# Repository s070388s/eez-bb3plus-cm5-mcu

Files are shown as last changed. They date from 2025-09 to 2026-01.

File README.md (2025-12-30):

### This is a WORK IN PROGRESS!

---

### Ownership and License
The contributors are listed in CONTRIB.TXT. 

### Overview

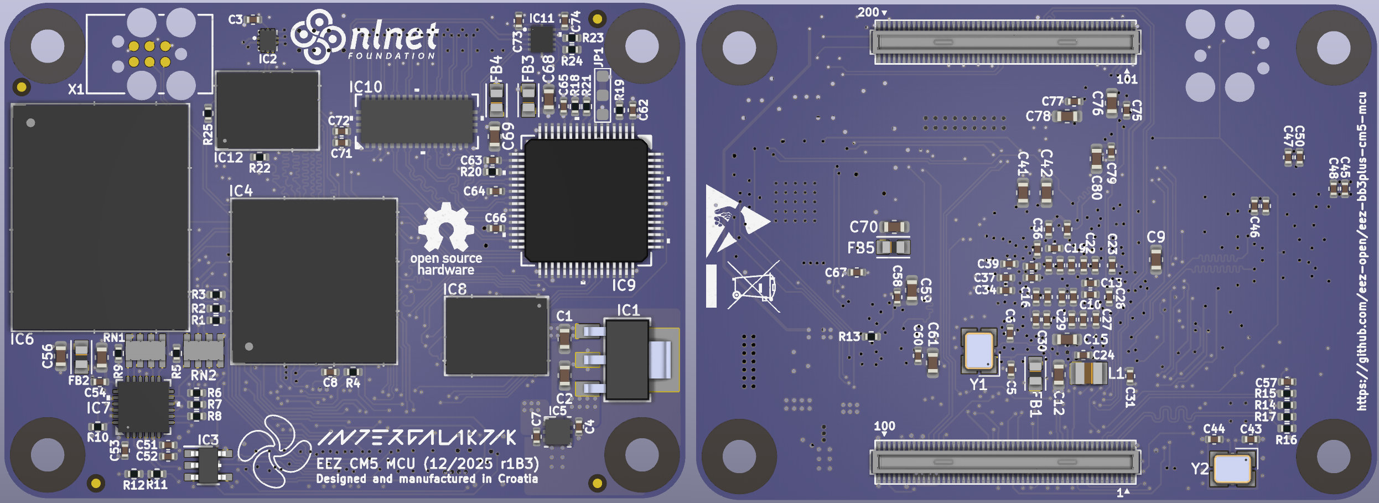
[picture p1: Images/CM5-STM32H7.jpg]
3D model


The MCU module uses a high performance STM32 MCU and is pin compatible with Raspberry Pi CM5. The MCU cannot generate an HDMI compatible signal, so a TI TFP410 is used to convert 24-bit RGB to HDMI compatible signal. Since the BB3+ offers dual display: a built-in 5" TFT touchscreen and an external monitor, a 1:2 high speed mux (TS3DV642) is used for destination selection.

### Feature list

* [Raspberry Pi CM5](https://www.raspberrypi.com/products/compute-module-5) form factor (55 x 45 mm)
* [STM32H7R7L8H6H](https://www.st.com/en/microcontrollers-microprocessors/stm32h7r7l8.html) 32-bit High-Performance Arm Cortex-M7 MCU, 600 MHz, NeoChrom GPU
* 32 MB PSRAM
* 32 MB Flash memory
* 4 GB eMMC (100-pin FBGA)
* Two USB ports (1x FS with 1:2 Mux , 1x FS/HS)
* 10/100 Mbps Ethernet
* 24-bit color video output with 1:2 MUX (HDMI® compatible)
* 6-layer PCB (without buried/blind vias)

### Related topics and links

* Intergalaktik [BB3-CM4](https://intergalaktik.eu/projects/bb3-cm4)
* [EEZ BB3+](https://github.com/eez-open/eez-bb3plus)
* [DIB DCP405+](https://github.com/eez-open/dib-dcp405plus) power module
* [EEZ BB3](https://github.com/eez-open/modular-psu)
* [EEZ Studio](https://www.envox.eu/studio/studio-introduction)
* [Discord](https://discord.com/invite/q5KAeeenNG) server
* [X](https://x.com/envox) (ex Twitter)
* [YouTube](https://www.youtube.com/c/eezopen) channel
* [EEVblog forum](https://www.eevblog.com/forum/projects/eez-h25005-a-possible-successor-of-eez-h24005-programmable-power-supply/) discussion

---

This work is financed by [NLnet](https://nlnet.nl/project/BB3-CM5/) foundation

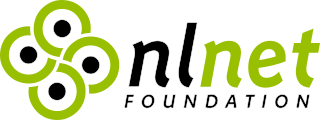
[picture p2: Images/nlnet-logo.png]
nlnet


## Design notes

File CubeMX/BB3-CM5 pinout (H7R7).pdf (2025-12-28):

BB3+ CM5 STM32H7R7 pinout

Pin Nb | PINs | FUNCTIONs | LABELs | NOTE
A2 | PE0 | GPIO_EXTI0 | SYSMCU_IRQ
A3 | PF3 | GPIO_EXTI3 | DIB3_IRQ
A4 | PF2 | GPIO_EXTI2 | DIB2_IRQ
A5 | PG3 | GPIO_Output | DIB_OE_SYNC
A7 | PM12 | USB_OTG_FS_DM
A9 | PM6 | USB_OTG_HS_DP
A10 PM3 | | GPIO_Output | DIB3_CSA
A12 PD3 | | LTDC_B1
A13 PE14 | | SPI4_MOSI | DIB2/DIB5_MOSI
A14 PD2 | | SDMMC1_CMD
B1 | PB8 | SDMMC1_D4
B2 | PE2 | SPI4_SCK | DIB2/DIB5_SCK
B3 | PB5 | LTDC_R2
B4 | PF4 | GPIO_EXTI4 | DIB4_IRQ
B5 | PF0 | I2C2_SDA | SDA
B6 | PD7 | ETH_RMII_REF_CLK
B7 | PM11 | USB_OTG_FS_DP
B8 | PM9 | USB_OTG_HS_ID
B9 | PM5 | USB_OTG_HS_DM
B10 PM2 | GPIO_Input | DIN2
B11 PG0 | | LTDC_R7
B12 PE13 | | SPI4_MISO | DIB2/DIB5_MISO
B13 PD1 | | UART4_TX | RS485_TX/DOUT3
B14 PC10 | | SDMMC1_D2
B15 PC11 | | SDMMC1_D3
C2 | PB9 | SDMMC1_D5
C4 | PB3(JTDO/TRACESWO) | LTDC_R4
C5 | PF1 | I2C2_SCL | SCL
C6 | PG2 | LTDC_HSYNC
C7 | PM13 | SPI5_MOSI | DIB4_MOSI
C8 | PM14 | SPI5_MISO | DIB4_MISO
C9 | PM8 | USB_OTG_HS_VBUS
C12 PE11 | | LTDC_VSYNC
C13 PD0 | | UART4_RX | RS485_RX/DIN3
C14 PA12 | | SPI2_SCK | DIB1/DIB3_SCK
C15 PA11 | | LTDC_B3
D2 | PC14-OSC32_IN(OSC32_IN) RCC_OSC32_IN
D4 | PB7 | ETH_RMII_TXD1
D5 | PB4(NJTRST) | SPI2_NSS | DIB1_CSA
D7 | PD5 | GPIO_EXTI5 | DIB5_IRQ
D11 PE15 | | GPIO_Output | LCD_ON
D12 PC12 | | SDMMC1_CK
D13 PA14(JTCK/SWCLK) | DEBUG_JTCK-SWCLK | SWCLK
D14 PA9 | | LTDC_B5
D15 PC8 | | SDMMC1_D0
E1 | PE6 | GPIO_Output | DIB5_CSA
E2 | PE4 | SPI4_NSS | DIB2_CSA
E5 | PB6* | CEC | DVID_CEC
E7 | PD6 | ETH_CLK
E10 PG1 | | LTDC_R6
E11 PE12 | | GPIO_EXTI12 | DVID_HPA
E12 PA13(JTMS/SWDIO) | DEBUG_JTMS-SWDIO | SWDIO
E13 PA10 | | LTDC_B4
E14 PC9 | | SDMMC1_D1
E15 PC6 | | SDMMC1_D6
F1 | PG14 | GPIO_Output | SYSMCU_CS
F2 | PG12 | LTDC_G1

F3 | PG11 | ETH_RMII_TX_EN
F12 PA8 | LTDC_B6
F13 PC7 | SDMMC1_D7
F14 PN1 | XSPIM_P2_NCS1
G5 PG13 | ETH_RMII_TXD0
G11 PA15(JTDI) | LTDC_R5
G13 PN3 | XSPIM_P2_IO1
G14 PN0 | XSPIM_P2_DQS0
G15 PN11 | XSPIM_P2_IO7
H4 | PF7 | UART7_TX | UART_TX/DOUT1
H5 | PF6 | SPI5_NSS | DIB4_CSA
H13 PN10 | XSPIM_P2_IO6
H14 PN9 | XSPIM_P2_IO5
H15 PN2 | XSPIM_P2_IO0
J2 | PF9 | LTDC_R0
J3 | PF10 | LTDC_R1
J14 PN6 | XSPIM_P2_CLK
K1 | PH0-OSC_IN(PH0) | RCC_OSC_IN
K2 | PH1-OSC_OUT(PH1) | RCC_OSC_OUT
K13 PN8 | XSPIM_P2_IO4
K14 PN4 | XSPIM_P2_IO2
K15 PN5 | XSPIM_P2_IO3
L1 | PC1 | ETH_MDC
L2 | PC2 | SPI2_MISO | DIB1/DIB3_MISO
L3 | PC3 | SPI2_MOSI | DIB1/DIB3_MOSI
L4 | PA2 | ETH_MDIO
L5 | PC4 | ETH_RMII_RXD0
L12 PB12 | LTDC_G5
L14 PD14 | GPIO_Output | USB_FS_SEL
M1 PA0 | LTDC_G3
M2 PA1 | LTDC_G2
M3 PA4 | LTDC_R3
M4 PA7 | ETH_RMII_CRS_DV
M5 PF11 | LTDC_B0
M6 PE7 | UART7_RX | UART_RX/DIN1
M11 PO3 | XSPIM_P1_DQS1
M12 PP10 | XSPIM_P1_IO10
M13 PB14 | UART4_DE | RS485_TX_EN/DOUT2
M14 PB15 | LTDC_G7
N1 | PA3 | LTDC_DE
N2 | PA5 | LTDC_CLK
N3 | PC5 | ETH_RMII_RXD1
N4 | PB2 | LTDC_B2
N5 | PF15 | SPI5_SCK | DIB4_SCK
N6 | PP12 | XSPIM_P1_IO12
N7 | PP14 | XSPIM_P1_IO14
N9 | PP2 | XSPIM_P1_IO2
N10 PP5 | XSPIM_P1_IO5
N11 PO2 | XSPIM_P1_DQS0
N12 PP1 | XSPIM_P1_IO1
N14 PB11 | LTDC_G6
N15 PB13 | LTDC_G4
P1 | PA6 | LTDC_B7
P2 | PB0 | GPIO_Output | DVID_SEL1
P3 | PF13 | GPIO_Output | DVID_SEL2
P4 | PF14 | LTDC_G0
P6 | PP11 | XSPIM_P1_IO11
P8 | PP15 | XSPIM_P1_IO15

P9 | PP3 | XSPIM_P1_IO3
P11 PP0 | XSPIM_P1_IO0
P12 PP7 | XSPIM_P1_IO7
P13 PP8 | XSPIM_P1_IO8
P15 PB10 | ETH_MII_RX_ER
R2 | PB1 | GPIO_EXTI1 | DIB1_IRQ
R4 | PE8 | GPIO_EXTI8 | TFT_IRQ
R5 | PE10 | GPIO_Output | LED_nACT
R7 | PP13 | XSPIM_P1_IO13
R8 | PP4 | XSPIM_P1_IO4
R10 PO4 | XSPIM_P1_CLK
R11 PP6 | XSPIM_P1_IO6
R13 PO0 | XSPIM_P1_NCS1
R14 PP9 | XSPIM_P1_IO9

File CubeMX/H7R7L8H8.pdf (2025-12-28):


28/12/2025

## H7R7L8H8 Project Configuration Report

# 1. Description

## 1.1. Project

Project Name | H7R7L8H8
Board Name | custom
Generated with: | STM32CubeMX 6.16.0
Date | 12/28/2025

## 1.2. MCU

MCU Series | STM32H7RS
MCU Line | STM32H7R7/7S7
MCU name | STM32H7R7L8HxH
MCU Package | TFBGA225 HEXA SMPS
MCU Pin number | 225

## 1.3. Core(s) information

Core(s) | ARM Cortex-M7

# 2. Pinout Configuration

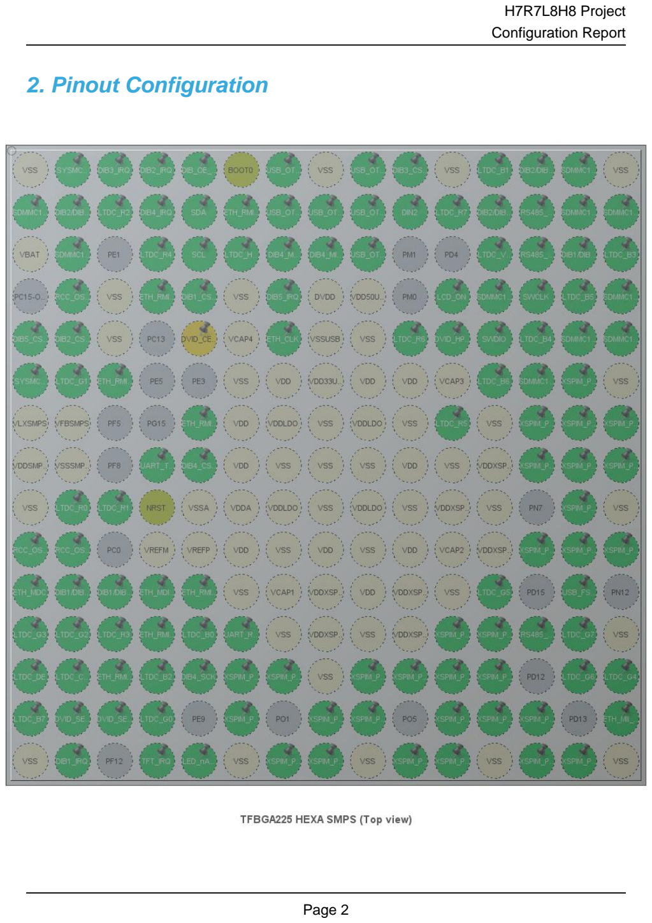
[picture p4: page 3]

# 3. Pins Configuration

Pin Number TFBGA225 HEXA SMPS | Pin Name (function after reset) | Pin Type | Alternate Function(s) | Label
A1 | VSS | Power
A2 | PE0 | I/O | GPIO_EXTI0 | SYSMCU_IRQ
A3 | PF3 | I/O | GPIO_EXTI3 | DIB3_IRQ
A4 | PF2 | I/O | GPIO_EXTI2 | DIB2_IRQ
A5 | PG3 * | I/O | GPIO_Output | DIB_OE_SYNC
A6 | BOOT0 | Boot
A7 | PM12 | I/O | USB_OTG_FS_DM
A8 | VSS | Power
A9 | PM6 | I/O | USB_OTG_HS_DP
A10 | PM3 * | I/O | GPIO_Output | DIB3_CSA
A11 | VSS | Power
A12 | PD3 | I/O | LTDC_B1
A13 | PE14 | I/O | SPI4_MOSI | DIB2/DIB5_MOSI
A14 | PD2 | I/O | SDMMC1_CMD
A15 | VSS | Power
B1 | PB8 | I/O | SDMMC1_D4
B2 | PE2 | I/O | SPI4_SCK | DIB2/DIB5_SCK
B3 | PB5 | I/O | LTDC_R2
B4 | PF4 | I/O | GPIO_EXTI4 | DIB4_IRQ
B5 | PF0 | I/O | I2C2_SDA | SDA
B6 | PD7 | I/O | ETH_RMII_REF_CLK
B7 | PM11 | I/O | USB_OTG_FS_DP
B8 | PM9 | I/O | USB_OTG_HS_ID
B9 | PM5 | I/O | USB_OTG_HS_DM
B10 | PM2 * | I/O | GPIO_Input | DIN2
B11 | PG0 | I/O | LTDC_R7
B12 | PE13 | I/O | SPI4_MISO | DIB2/DIB5_MISO
B13 | PD1 | I/O | UART4_TX | RS485_TX/DOUT3
B14 | PC10 | I/O | SDMMC1_D2
B15 | PC11 | I/O | SDMMC1_D3
C1 | VBAT | Power
C2 | PB9 | I/O | SDMMC1_D5
C4 | PB3(JTDO/TRACESWO) | I/O | LTDC_R4
C5 | PF1 | I/O | I2C2_SCL | SCL
C6 | PG2 | I/O | LTDC_HSYNC
C7 | PM13 | I/O | SPI5_MOSI | DIB4_MOSI

Pin Number TFBGA225 HEXA SMPS | Pin Name (function after reset) | Pin Type | Alternate Function(s) | Label
C8 | PM14 | I/O | SPI5_MISO | DIB4_MISO
C9 | PM8 | I/O | USB_OTG_HS_VBUS
C12 | PE11 | I/O | LTDC_VSYNC
C13 | PD0 | I/O | UART4_RX | RS485_RX/DIN3
C14 | PA12 | I/O | SPI2_SCK | DIB1/DIB3_SCK
C15 | PA11 | I/O | LTDC_B3
D2 | PC14-OSC32_IN(OSC32_IN) | I/O | RCC_OSC32_IN
D3 | VSS | Power
D4 | PB7 | I/O | ETH_RMII_TXD1
D5 | PB4(NJTRST) | I/O | SPI2_NSS | DIB1_CSA
D6 | VSS | Power
D7 | PD5 | I/O | GPIO_EXTI5 | DIB5_IRQ
D8 | DVDD | Power
D9 | VDD50USB | Power
D11 | PE15 * | I/O | GPIO_Output | LCD_ON
D12 | PC12 | I/O | SDMMC1_CK
D13 | PA14(JTCK/SWCLK) | I/O | DEBUG_JTCK-SWCLK | SWCLK
D14 | PA9 | I/O | LTDC_B5
D15 | PC8 | I/O | SDMMC1_D0
E1 | PE6 * | I/O | GPIO_Output | DIB5_CSA
E2 | PE4 | I/O | SPI4_NSS | DIB2_CSA
E3 | VSS | Power
E5 | PB6 ** | I/O | CEC | DVID_CEC
E6 | VCAP4 | Power
E7 | PD6 | I/O | ETH_CLK
E8 | VSSUSB | Power
E9 | VSS | Power
E10 | PG1 | I/O | LTDC_R6
E11 | PE12 | I/O | GPIO_EXTI12 | DVID_HPA
E12 | PA13(JTMS/SWDIO) | I/O | DEBUG_JTMS-SWDIO | SWDIO
E13 | PA10 | I/O | LTDC_B4
E14 | PC9 | I/O | SDMMC1_D1
E15 | PC6 | I/O | SDMMC1_D6
F1 | PG14 * | I/O | GPIO_Output | SYSMCU_CS
F2 | PG12 | I/O | LTDC_G1
F3 | PG11 | I/O | ETH_RMII_TX_EN
F6 | VSS | Power
F7 | VDD | Power

Pin Number TFBGA225 HEXA SMPS | Pin Name (function after reset) | Pin Type | Alternate Function(s) | Label
F8 | VDD33USB | Power
F9 | VDD | Power
F10 | VDD | Power
F11 | VCAP3 | Power
F12 | PA8 | I/O | LTDC_B6
F13 | PC7 | I/O | SDMMC1_D7
F14 | PN1 | I/O | XSPIM_P2_NCS1
F15 | VSS | Power
G1 | VLXSMPS | Power
G2 | VFBSMPS | Power
G5 | PG13 | I/O | ETH_RMII_TXD0
G6 | VDD | Power
G7 | VDDLDO | Power
G8 | VSS | Power
G9 | VDDLDO | Power
G10 | VSS | Power
G11 | PA15(JTDI) | I/O | LTDC_R5
G12 | VSS | Power
G13 | PN3 | I/O | XSPIM_P2_IO1
G14 | PN0 | I/O | XSPIM_P2_DQS0
G15 | PN11 | I/O | XSPIM_P2_IO7
H1 | VDDSMPS | Power
H2 | VSSSMPS | Power
H4 | PF7 | I/O | UART7_TX | UART_TX/DOUT1
H5 | PF6 | I/O | SPI5_NSS | DIB4_CSA
H6 | VDD | Power
H7 | VSS | Power
H8 | VSS | Power
H9 | VSS | Power
H10 | VDD | Power
H11 | VSS | Power
H12 | VDDXSPI2 | Power
H13 | PN10 | I/O | XSPIM_P2_IO6
H14 | PN9 | I/O | XSPIM_P2_IO5
H15 | PN2 | I/O | XSPIM_P2_IO0
J1 | VSS | Power
J2 | PF9 | I/O | LTDC_R0
J3 | PF10 | I/O | LTDC_R1
J4 | NRST | Reset

Pin Number TFBGA225 HEXA SMPS | Pin Name (function after reset) | Pin Type | Alternate Function(s) | Label
J5 | VSSA | Power
J6 | VDDA | Power
J7 | VDDLDO | Power
J8 | VSS | Power
J9 | VDDLDO | Power
J10 | VSS | Power
J11 | VDDXSPI2 | Power
J12 | VSS | Power
J14 | PN6 | I/O | XSPIM_P2_CLK
J15 | VSS | Power
K1 | PH0-OSC_IN(PH0) | I/O | RCC_OSC_IN
K2 | PH1-OSC_OUT(PH1) | I/O | RCC_OSC_OUT
K4 | VREFM | Power
K5 | VREFP | Power
K6 | VDD | Power
K7 | VSS | Power
K8 | VDD | Power
K9 | VSS | Power
K10 | VDD | Power
K11 | VCAP2 | Power
K12 | VDDXSPI2 | Power
K13 | PN8 | I/O | XSPIM_P2_IO4
K14 | PN4 | I/O | XSPIM_P2_IO2
K15 | PN5 | I/O | XSPIM_P2_IO3
L1 | PC1 | I/O | ETH_MDC
L2 | PC2 | I/O | SPI2_MISO | DIB1/DIB3_MISO
L3 | PC3 | I/O | SPI2_MOSI | DIB1/DIB3_MOSI
L4 | PA2 | I/O | ETH_MDIO
L5 | PC4 | I/O | ETH_RMII_RXD0
L6 | VSS | Power
L7 | VCAP1 | Power
L8 | VDDXSPI1 | Power
L9 | VDD | Power
L10 | VDDXSPI1 | Power
L11 | VSS | Power
L12 | PB12 | I/O | LTDC_G5
L14 | PD14 * | I/O | GPIO_Output | USB_FS_SEL
M1 | PA0 | I/O | LTDC_G3
M2 | PA1 | I/O | LTDC_G2

Pin Number TFBGA225 HEXA SMPS | Pin Name (function after reset) | Pin Type | Alternate Function(s) | Label
M3 | PA4 | I/O | LTDC_R3
M4 | PA7 | I/O | ETH_RMII_CRS_DV
M5 | PF11 | I/O | LTDC_B0
M6 | PE7 | I/O | UART7_RX | UART_RX/DIN1
M7 | VSS | Power
M8 | VDDXSPI1 | Power
M9 | VSS | Power
M10 | VDDXSPI1 | Power
M11 | PO3 | I/O | XSPIM_P1_DQS1
M12 | PP10 | I/O | XSPIM_P1_IO10
M13 | PB14 | I/O | UART4_DE | RS485_TX_EN/DOUT2
M14 | PB15 | I/O | LTDC_G7
M15 | VSS | Power
N1 | PA3 | I/O | LTDC_DE
N2 | PA5 | I/O | LTDC_CLK
N3 | PC5 | I/O | ETH_RMII_RXD1
N4 | PB2 | I/O | LTDC_B2
N5 | PF15 | I/O | SPI5_SCK | DIB4_SCK
N6 | PP12 | I/O | XSPIM_P1_IO12
N7 | PP14 | I/O | XSPIM_P1_IO14
N8 | VSS | Power
N9 | PP2 | I/O | XSPIM_P1_IO2
N10 | PP5 | I/O | XSPIM_P1_IO5
N11 | PO2 | I/O | XSPIM_P1_DQS0
N12 | PP1 | I/O | XSPIM_P1_IO1
N14 | PB11 | I/O | LTDC_G6
N15 | PB13 | I/O | LTDC_G4
P1 | PA6 | I/O | LTDC_B7
P2 | PB0 * | I/O | GPIO_Output | DVID_SEL1
P3 | PF13 * | I/O | GPIO_Output | DVID_SEL2
P4 | PF14 | I/O | LTDC_G0
P6 | PP11 | I/O | XSPIM_P1_IO11
P8 | PP15 | I/O | XSPIM_P1_IO15
P9 | PP3 | I/O | XSPIM_P1_IO3
P11 | PP0 | I/O | XSPIM_P1_IO0
P12 | PP7 | I/O | XSPIM_P1_IO7
P13 | PP8 | I/O | XSPIM_P1_IO8
P15 | PB10 | I/O | ETH_MII_RX_ER
R1 | VSS | Power

Pin Number TFBGA225 HEXA SMPS | Pin Name (function after reset) | Pin Type | Alternate Function(s) | Label
R2 | PB1 | I/O | GPIO_EXTI1 | DIB1_IRQ
R4 | PE8 | I/O | GPIO_EXTI8 | TFT_IRQ
R5 | PE10 * | I/O | GPIO_Output | LED_nACT
R6 | VSS | Power
R7 | PP13 | I/O | XSPIM_P1_IO13
R8 | PP4 | I/O | XSPIM_P1_IO4
R9 | VSS | Power
R10 | PO4 | I/O | XSPIM_P1_CLK
R11 | PP6 | I/O | XSPIM_P1_IO6
R12 | VSS | Power
R13 | PO0 | I/O | XSPIM_P1_NCS1
R14 | PP9 | I/O | XSPIM_P1_IO9
R15 | VSS | Power

## * The pin is affected with an I/O function ** The pin is affected with a peripheral function but no peripheral mode is activated

# 4. Clock Tree Configuration

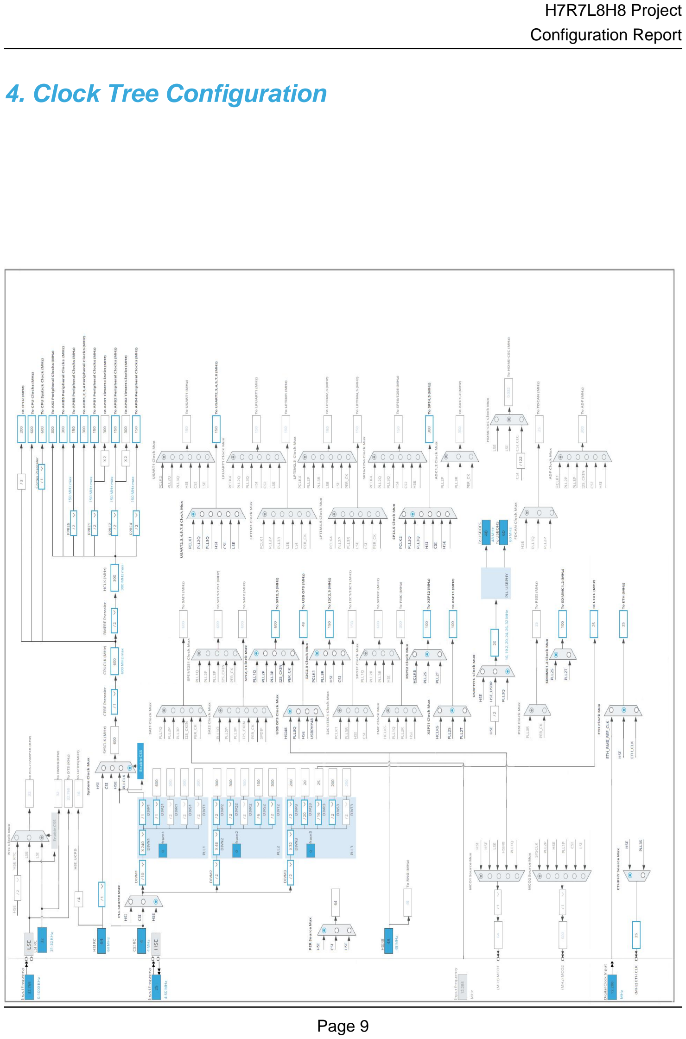
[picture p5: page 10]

# 1. Power Consumption Calculator report

## 1.1. Microcontroller Selection

Series | STM32H7
Line | STM32H7R7/7S7
MCU | STM32H7R7L8HxH
Datasheet | DS000000_Rev1

## 1.2. Parameter Selection

Temperature | 25
Vdd | 3.0

## 1.3. Battery Selection

Battery | Alkaline(9V)
Capacity | 625.0 mAh
Self Discharge | 0.3 %/month
Nominal Voltage | 9.0 V
Max Cont Current | 200.0 mA
Max Pulse Current | 0.0 mA
Cells in series | 1
Cells in parallel | 1

## 1.4. Sequence

Step | Step1 | Step2
Mode | RUN | STOP
Vdd | 3.0 | 3.0
Voltage Source | Battery | Battery
Range | VOS-HIGH | SVOS-LOW/SMPS
Fetch Type | AXISRAM3/FlashMode-ON/Cache/AlgoType-CoreMark | FLASH
CPU Frequency | 600 MHz | 0 Hz
Clock Configuration | HSE BYP PLL | ALL_CLOCKS_OFF
Clock Source Frequency | 8 MHz | 0 Hz

### Peripherals

Additional Cons. | 0 mA | 0 mA
Average Current | 130 mA | 265 µA
Duration | 0.1 ms | 0.9 ms
DMIPS | 1284.0 | 0.0
Ta Max | 107.45 | 124.96
Category | In DS Table | In DS Table

## 1.5. Results

Sequence Time | 1 ms | Average Current | 13.24 mA
Battery Life | 1 day, 23 hours | Average DMIPS | 128.40001 DMIPS

## 1.6. Chart

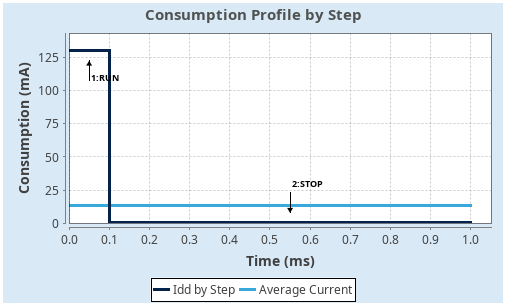
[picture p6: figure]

# 2. Software Project

## 2.1. Project Settings

Name | Value
Project Name | H7R7L8H8
Project Folder | /home/denis/BACKUP/EEZ/PCB/KiCad/BB3plus CM5 STM32H7
Toolchain / IDE | STM32CubeIDE
Firmware Package Name and Version | STM32Cube FW_H7RS V1.2.0
Application Structure | Advanced
Generate Under Root | Yes
Do not generate the main() | No
Minimum Heap Size | 0x1000
Minimum Stack Size | 0x1000

## 2.2. Code Generation Settings

Name | Value
STM32Cube MCU packages and embedded software | Copy only the necessary library files
Generate peripheral initialization as a pair of '.c/.h' files | No
Backup previously generated files when re-generating | No
Keep User Code when re-generating | Yes
Delete previously generated files when not re-generated | Yes
Set all free pins as analog (to optimize the power consumption) | No
Enable Full Assert | No

## 2.3. Advanced Settings - Generated Function Calls Boot

Rank | Function Name | Peripheral Instance Name
1 | SystemClock_Config | RCC
2 | MX_GPIO_Init | GPIO
3 | MX_FLASH_Init | FLASH
4 | MX_XSPI1_Init | XSPI1
5 | MX_XSPI2_Init | XSPI2
6 | MX_EXTMEM_MANAGER_Init | EXTMEM_MANAGER

## 2.4. Advanced Settings - Generated Function Calls Appli

Rank | Function Name | Peripheral Instance Name

Rank | Function Name | Peripheral Instance Name
1 | SystemClock_Config | RCC
2 | MX_GPIO_Init | GPIO
3 | MX_DMA2D_Init | DMA2D
4 | MX_ETH_Init | ETH
5 | MX_I2C2_Init | I2C2
6 | MX_JPEG_Init | JPEG
7 | MX_LTDC_Init | LTDC
8 | MX_SDMMC1_MMC_Init | SDMMC1
9 | MX_SPI2_Init | SPI2
10 | MX_SPI4_Init | SPI4
11 | MX_SPI5_Init | SPI5
12 | MX_UART7_Init | UART7
13 | MX_USB_OTG_FS_PCD_Init | USB_OTG_FS
14 | MX_USB_OTG_HS_PCD_Init | USB_OTG_HS
15 | MX_UART4_Init | UART4
16 | MX_FLASH_Init | FLASH

## 2.5. Advanced Settings - Generated Function Calls ExtMemLoader

Rank | Function Name | Peripheral Instance Name
1 | SystemClock_Config | RCC
2 | MX_EXTMEM_MANAGER_Init | EXTMEM_MANAGER

# 3. Peripherals and Middlewares Configuration

## 3.1. CORTEX_M7_APPLI

## 3.1.1. Parameter Settings:

### Speculation default mode Settings:

Speculation default mode | Disabled

### Cortex Interface Settings:

CPU ICache | Enabled *
CPU DCache | Enabled *

### Cortex Memory Protection Unit Control Settings:

MPU Control Mode | Background Region Privileged accesses only + MPU Disabled during hard fault, NMI and FAULTMASK handlers *

### Cortex Memory Protection Unit Region 0 Settings:

MPU Region | Enabled *
MPU Region Base Address | 0x0 *
MPU Region Size | 4GB *
MPU SubRegion Disable | 0x87 *
MPU TEX field level | level 0
MPU Access Permission | ALL ACCESS NOT PERMITTED
MPU Instruction Access | DISABLE *
MPU Shareability Permission | ENABLE *
MPU Cacheable Permission | DISABLE
MPU Bufferable Permission | DISABLE

### Cortex Memory Protection Unit Region 1 Settings:

MPU Region | Enabled *
MPU Region Base Address | 0x70000000 *
MPU Region Size | 32MB *
MPU SubRegion Disable | 0x0 *
MPU TEX field level | level 1 *
MPU Access Permission | ALL ACCESS PERMITTED *
MPU Instruction Access | DISABLE *
MPU Shareability Permission | DISABLE
MPU Cacheable Permission | ENABLE *
MPU Bufferable Permission | ENABLE *

### Cortex Memory Protection Unit Region 2 Settings:

MPU Region | Enabled *

MPU Region Base Address

| 0x70000000 *
MPU Region Size | 2MB *
MPU SubRegion Disable | 0x0 *
MPU TEX field level | level 1 *
MPU Access Permission | ALL ACCESS PERMITTED *
MPU Instruction Access | ENABLE
MPU Shareability Permission | DISABLE
MPU Cacheable Permission | ENABLE *
MPU Bufferable Permission | ENABLE *

### Cortex Memory Protection Unit Region 3 Settings:

MPU Region | Enabled *
MPU Region Base Address | 0x90000000 *
MPU Region Size | 32MB *
MPU SubRegion Disable | 0x0 *
MPU TEX field level | level 1 *
MPU Access Permission | ALL ACCESS PERMITTED *
MPU Instruction Access | DISABLE *
MPU Shareability Permission | DISABLE
MPU Cacheable Permission | DISABLE
MPU Bufferable Permission | DISABLE

### Cortex Memory Protection Unit Region 4 Settings:

MPU Region | Enabled *
MPU Region Base Address | 0x20000000 *
MPU Region Size | 64KB *
MPU SubRegion Disable | 0x0 *
MPU TEX field level | level 1 *
MPU Access Permission | ALL ACCESS PERMITTED *
MPU Instruction Access | DISABLE *
MPU Shareability Permission | DISABLE
MPU Cacheable Permission | DISABLE
MPU Bufferable Permission | DISABLE

### Cortex Memory Protection Unit Region 5 Settings:

MPU Region | Enabled *
MPU Region Base Address | 0x24000000 *
MPU Region Size | 512KB *
MPU SubRegion Disable | 0x0 *
MPU TEX field level | level 1 *

MPU Access Permission | ALL ACCESS PERMITTED *
MPU Instruction Access | DISABLE *
MPU Shareability Permission | ENABLE *
MPU Cacheable Permission | ENABLE *
MPU Bufferable Permission | ENABLE *

### Cortex Memory Protection Unit Region 6 Settings:

MPU Region | Enabled *
MPU Region Base Address | 0x2406c000 *
MPU Region Size | 16KB *
MPU SubRegion Disable | 0x0 *
MPU TEX field level | level 0
MPU Access Permission | ALL ACCESS PERMITTED *
MPU Instruction Access | DISABLE *
MPU Shareability Permission | ENABLE *
MPU Cacheable Permission | DISABLE
MPU Bufferable Permission | ENABLE *

### Cortex Memory Protection Unit Region 7 Settings:

MPU Region | Enabled *
MPU Region Base Address | 0x24070000 *
MPU Region Size | 8KB *
MPU SubRegion Disable | 0x0 *
MPU TEX field level | level 0
MPU Access Permission | ALL ACCESS PERMITTED *
MPU Instruction Access | DISABLE *
MPU Shareability Permission | ENABLE *
MPU Cacheable Permission | DISABLE
MPU Bufferable Permission | ENABLE *

### Cortex Memory Protection Unit Region 8 Settings:

MPU Region | Enabled *
MPU Region Base Address | 0x25000000 *
MPU Region Size | 16MB *
MPU SubRegion Disable | 0x0 *
MPU TEX field level | level 1 *
MPU Access Permission | ALL ACCESS PERMITTED *
MPU Instruction Access | DISABLE *
MPU Shareability Permission | DISABLE
MPU Cacheable Permission | DISABLE

MPU Bufferable Permission | DISABLE

### Cortex Memory Protection Unit Region 9 Settings:

MPU Region | Disabled

### Cortex Memory Protection Unit Region 10 Settings:

MPU Region | Disabled

### Cortex Memory Protection Unit Region 11 Settings:

MPU Region | Disabled

### Cortex Memory Protection Unit Region 12 Settings:

MPU Region | Disabled

### Cortex Memory Protection Unit Region 13 Settings:

MPU Region | Disabled

### Cortex Memory Protection Unit Region 14 Settings:

MPU Region | Disabled

### Cortex Memory Protection Unit Region 15 Settings:

MPU Region | Disabled

## 3.2. DEBUG Debug: Serial Wire

## 3.2.1. Core(s) Settings:

Context(s): | Boot

## Application

## 3.3. DMA2D mode: Activated

## 3.3.1. Parameter Settings:

### Basic Parameters:

Transfer Mode | Memory to Memory
Color Mode | ARGB8888
Output Offset | 0

### Foreground layer Configuration:

DMA2D Input Color Mode | ARGB8888
DMA2D ALPHA MODE | No modification of the alpha channel value
Input Alpha | 0
Input Offset | 0

DMA2D ALPHA Inversion | Regular Alpha
DMA2D Red and Blue swap | Regular mode (RGB or ARGB)
DMA2D Chroma Sub-Sampling Mode | No chroma sub-sampling 4:4:4

## 3.4. ETH Mode: RMII mode: Activate Rx Err signal

## 3.4.1. Parameter Settings:

### General : Ethernet Configuration:

Warning | The ETH can work only when RAM is pointing at 0x24000000
Ethernet MAC Address | 00:80:E1:00:00:00
Tx Descriptor Length | 4
First Tx Descriptor Address | 0x24020080 *
Rx Descriptor Length | 4
First Rx Descriptor Address | 0x24020000 *
Rx Buffers Address | 0x24020100 *
Rx Buffers Length | 1524

## 3.5. FLASH mode: Enable

## 3.5.1. Parameter Settings:

### BOR Level:

Activate | false

### User Configuration 1:

Activate | true *
IWDG_HW | enable *
NRST_STOP | no update
NRST_STDBY | no update
VDDIO_HSLV | no update
IWDG_FZ_STOP | no update
IWDG_FZ_SDBY | no update
XSPI1_HSLV | enable *
XSPI2_HSLV | enable *

### User Configuration 2:

Activate | true
ECC_ON_SRAM | no update
I2C_NI3C

### DTCM size configuration:

Activate | false

### ITCM size configuration:

Activate | false

### Write Protection:

Activate | false

### HDP Protection:

Activate | false

## 3.6. I2C2 I2C: I2C

## 3.6.1. Parameter Settings:

### Timing configuration:

I2C Speed Mode | Standard Mode
I2C Speed Frequency (KHz) | 100
Rise Time (ns) | 0
Fall Time (ns) | 0
Coefficient of Digital Filter | 0
Analog Filter | Enabled
Timing | 0x20C0EDFF *

### Slave Features:

Clock No Stretch Mode | Disabled
General Call Address Detection | Disabled
Primary Address Length selection | 7-bit
Dual Address Acknowledged | Disabled
Primary slave address | 0

## 3.7. JPEG mode: Activated

## 3.7.1. Parameter Settings:

### Version:

JPEG version | jpeg1_v1_0

### JPEG Software options:

ENCODE | Enabled
DECODE | Enabled
RGB_FORMAT | JPEG_ARGB8888
JPEG_SWAP_RG | 0

## 3.8. LTDC Display Type: RGB888 (24 bits)

## 3.8.1. Parameter Settings:

### Synchronization for Width:

Horizontal Synchronization Width | 16 *
Horizontal Back Porch | 8 *
Active Width | 800 *
Horizontal Front Porch | 8 *
HSync Width | 15
Accumulated Horizontal Back Porch Width | 23
Accumulated Active Width | 823
Total Width | 831

### Synchronization for Height:

Vertical Synchronization Height | 32 *
Vertical Back Porch | 16 *
Active Height | 480
Vertical Front Porch | 16 *
VSync Height | 31
Accumulated Vertical Back Porch Height | 47
Accumulated Active Height | 527
Total Height | 543

### Signal Polarity:

Horizontal Synchronization Polarity | Active Low
Vertical Synchronization Polarity | Active Low
Data Enable Polarity | Active Low
Pixel Clock Polarity | Normal Input

### Layer Default Color:

Red | 0
Green | 0
Blue | 0

## 3.8.2. Layer Settings:

### Layer Default Color:

Layer 0 - Alpha | 0
Layer 0 - Blue | 0
Layer 0 - Green | 0
Layer 0 - Red | 0

### Number of Layers:

Number of Layers | 1 layer *

### Windows Position:

Layer 0 - Window Horizontal Start | 0
Layer 0 - Window Horizontal Stop | 800 *
Layer 0 - Window Vertical Start | 0
Layer 0 - Window Vertical Stop | 480 *

### Pixel Parameters:

Layer 0 - Pixel Format | RGB888 *

### Blending:

Layer 0 - Alpha constant for blending | 255 *
Layer 0 - Blending Factor1 | Alpha constant
Layer 0 - Blending Factor2 | Alpha constant

### Frame Buffer:

Layer 0 - Color Frame Buffer Start Adress | 0x90000000 *
Layer 0 - Color Frame Buffer Line Length (Image Width) | 800 *
Layer 0 - Color Frame Buffer Number of Lines (Image Height) | 480 *

## 3.9. MEMORYMAP mode: Activated

## 3.9.1. Core(s) Settings:

Context(s): | Boot
Initialized Context: | Boot

Power Domain:

## 3.10. RCC High Speed Clock (HSE): Crystal/Ceramic Resonator Low Speed Clock (LSE) : BYPASS Clock Source mode: Digital Clock Input (ETH_RMII_REF_CLK) mode: Digital Clock Input (ETH_CLK)

## 3.10.1. Parameter Settings:

### Power Parameters:

SupplySource | PWR_DIRECT_SMPS_SUPPLY
Power Regulator Voltage Scale | Power Regulator Voltage Scale 0

### RCC Parameters:

TIM Prescaler Selection | Disabled
HSE Startup Timout Value (ms) | 100
LSE Startup Timout Value (ms) | 5000
HSI Calibration Value | 64

### System Parameters:

VDD voltage (V) | 3.3
Flash Latency(WS) | 7 WS (8 CPU cycle)

### PLL range Parameters:

PLL1 input frequency range | Between 2 and 4 MHz
PLL2 input frequency range | Between 8 and 16 MHz
PLL3 input frequency range | Between 8 and 16 MHz
PLL1 clock Output range | High VCO range
PLL2 clock Output range | High VCO range
PLL3 clock Output range | Wide VCO range

## 3.11. SDMMC1 Mode: MMC 8 bits Wide bus

## 3.11.1. Parameter Settings:

### SDMMC parameters:

Clock transition on which the bit capture is made | Rising transition
SDMMC Clock output enable when the bus is idle | Disable the power save for the clock
SDMMC hardware flow control | The hardware control flow is disabled
SDMMC clock divide factor | 0
Is external transceiver present ? | no

## 3.12. SPI2 Mode: Full-Duplex Master Hardware NSS Signal: Hardware NSS Output Signal

## 3.12.1. Parameter Settings:

### Basic Parameters:

Frame Format | Motorola
Data Size | 4 Bits
First Bit | MSB First

### Clock Parameters:

Prescaler (for Baud Rate) | 4 *
Baud Rate | 150.0 MBits/s *
Clock Polarity (CPOL) | Low
Clock Phase (CPHA) | 1 Edge

### CRC Parameters:

CRC Calculation | Disabled

### Advanced Parameters:

NSSP Mode | Enabled
NSS Signal Type | Output Hardware
Fifo Threshold | Fifo Threshold 01 Data
Nss Polarity | Nss Polarity Low
Master Ss Idleness | 00 Cycle
Master Inter Data Idleness | 00 Cycle
Master Receiver Auto Susp | Disable
Master Keep Io State | Master Keep Io State Disable
IO Swap | Disabled
Ready Master Management | Internal
Ready Signal Polarity | High

## 3.13. SPI4 Mode: Full-Duplex Master Hardware NSS Signal: Hardware NSS Output Signal

## 3.13.1. Parameter Settings:

### Basic Parameters:

Frame Format | Motorola

Data Size | 4 Bits
First Bit | MSB First

### Clock Parameters:

Prescaler (for Baud Rate) | 2
Baud Rate | 150.0 MBits/s *
Clock Polarity (CPOL) | Low
Clock Phase (CPHA) | 1 Edge

### CRC Parameters:

CRC Calculation | Disabled

### Advanced Parameters:

NSSP Mode | Enabled
NSS Signal Type | Output Hardware
Fifo Threshold | Fifo Threshold 01 Data
Nss Polarity | Nss Polarity Low
Master Ss Idleness | 00 Cycle
Master Inter Data Idleness | 00 Cycle
Master Receiver Auto Susp | Disable
Master Keep Io State | Master Keep Io State Disable
IO Swap | Disabled
Ready Master Management | Internal
Ready Signal Polarity | High

## 3.14. SPI5 Mode: Full-Duplex Master Hardware NSS Signal: Hardware NSS Output Signal

## 3.14.1. Parameter Settings:

### Basic Parameters:

Frame Format | Motorola
Data Size | 4 Bits
First Bit | MSB First

### Clock Parameters:

Prescaler (for Baud Rate) | 2
Baud Rate | 150.0 MBits/s *
Clock Polarity (CPOL) | Low
Clock Phase (CPHA) | 1 Edge

### CRC Parameters:

CRC Calculation | Disabled

### Advanced Parameters:

NSSP Mode | Enabled
NSS Signal Type | Output Hardware
Fifo Threshold | Fifo Threshold 01 Data
Nss Polarity | Nss Polarity Low
Master Ss Idleness | 00 Cycle
Master Inter Data Idleness | 00 Cycle
Master Receiver Auto Susp | Disable
Master Keep Io State | Master Keep Io State Disable
IO Swap | Disabled
Ready Master Management | Internal
Ready Signal Polarity | High

## 3.15. UART4 Mode: Asynchronous mode: Hardware Flow Control (RS485)

## 3.15.1. Parameter Settings:

### Basic Parameters:

Baud Rate | 115200
Word Length | 8 Bits (including Parity)
Parity | None
Stop Bits | 1

### Advanced Parameters:

Data Direction | Receive and Transmit
Over Sampling | 16 Samples
Single Sample | Disable
ClockPrescaler | 1
Fifo Mode | FIFO mode disable
Txfifo Threshold | 1 eighth full configuration
Rxfifo Threshold | 1 eighth full configuration
Polarity | High
Assertion Time | 0
Deassertion Time | 0

### Advanced Features:

Auto Baudrate | Disable
TX Pin Active Level Inversion | Disable
RX Pin Active Level Inversion | Disable
Data Inversion | Disable
TX and RX Pins Swapping | Disable
Overrun | Enable

DMA on RX Error | Enable
MSB First | Disable

## 3.16. UART7 Mode: Asynchronous

## 3.16.1. Parameter Settings:

### Basic Parameters:

Baud Rate | 115200
Word Length | 8 Bits (including Parity)
Parity | None
Stop Bits | 1

### Advanced Parameters:

Data Direction | Receive and Transmit
Over Sampling | 16 Samples
Single Sample | Disable
ClockPrescaler | 1
Fifo Mode | FIFO mode disable
Txfifo Threshold | 1 eighth full configuration
Rxfifo Threshold | 1 eighth full configuration

### Advanced Features:

Auto Baudrate | Disable
TX Pin Active Level Inversion | Disable
RX Pin Active Level Inversion | Disable
Data Inversion | Disable
TX and RX Pins Swapping | Disable
Overrun | Enable
DMA on RX Error | Enable
MSB First | Disable

## 3.17. USB_OTG_FS Mode: Device_Only

## 3.17.1. Parameter Settings:

Speed | Full Speed 12MBit/s
Low power | Disabled
Battery charging | Disabled
Link Power Management | Disabled

VBUS sensing | Disabled
Use dedicated end point 1 interrupt | Disabled
Signal start of frame | Disabled

## 3.18. USB_OTG_HS Internal HS Phy: OTG/Dual_Role_Device Activate_VBUS: Activate-VBUS

## 3.18.1. Parameter Settings:

### USB_OTG_Device_Configuration:

Speed_Device | Device High Speed 480MBit/s
Enable internal IP DMA Device | Disabled
Physical interface | Internal HS Phy
Low power | Disabled
Use dedicated endpoint 1 interrupt | Disabled
VBUS sensing | Enabled
Signal start of frame | Disabled

### USB_OTG_Host_Configuration:

Host Channels | 16
Speed_Host | Host High Speed 480MBit/s
Enable internal IP DMA Host | Disabled
Use external vbus | Enabled

### OTG PHY reference clock selection:

Ref Clock Selection | 16 Mhz

## 3.19. USB_OTG_HS1 mode: activate

## 3.19.1. Parameter Settings:

### Internal_Phy_Host:

Host Channels | 16
Speed_Host | High Speed 480MBit/s
Enable internal IP DMA Host | Disabled
Use external vbus | Enabled
Ref Clock Selection | 16 Mhz
Physical interface | Internal HS Phy

## 3.20. XSPI1 Mode: Hexa SPI Port: Port1 Hexa Chip Select Override: NCS1 -- Port1 --

## 3.20.1. Parameter Settings:

### Generic:

Fifo Threshold | 2 *
Memory Mode | Disable
Memory Type | 16BITS AP Memory *
Memory Size | 256 MBits *
Chip Select High Time Cycle | 5
Free Running Clock | Disable
Clock Mode | Low
Wrap Size | 32 Bytes *
Clock Prescaler | 0
Sample Shifting | None
Delay Hold Quarter Cycle | Enable *
Chip Select Boundary | 16 KBytes *
Maximum Transfer | 0
Refresh Rate | 400 *
Memory Select | NCS1

## 3.21. XSPI2 Mode: Octo SPI Port: Port2 Octo Chip Select Override: NCS1 -- Port2 --

## 3.21.1. Parameter Settings:

### Generic:

Fifo Threshold | 4 *
Memory Mode | Disable
Memory Type | Macronix *
Memory Size | 256 MBits *

Chip Select High Time Cycle | 2 *
Free Running Clock | Disable
Clock Mode | Low
Wrap Size | Not Supported
Clock Prescaler | 0
Sample Shifting | None
Delay Hold Quarter Cycle | Enable *
Chip Select Boundary | Disabled
Maximum Transfer | 0
Refresh Rate | 0
Memory Select | NCS1

## 3.22. EXTMEM_MANAGER mode: Activate External Memory Manager

## 3.22.1. Boot usecase:

### Boot:

select boot code generation | true *
Selection of the boot system | Execute In Place

### XIP:

select the memory | Memory 1

## 3.22.2. Memory 1:

### Select driver:

Select the memory driver | EXTMEM_NOR_SFDP

### Configuration:

Memory Instance | XSPI2 *
Number of memory data line | EXTMEM_LINK_CONFIG_8LIN ES *

## 3.22.3. Memory 2:

### Select driver:

Select the memory driver | EXTMEM_PSRAM *

### Configuration:

Memory Instance | XSPI1

Number of memory data line | EXTMEM_LINK_CONFIG_16LI NES *

### Memory Info:

Memory Size | HAL_XSPI_SIZE_256MB
Memory Maximun Frequency | 200

### Memory Command:

Read Register command | 0x40 *
Write Register command | 0xC0 *
Register Size | 2
MEMORY_1_RegDummyCycle | 4
Write Command | 0xA0 *
Write Dummy Cycle | 4
Read Command | 0x20 *
Wrap Read Command | 0x00 *
Read Dummy Cycle | 4

### Memory Configuration:

Number of Config | 1 *

### Configuration 1:

Write Mask | 0x40 *
Write Value | 0x40 *
Register Address | 0x08 *

### * User modified value

# 4. System Configuration

## 4.1. GPIO configuration

IP | Pin | Signal | GPIO mode | GPIO pull/up pull down

## Max Speed

## User Label

DEBUG | PA14(JTCK/ SWCLK) | DEBUG_JTCK- SWCLK
n/a | n/a | n/a | SWCLK
| PA13(JTMS/ SWDIO) | DEBUG_JTMS- SWDIO
n/a | n/a | n/a | SWDIO
ETH | PD7 | ETH_RMII_REF_ CLK | Alternate Function Push Pull | No pull-up and no pull-down | Low
PB7 | ETH_RMII_TXD1 Alternate Function Push Pull | No pull-up and no pull-down | Low
| PG11 | ETH_RMII_TX_E N | Alternate Function Push Pull | No pull-up and no pull-down | Low
PG13 | ETH_RMII_TXD0 Alternate Function Push Pull | No pull-up and no pull-down | Low
| PC1 | ETH_MDC | Alternate Function Push Pull | No pull-up and no pull-down | Low
| PA2 | ETH_MDIO | Alternate Function Push Pull | No pull-up and no pull-down | Low
| PC4 | ETH_RMII_RXD
| | 0 | Alternate Function Push Pull | No pull-up and no pull-down | Low
| PA7 | ETH_RMII_CRS _DV | Alternate Function Push Pull | No pull-up and no pull-down | Low
| PC5 | ETH_RMII_RXD
| | 1 | Alternate Function Push Pull | No pull-up and no pull-down | Low
| PB10 | ETH_MII_RX_E R | Alternate Function Push Pull | No pull-up and no pull-down | Low
I2C2 | PF0 | I2C2_SDA | Alternate Function Open Drain
No pull-up and no pull-down | Low | SDA
| PF1 | I2C2_SCL | Alternate Function Open Drain
No pull-up and no pull-down | Low | SCL
LTDC | PD3 | LTDC_B1 | Alternate Function Push Pull | No pull-up and no pull-down | Low
| PB5 | LTDC_R2 | Alternate Function Push Pull | No pull-up and no pull-down | Low
| PG0 | LTDC_R7 | Alternate Function Push Pull | No pull-up and no pull-down | Low
| PB3(JTDO/T RACESWO) | LTDC_R4 | Alternate Function Push Pull | No pull-up and no pull-down | Low
PG2 | LTDC_HSYNC Alternate Function Push Pull | No pull-up and no pull-down | Low
PE11 | LTDC_VSYNC Alternate Function Push Pull | No pull-up and no pull-down | Low
| PA11 | LTDC_B3 | Alternate Function Push Pull | No pull-up and no pull-down | Low
| PA9 | LTDC_B5 | Alternate Function Push Pull | No pull-up and no pull-down | Low
| PG1 | LTDC_R6 | Alternate Function Push Pull | No pull-up and no pull-down | Low
| PA10 | LTDC_B4 | Alternate Function Push Pull | No pull-up and no pull-down | Low
| PG12 | LTDC_G1 | Alternate Function Push Pull | No pull-up and no pull-down | Low
| PA8 | LTDC_B6 | Alternate Function Push Pull | No pull-up and no pull-down | Low
| PA15(JTDI) | LTDC_R5 | Alternate Function Push Pull | No pull-up and no pull-down | Low

IP | Pin | Signal | GPIO mode | GPIO pull/up pull down | Max Speed | User Label
| PF9 | LTDC_R0 | Alternate Function Push Pull | No pull-up and no pull-down | Low
| PF10 | LTDC_R1 | Alternate Function Push Pull | No pull-up and no pull-down | Low
| PB12 | LTDC_G5 | Alternate Function Push Pull | No pull-up and no pull-down | Low
| PA0 | LTDC_G3 | Alternate Function Push Pull | No pull-up and no pull-down | Low
| PA1 | LTDC_G2 | Alternate Function Push Pull | No pull-up and no pull-down | Low
| PA4 | LTDC_R3 | Alternate Function Push Pull | No pull-up and no pull-down | Low
| PF11 | LTDC_B0 | Alternate Function Push Pull | No pull-up and no pull-down | Low
| PB15 | LTDC_G7 | Alternate Function Push Pull | No pull-up and no pull-down | Low
| PA3 | LTDC_DE | Alternate Function Push Pull | No pull-up and no pull-down | Low
| PA5 | LTDC_CLK | Alternate Function Push Pull | No pull-up and no pull-down | Low
| PB2 | LTDC_B2 | Alternate Function Push Pull | No pull-up and no pull-down | Low
| PB11 | LTDC_G6 | Alternate Function Push Pull | No pull-up and no pull-down | Low
| PB13 | LTDC_G4 | Alternate Function Push Pull | No pull-up and no pull-down | Low
| PA6 | LTDC_B7 | Alternate Function Push Pull | No pull-up and no pull-down | Low
| PF14 | LTDC_G0 | Alternate Function Push Pull | No pull-up and no pull-down | Low
RCC | PC14-OSC32_IN( OSC32_IN) | RCC_OSC32_IN | n/a | n/a | n/a
| PD6 | ETH_CLK | Alternate Function Push Pull | No pull-up and no pull-down | Low
| PH0-OSC_IN(PH 0) | RCC_OSC_IN | n/a | n/a | n/a
| PH1-OSC_OUT(P H1) | RCC_OSC_OUT | n/a | n/a | n/a
SDMMC1 | PD2 | SDMMC1_CMD | Alternate Function Push Pull | No pull-up and no pull-down | Very High
| PB8 | SDMMC1_D4 | Alternate Function Push Pull | No pull-up and no pull-down | Very High
| PC10 | SDMMC1_D2 | Alternate Function Push Pull | No pull-up and no pull-down | Very High
| PC11 | SDMMC1_D3 | Alternate Function Push Pull | No pull-up and no pull-down | Very High
| PB9 | SDMMC1_D5 | Alternate Function Push Pull | No pull-up and no pull-down | Very High
| PC12 | SDMMC1_CK | Alternate Function Push Pull | No pull-up and no pull-down | Very High
| PC8 | SDMMC1_D0 | Alternate Function Push Pull | No pull-up and no pull-down | Very High
| PC9 | SDMMC1_D1 | Alternate Function Push Pull | No pull-up and no pull-down | Very High
| PC6 | SDMMC1_D6 | Alternate Function Push Pull | No pull-up and no pull-down | Very High
| PC7 | SDMMC1_D7 | Alternate Function Push Pull | No pull-up and no pull-down | Very High
SPI2 | PA12 | SPI2_SCK | Alternate Function Push Pull | No pull-up and no pull-down | Low | DIB1/DIB3_SCK
| PB4(NJTRS T) | SPI2_NSS | Alternate Function Push Pull | No pull-up and no pull-down | Low | DIB1_CSA
| PC2 | SPI2_MISO | Alternate Function Push Pull | No pull-up and no pull-down | Low | DIB1/DIB3_MISO
| PC3 | SPI2_MOSI | Alternate Function Push Pull | No pull-up and no pull-down | Low | DIB1/DIB3_MOSI
SPI4 | PE14 | SPI4_MOSI | Alternate Function Push Pull | No pull-up and no pull-down | Low | DIB2/DIB5_MOSI
| PE2 | SPI4_SCK | Alternate Function Push Pull | No pull-up and no pull-down | Low | DIB2/DIB5_SCK

IP | Pin | Signal | GPIO mode | GPIO pull/up pull down

## Max Speed

## User Label

| PE13 | SPI4_MISO | Alternate Function Push Pull | No pull-up and no pull-down | Low | DIB2/DIB5_MISO
| PE4 | SPI4_NSS | Alternate Function Push Pull | No pull-up and no pull-down | Low | DIB2_CSA
SPI5 | PM13 | SPI5_MOSI | Alternate Function Push Pull | No pull-up and no pull-down | Low | DIB4_MOSI
| PM14 | SPI5_MISO | Alternate Function Push Pull | No pull-up and no pull-down | Low | DIB4_MISO
| PF6 | SPI5_NSS | Alternate Function Push Pull | No pull-up and no pull-down | Low | DIB4_CSA
| PF15 | SPI5_SCK | Alternate Function Push Pull | No pull-up and no pull-down | Low | DIB4_SCK
UART4 | PD1 | UART4_TX | Alternate Function Push Pull | No pull-up and no pull-down | Low | RS485_TX/DOUT3
| PD0 | UART4_RX | Alternate Function Push Pull | No pull-up and no pull-down | Low | RS485_RX/DIN3
| PB14 | UART4_DE | Alternate Function Push Pull | No pull-up and no pull-down | Low | RS485_TX_EN/DOUT2
UART7 | PF7 | UART7_TX | Alternate Function Push Pull | No pull-up and no pull-down | Low | UART_TX/DOUT1
| PE7 | UART7_RX | Alternate Function Push Pull | No pull-up and no pull-down | Low | UART_RX/DIN1
USB_OTG_ FS | PM12 | USB_OTG_FS_ DM | n/a | n/a | n/a
| PM11 | USB_OTG_FS_ DP | n/a | n/a | n/a
USB_OTG_ HS | PM6 | USB_OTG_HS_ DP | Alternate Function Push Pull | No pull-up and no pull-down | Low
| PM9 | USB_OTG_HS_I D | Alternate Function Push Pull | No pull-up and no pull-down | Low
| PM5 | USB_OTG_HS_ DM | Alternate Function Push Pull | No pull-up and no pull-down | Low
| PM8 | USB_OTG_HS_ VBUS | Input mode | No pull-up and no pull-down | n/a
XSPI1 | PO3 | XSPIM_P1_DQS
| | 1 | Alternate Function Push Pull | No pull-up and no pull-down | Very High
PP10 | XSPIM_P1_IO10 Alternate Function Push Pull | No pull-up and no pull-down | Very High
PP12 | XSPIM_P1_IO12 Alternate Function Push Pull | No pull-up and no pull-down | Very High
PP14 | XSPIM_P1_IO14 Alternate Function Push Pull | No pull-up and no pull-down | Very High
PP2 | XSPIM_P1_IO2 Alternate Function Push Pull | No pull-up and no pull-down | Very High
PP5 | XSPIM_P1_IO5 Alternate Function Push Pull | No pull-up and no pull-down | Very High
| PO2 | XSPIM_P1_DQS
| | 0 | Alternate Function Push Pull | No pull-up and no pull-down | Very High
PP1 | XSPIM_P1_IO1 Alternate Function Push Pull | No pull-up and no pull-down | Very High
PP11 | XSPIM_P1_IO11 Alternate Function Push Pull | No pull-up and no pull-down | Very High
PP15 | XSPIM_P1_IO15 Alternate Function Push Pull | No pull-up and no pull-down | Very High
PP3 | XSPIM_P1_IO3 Alternate Function Push Pull | No pull-up and no pull-down | Very High
PP0 | XSPIM_P1_IO0 Alternate Function Push Pull | No pull-up and no pull-down | Very High
PP7 | XSPIM_P1_IO7 Alternate Function Push Pull | No pull-up and no pull-down | Very High
PP8 | XSPIM_P1_IO8 Alternate Function Push Pull | No pull-up and no pull-down | Very High
PP13 | XSPIM_P1_IO13 Alternate Function Push Pull | No pull-up and no pull-down | Very High
PP4 | XSPIM_P1_IO4 Alternate Function Push Pull | No pull-up and no pull-down | Very High
PO4 | XSPIM_P1_CLK Alternate Function Push Pull | No pull-up and no pull-down | Very High

IP | Pin | Signal | GPIO mode | GPIO pull/up pull down | Max Speed | User Label
| PP6 | XSPIM_P1_IO6 | Alternate Function Push Pull | No pull-up and no pull-down | Very High
| PO0 | XSPIM_P1_NCS 1 | Alternate Function Push Pull | No pull-up and no pull-down | Very High
| PP9 | XSPIM_P1_IO9 | Alternate Function Push Pull | No pull-up and no pull-down | Very High
XSPI2 | PN1 | XSPIM_P2_NCS 1 | Alternate Function Push Pull | No pull-up and no pull-down | Very High
| PN3 | XSPIM_P2_IO1 | Alternate Function Push Pull | No pull-up and no pull-down | Very High
| PN0 | XSPIM_P2_DQS 0 | Alternate Function Push Pull | No pull-up and no pull-down | Very High
| PN11 | XSPIM_P2_IO7 | Alternate Function Push Pull | No pull-up and no pull-down | Very High
| PN10 | XSPIM_P2_IO6 | Alternate Function Push Pull | No pull-up and no pull-down | Very High
| PN9 | XSPIM_P2_IO5 | Alternate Function Push Pull | No pull-up and no pull-down | Very High
| PN2 | XSPIM_P2_IO0 | Alternate Function Push Pull | No pull-up and no pull-down | Very High
| PN6 | XSPIM_P2_CLK | Alternate Function Push Pull | No pull-up and no pull-down | Very High
| PN8 | XSPIM_P2_IO4 | Alternate Function Push Pull | No pull-up and no pull-down | Very High
| PN4 | XSPIM_P2_IO2 | Alternate Function Push Pull | No pull-up and no pull-down | Very High
| PN5 | XSPIM_P2_IO3 | Alternate Function Push Pull | No pull-up and no pull-down | Very High
Single Mapped Signals | PB6 | CEC | Alternate Function Open Drain | No pull-up and no pull-down | Low | DVID_CEC
| | | Rising edge trigger detection | No pull-up and no pull-down | n/a | SYSMCU_IRQ
| PF3 | GPIO_EXTI3 | External Interrupt Mode with Rising edge trigger detection | No pull-up and no pull-down | n/a | DIB3_IRQ
| PF2 | GPIO_EXTI2 | External Interrupt Mode with Rising edge trigger detection | No pull-up and no pull-down | n/a | DIB2_IRQ
| PG3 | GPIO_Output | Output Push Pull | No pull-up and no pull-down | Low | DIB_OE_SYNC
| PM3 | GPIO_Output | Output Push Pull | No pull-up and no pull-down | Low | DIB3_CSA
| PF4 | GPIO_EXTI4 | External Interrupt Mode with Rising edge trigger detection | No pull-up and no pull-down | n/a | DIB4_IRQ
| PM2 | GPIO_Input | Input mode | No pull-up and no pull-down | n/a | DIN2
| PD5 | GPIO_EXTI5 | External Interrupt Mode with Rising edge trigger detection | No pull-up and no pull-down | n/a | DIB5_IRQ
| PE15 | GPIO_Output | Output Push Pull | No pull-up and no pull-down | Low | LCD_ON
| PE6 | GPIO_Output | Output Push Pull | No pull-up and no pull-down | Low | DIB5_CSA
| PE12 | GPIO_EXTI12 | External Interrupt Mode with Rising edge trigger detection | No pull-up and no pull-down | n/a | DVID_HPA
| PG14 | GPIO_Output | Output Push Pull | No pull-up and no pull-down | Low | SYSMCU_CS
| PD14 | GPIO_Output | Output Push Pull | No pull-up and no pull-down | Low | USB_FS_SEL
| PB0 | GPIO_Output | Output Push Pull | No pull-up and no pull-down | Low | DVID_SEL1
| PF13 | GPIO_Output | Output Push Pull | No pull-up and no pull-down | Low | DVID_SEL2
| PB1 | GPIO_EXTI1 | External Interrupt Mode with Rising edge trigger detection | No pull-up and no pull-down | n/a | DIB1_IRQ
GPIO | PE0 | GPIO_EXTI0 | External Interrupt Mode with

IP | Pin | Signal | GPIO mode | GPIO pull/up pull down | Max Speed | User Label
| PE8 | GPIO_EXTI8 | External Interrupt Mode with Rising edge trigger detection | No pull-up and no pull-down | n/a | TFT_IRQ
| PE10 | GPIO_Output | Output Push Pull | No pull-up and no pull-down | Low | LED_nACT

## 4.2. GPDMA1

## 4.2.1. Core(s) Settings:

Context(s): | Boot Application ExternalMemoryLoader
Initialized Context: | ExternalMemoryLoader

Power Domain:

## 4.3. HPDMA1

## 4.3.1. Core(s) Settings:

Context(s): | Boot Application ExternalMemoryLoader
Initialized Context: | ExternalMemoryLoader

Power Domain:

## 4.4. LINKEDLIST

## 4.4.1. Core(s) Settings:

Context(s): | Boot Application ExternalMemoryLoader
Initialized Context: | ExternalMemoryLoader

Power Domain:

## 4.5. NVIC configuration

## 4.5.1. NVIC1

Interrupt Table | Enable | Preenmption Priority | SubPriority
Non maskable interrupt | true | 0 | 0
Hard fault interrupt | true | 0 | 0
Memory management fault | true | 0 | 0
Pre-fetch fault, memory access fault | true | 0 | 0
Undefined instruction or illegal state | true | 0 | 0
System service call via SWI instruction | true | 0 | 0
Debug monitor | true | 0 | 0
Pendable request for system service | true | 0 | 0
System tick timer | true | 15 | 0
LTDC global interrupt | true | 0 | 0
PVD and PVM interrupts through EXTI line | unused
RCC global interrupt | unused
FLASH interrupts | unused
FPU global interrupt | unused
EXTI line0 interrupt | unused
EXTI line1 interrupt | unused
EXTI line2 interrupt | unused
EXTI line3 interrupt | unused
EXTI line4 interrupt | unused
EXTI line5 interrupt | unused
EXTI line8 interrupt | unused
EXTI line12 interrupt | unused
SPI2 global interrupt | unused
SPI4 global interrupt | unused
SPI5 global interrupt | unused
I2C2 event interrupt | unused
I2C2 error interrupt | unused
UART4 global interrupt | unused
UART7 global interrupt | unused
USB OTG HS interrupt | unused
Ethernet global interrupt | unused
LTDC Error global Interrupt | unused
DMA2D global interrupt | unused
JPEG global interrupt | unused
SDMMC1 global interrupt | unused
USB OTG FS interrupt | unused
USB OTG HS Host interrupt | unused

## 4.5.2. NVIC1 Code generation

Enabled interrupt Table | Select for init sequence ordering | Generate IRQ handler | Call HAL handler
Non maskable interrupt | false | true | false
Hard fault interrupt | false | true | false
Memory management fault | false | true | false
Pre-fetch fault, memory access fault | false | true | false
Undefined instruction or illegal state | false | true | false
System service call via SWI instruction | false | true | false
Debug monitor | false | true | false
Pendable request for system service | false | true | false
System tick timer | false | true | true
LTDC global interrupt | false | true | true

## 4.5.3. NVIC2

Interrupt Table | Enable | Preenmption Priority | SubPriority
Non maskable interrupt | true | 0 | 0
Hard fault interrupt | true | 0 | 0
Memory management fault | true | 0 | 0
Pre-fetch fault, memory access fault | true | 0 | 0
Undefined instruction or illegal state | true | 0 | 0
System service call via SWI instruction | true | 0 | 0
Debug monitor | true | 0 | 0
Pendable request for system service | true | 0 | 0
System tick timer | true | 15 | 0
PVD and PVM interrupts through EXTI line | unused
RCC global interrupt | unused
FLASH interrupts | unused
FPU global interrupt | unused
EXTI line0 interrupt | unused
EXTI line1 interrupt | unused
EXTI line2 interrupt | unused
EXTI line3 interrupt | unused
EXTI line4 interrupt | unused
EXTI line5 interrupt | unused
EXTI line8 interrupt | unused
EXTI line12 interrupt | unused
XSPI1 global interrupt | unused
XSPI2 global interrupt | unused

## 4.5.4. NVIC2 Code generation

Enabled interrupt Table | Select for init sequence ordering | Generate IRQ handler | Call HAL handler
Non maskable interrupt | false | true | false
Hard fault interrupt | false | true | false
Memory management fault | false | true | false
Pre-fetch fault, memory access fault | false | true | false
Undefined instruction or illegal state | false | true | false
System service call via SWI instruction | false | true | false
Debug monitor | false | true | false
Pendable request for system service | false | true | false
System tick timer | false | true | true

### * User modified value

# 5. System Views

## 5.1. Category view 5.1.1. Current

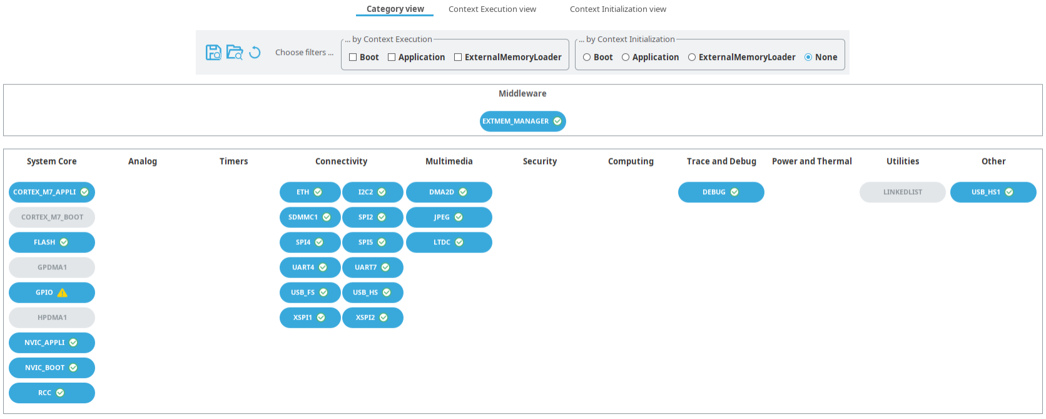
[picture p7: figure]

## 5.1.2. Without filters

## 5.2. Context Execution view

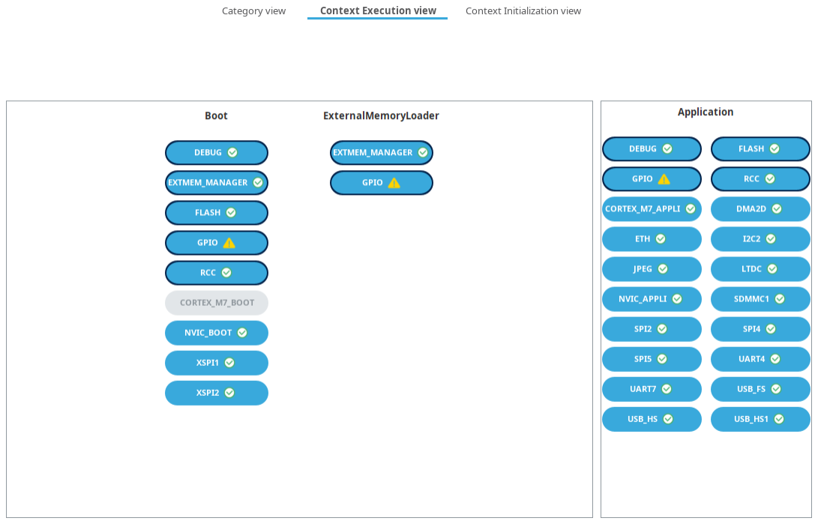
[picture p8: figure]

## 5.3. Context Initialization view

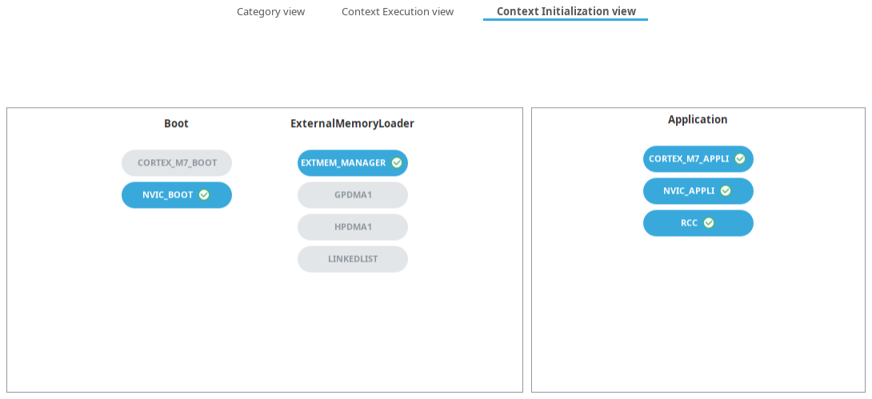
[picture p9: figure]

# 6. Docs & Resources

Type | Link
BSDL files | https://www.st.com/resource/en/bsdl_model/stm32h7_bsdl.zip
IBIS models | https://www.st.com/resource/en/ibis_model/stm32h7_ibis.zip
System View Description | https://www.st.com/resource/en/svd/stm32h7rs-svd.zip
Presentations | https://www.st.com/resource/en/product_presentation/microcontrollers_stm32h7_series_product_overview.pdf
Presentations | https://www.st.com/resource/en/product_presentation/stm32-stm8_embedded_software_solutions.pdf
Presentations | https://www.st.com/resource/en/product_presentation/stm32_eval-tools_portfolio.pdf
Presentations | https://www.st.com/resource/en/product_presentation/stm32_stm8_functi onal-safety-packages.pdf
Presentations | https://www.st.com/resource/en/product_presentation/stm32-stm8_software_development_tools.pdf
Presentations | https://www.st.com/resource/en/product_presentation/microcontrollers-stm32-family-overview.pdf
Presentations | https://www.st.com/resource/en/product_presentation/microcontrollers-stm32h7rs-lines-overview.pdf
Presentations | https://www.st.com/resource/en/product_presentation/stm32-graphics-solution-overview.pdf
Presentations | https://www.st.com/resource/en/product_presentation/stm32-graphics-solutions-detailed.pdf
Flyers | https://www.st.com/resource/en/flyer/flstm32nucleo.pdf
Flyers | https://www.st.com/resource/en/flyer/flstm32trust.pdf
Flyers | https://www.st.com/resource/en/flyer/flstm32h7rs.pdf
Security Bulletin | https://www.st.com/resource/en/technical_note/tn1489-security-bulletin-tn1489stpsirt-physical-attacks-on-stm32-and-stm32cube-firmware-stmicroelectronics.pdf
Security Bulletin | https://www.st.com/resource/en/security_bulletin/sb0023-eucleak-

| protection-statement-for-stmicroelectronics-certified-products-stmicroelectronics.pdf
Application Notes | https://www.st.com/resource/en/application_note/an1709-emc-design-guide-for-stm8-stm32-and-legacy-mcus-stmicroelectronics.pdf
Application Notes | https://www.st.com/resource/en/application_note/an3126-audio-and-waveform-generation-using-the-dac-in-stm32-products-stmicroelectronics.pdf
Application Notes | https://www.st.com/resource/en/application_note/an3155-usart-protocol-used-in-the-stm32-bootloader-stmicroelectronics.pdf
Application Notes | https://www.st.com/resource/en/application_note/an3156-usb-dfu-protocol-used-in-the-stm32-bootloader-stmicroelectronics.pdf
Application Notes | https://www.st.com/resource/en/application_note/an4221-i2c-protocol-used-in-the-stm32-bootloader-stmicroelectronics.pdf
Application Notes | https://www.st.com/resource/en/application_note/an4286-spi-protocol-used-in-the-stm32-bootloader-stmicroelectronics.pdf
Application Notes | https://www.st.com/resource/en/application_note/an4655-virtually-increasing-the-number-of-serial-communication-peripherals-in-stm32-applications-stmicroelectronics.p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
Application Notes | https://www.st.com/resource/en/application_note/an4750-handling-of-soft-errors-in-stm32-applications-stmicroelectronics.pdf
Application Notes | https://www.st.com/resource/en/application_note/an4776-generalpurpose-timer-cookbook-for-stm32-microcontrollers-stmicroelectronics.pdf
Application Notes | https://www.st.com/resource/en/application_note/an4803-highspeed-si-simulations-using-ibis-and-boardlevel-simulations-using-hyperlynx-si-on-stm32-mcus-and-mpus-stmic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
Application Notes | https://www.st.com/resource/en/application_note/an4839-level-1-cache-on-stm32f7-series-and-stm32h7-series-stmicroelectronics.pdf
Application Notes | https://www.st.com/resource/en/application_note/an4989-stm32-microcontroller-debug-toolbox-stmicroelectronics.pdf
Application Notes | https://www.st.com/resource/en/application_note/an4990-getting-started-with-sigmadelta-digital-interface-on-applicable-stm32-microcontrollers-stmicroelectronics.pdf
Application Notes | https://www.st.com/resource/en/application_note/an5027-interfacing-pdm-

| digital-microphones-using-stm32-mcus-and-mpus-stmicroelectronics.pdf
Application Notes | https://www.st.com/resource/en/application_note/an5033-stm32cube-mcu-package-examples-for-stm32h7-series-stmicroelectronics.pdf
Application Notes | https://www.st.com/resource/en/application_note/an5073-receiving-spdif-audio-stream-with-the-stm32f4f7h7-series-stmicroelectronics.pdf
Application Notes | https://www.st.com/resource/en/application_note/an4899-stm32-microcontroller-gpio-hardware-settings-and-lowpower-consumption-stmicroelectronics.pdf
Application Notes | https://www.st.com/resource/en/application_note/an5612-esd-protection-of-stm32-mcus-and-mpus-stmicroelectronics.pdf
Application Notes | https://www.st.com/resource/en/application_note/an4991-how-to-wake-up-an-stm32-microcontroller-from-lowpower-mode-with-the-usart-or-the-lpuart-stmicroelectronics.pdf
Application Notes | https://www.st.com/resource/en/application_note/an4838-introduction-to-memory-protection-unit-management-on-stm32-mcus-stmicroelectronics.pdf
Application Notes | https://www.st.com/resource/en/application_note/an5325-how-to-use-the-cordic-to-perform-mathematical-functions-on-stm32-mcus-stmicroelectronics.pdf
Application Notes | https://www.st.com/resource/en/application_note/an5927-i3c-protocol-used-in-the-stm32-bootloader-stmicroelectronics.pdf
Application Notes | https://www.st.com/resource/en/application_note/an5225-introduction-to-usb-typec-power-delivery-for-stm32-mcus-and-mpus-stmicroelectronics.pdf
Application Notes | https://www.st.com/resource/en/application_note/an5342--how-to-use-error-correction-code-ecc-management-for-internal-memories-protection-on-stm32-mcus-stmicroelectro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
Application Notes | https://www.st.com/resource/en/application_note/an5537-how-to-use-adc-oversampling-techniques-to-improve-signaltonoise-ratio-on-stm32-mcus-stmicroelectronics.pdf
Application Notes | https://www.st.com/resource/en/application_note/an5036-guidelines-for-thermal-management-on-stm32-applications-stmicroelectronics.pdf
Application Notes | https://www.st.com/resource/en/application_note/an4992-introduction-to-

| secure-firmware-install-sfi-for-stm32-mcus-stmicroelectronics.pdf
Application Notes | https://www.st.com/resource/en/application_note/an5405-how-to-use-fdcan-bootloader-protocol-on-stm32-mcus-stmicroelectronics.pdf
Application Notes | https://www.st.com/resource/en/application_note/an5690-how-to-use-vrefbuf-peripheral-on-stm32-mcus-and-mpus-stmicroelectronics.pdf
Application Notes | https://www.st.com/resource/en/application_note/an4230-introduction-to-random-number-generation-validation-using-the-nist-statistical-test-suite-for-stm32-mcus-and-m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
Application Notes | https://www.st.com/resource/en/application_note/an2867-guidelines-for-oscillator-design-on-stm8afals-and-stm32-mcusmpus-stmicroelectronics.pdf
Application Notes | https://www.st.com/resource/en/application_note/an4013-introduction-to-timers-for-stm32-mcus-stmicroelectronics.pdf
Application Notes | https://www.st.com/resource/en/application_note/an4277-how-to-use-pwm-shutdown-for-motor-control-and-digital-power-conversion-on-stm32-mcus-stmicroelectronics.pdf
Application Notes | https://www.st.com/resource/en/application_note/an4635-how-to-optimize-lpuart-power-consumption-on-stm32-mcus-stmicroelectronics.pdf
Application Notes | https://www.st.com/resource/en/application_note/an4759-introduction-to-using-the-hardware-realtime-clock-rtc-and-the-tamper-management-unit-tamp-with-stm32-mcus-stmi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
Application Notes | https://www.st.com/resource/en/application_note/an4861-introduction-to-lcdtft-display-controller-ltdc-on-stm32-mcus-stmicroelectronics.pdf
Application Notes | https://www.st.com/resource/en/application_note/an4908-getting-started-with-usart-automatic-baud-rater-detection-for-stm32-mcus-stmicroelectronics.pdf
Application Notes | https://www.st.com/resource/en/application_note/an4943-how-to-use-chromart-accelerator-to-refresh-an-lcdtft-display-on-stm32-mcus-stmicroelectronics.pdf
Application Notes | https://www.st.com/resource/en/application_note/an5156-introduction-to-security-for-stm32-mcus-stmicroelectronics.pdf
Application Notes | https://www.st.com/resource/en/application_note/an5224-introduction-to-

| dmamux-for-stm32-mcus-stmicroelectronics.pdf
Application Notes | https://www.st.com/resource/en/application_note/an5507-how-to-use-crc-to-check-the-integrity-of-the-internal-flash-memory-on-stm32h7-mcus-stmicroelectronics.pdf
Application Notes | https://www.st.com/resource/en/application_note/an5593-how-to-use-the-gpdma-for-stm32-mcus-stmicroelectronics.pdf
Application Notes | https://www.st.com/resource/en/application_note/an5879-introduction-to-i3c-for-stm32-mcus-stmicroelectronics.pdf
Application Notes | https://www.st.com/resource/en/application_note/an5935-getting-started-with-stm32h7rx7sx-mcus-hardware-development-stmicroelectronics.pdf
Application Notes | https://www.st.com/resource/en/application_note/an5996-migrating-from-stm32h730-and-stm32h750-to-stm32h7rx7sx-mcus-stmicroelectronics.pdf
Application Notes | https://www.st.com/resource/en/application_note/an6077-introduction-to-stm32cube-mcu-package-examples-for-stm32h7rx7sx-mcus-stmicroelectronics.pdf
Application Notes | https://www.st.com/resource/en/application_note/an5543-guidelines-for-enhanced-spi-communication-on-stm32-mcus-and-mpus-stmicroelectronics.pdf
Application Notes | https://www.st.com/resource/en/application_note/an6062-introduction-to-stm32h7rx7sx-system-architecture-and-performance-stmicroelectronics.pdf
Application Notes | https://www.st.com/resource/en/application_note/an5050-getting-started-with-octospi-hexadecaspi-and-xspi-interface-on-stm32-mcus-stmicroelectronics.pdf
Application Notes | https://www.st.com/resource/en/application_note/an4996-how-to-use-the-jpeg-codec-peripheral-on-stm32-mcus-stmicroelectronics.pdf
Application Notes | https://www.st.com/resource/en/application_note/an6008-getting-started-with-debug-authentication-da-for-stm32-mcus-stmicroelectronics.pdf
Application Notes | https://www.st.com/resource/en/application_note/an6022-introduction-to-sfsp-versions-for-stm32h7rx7sx-mcus-stmicroelectronics.pdf
Application Notes | https://www.st.com/resource/en/application_note/an5348-introduction-to-fdcan-peripherals-for-stm32-mcus-stmicroelectronics.pdf
Application Notes | https://www.st.com/resource/en/application_note/an6101-introduction-to-

| external-memory-manager-and-external-memory-loader-middleware-for-boot-flash-mcu-stmicroelectronics.pdf
Application Notes | https://www.st.com/resource/en/application_note/cd00211314-how-to-optimize-the-adc-accuracy-in-the-stm32-mcus-stmicroelectronics.pdf
Application Notes | https://www.st.com/resource/en/application_note/an2639-soldering-recommendations-and-package-information-for-leadfree-ecopack2-mcus-and-mpus-stmicroelectronics.pdf
Application Notes | https://www.st.com/resource/en/application_note/an4566-how-to-extend-the-dac-performance-on-stm32-mcus-stmicroelectronics.pdf
Application Notes | https://www.st.com/resource/en/application_note/an6127-getting-started-with-stm32h7rx7sx-mcus-in-stm32cubeide-stmicroelectronics.pdf
Application Notes | https://www.st.com/resource/en/application_note/an6211-introduction-to-digital-camera-interface-pixel-pipeline-for-stm32-mcus-stmicroelectronics.pdf
Application Notes | https://www.st.com/resource/en/application_note/an5647-the-goertzel-algorithm-to-compute-individual-terms-of-the-discrete-fourier-transform-dft-in-stm32-products-stm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
Application Notes | https://www.st.com/resource/en/application_note/an2606-introduction-to-system-memory-boot-mode-on-stm32-mcus-stmicroelectronics.pdf
Application Notes | https://www.st.com/resource/en/application_note/an5200-getting-started-with-the-stm32h7-mcu-sdmmc-host-controller-stmicroelectronics.pdf
Application Notes | https://www.st.com/resource/en/application_note/an6228-how-to-implement-xspi-readwhilewrite-feature-on-stm32-mcus-stmicroelectronics.pdf
Application Notes for related Tools & Software | https://www.st.com/resource/en/application_note/an4323-getting-started-with-stemwin-library-stmicroelectronics.pdf
Application Notes for related Tools & Software | https://www.st.com/resource/en/application_note/an4435-guidelines-for-obtaining-ulcsaiec-607301603351-class-b-certification-in-any-stm32-application-stmicroelectroni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
Application Notes for related Tools & Software | https://www.st.com/resource/en/application_note/an4657-stm32-inapplication-programming-iap-using-the-usart-stmicroelectronics.pdf

Application Notes for related Tools & Software | https://www.st.com/resource/en/application_note/an4841-digital-signal-processing-for-stm32-microcontrollers-using-cmsis-stmicroelectronics.pdf
Application Notes for related Tools & Software | https://www.st.com/resource/en/application_note/an4891-stm32h72x-stm32h73x-and-singlecore-stm32h74x75x-system-architecture-and-performance-stmicroelectronics.pdf
Application Notes for related Tools & Software | https://www.st.com/resource/en/application_note/an5001-stm32cube-expansion-package-for-stm32h7-series-mdma-stmicroelectronics.pdf
Application Notes for related Tools & Software | https://www.st.com/resource/en/application_note/an5014-stm32h7x3-smart-power-management-expansion-package-for-stm32cube-stmicroelectronics.pdf
Application Notes for related Tools & Software | https://www.st.com/resource/en/application_note/an5033-stm32cube-mcu-package-examples-for-stm32h7-series-stmicroelectronics.pdf
Application Notes for related Tools & Software | https://www.st.com/resource/en/application_note/an5056-integration-guide-for-the-xcubesbsfu-stm32cube-expansion-package-stmicroelectronics.pdf
Application Notes for related Tools & Software | https://www.st.com/resource/en/application_note/an5360-getting-started-with-projects-based-on-the-stm32mp1-series-in-stm32cubeide-stmicroelectronics.pdf
Application Notes for related Tools & Software | https://www.st.com/resource/en/application_note/an5361-getting-started-with-projects-based-on-dualcore-stm32h7-microcontrollers-in-stm32cubeide-stmicroelectronics.pd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
Application Notes for related Tools & Software | https://www.st.com/resource/en/application_note/an5394-getting-started-with-projects-based-on-the-stm32l5-series-in-stm32cubeide-stmicroelectronics.pdf
Application Notes for related Tools & Software | https://www.st.com/resource/en/application_note/an5418-how-to-build-a-simple-usbpd-sink-application-with-stm32cubemx-stmicroelectronics.pdf
Application Notes for related Tools & Software | https://www.st.com/resource/en/application_note/an5426-migrating-graphics-middleware-projects-from-stm32cubemx-540-to-stm32cubemx-550-stmicroelectronics.pdf
Application Notes | https://www.st.com/resource/en/application_note/an5564-getting-started-

for related Tools & Software | with-projects-based-on-dualcore-stm32wl-microcontrollers-in-stm32cubeide-stmicroelectronics.pdf
Application Notes for related Tools & Software | https://www.st.com/resource/en/application_note/an4865-lowpower-timer-lptim-applicative-use-cases-on-stm32-mcus-and-mpus-stmicroelectronics.pdf
Application Notes for related Tools & Software | https://www.st.com/resource/en/application_note/an5698-adapting-the-xcubestl-functional-safety-package-for-stm32-iec-61508-compliant-to-other-safety-standards-stmicr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
Application Notes for related Tools & Software | https://www.st.com/resource/en/application_note/an5731-stm32cubemx-and-stm32cubeide-threadsafe-solution-stmicroelectronics.pdf
Application Notes for related Tools & Software | https://www.st.com/resource/en/application_note/an5450-stm32h7a37b3-lines-and-stm32h7b0-value-line-smart-power-management-expansion-package-for-stm32cube-stmicroelec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
Application Notes for related Tools & Software | https://www.st.com/resource/en/application_note/an4502-stm32-smbuspmbus-expansion-package-for-stm32cube-stmicroelectronics.pdf
Application Notes for related Tools & Software | https://www.st.com/resource/en/application_note/an5952-how-to-use-cmake-in-stm32cubeide-stmicroelectronics.pdf
Application Notes for related Tools & Software | https://www.st.com/resource/en/application_note/an4635-how-to-optimize-lpuart-power-consumption-on-stm32-mcus-stmicroelectronics.pdf
Application Notes for related Tools & Software | https://www.st.com/resource/en/application_note/an5054-how-to-perform-secure-programming-using-stm32cubeprogrammer-stmicroelectronics.pdf
Application Notes for related Tools & Software | https://www.st.com/resource/en/application_note/an6077-introduction-to-stm32cube-mcu-package-examples-for-stm32h7rx7sx-mcus-stmicroelectronics.pdf
Application Notes for related Tools & Software | https://www.st.com/resource/en/application_note/an6088-how-to-use-mce-for-encryptiondecryption-on-stm32-mcus-stmicroelectronics.pdf

## Application Notes for related Tools

## https://www.st.com/resource/en/application_note/an6179-how-tointegrate-the-stl-firmware-into-a-time-critical-user-application-

& Software | stmicroelectronics.pdf
Application Notes for related Tools & Software | https://www.st.com/resource/en/application_note/an6127-getting-started-with-stm32h7rx7sx-mcus-in-stm32cubeide-stmicroelectronics.pdf
Application Notes for related Tools & Software | https://www.st.com/resource/en/application_note/an6265-getting-started-with-stm32n6-mcus-in-stm32cubeide-stmicroelectronics.pdf
Design Notes & Tips | https://www.st.com/resource/en/design_tip/dt0117-microphone-array-beamforming-in-the-pcm-and-pdm-domain-stmicroelectronics.pdf
Errata Sheets | https://www.st.com/resource/en/errata_sheet/es0596-stm32h7rxx7sxx-device-errata-stmicroelectronics.pdf
Datasheet | https://www.st.com/resource/en/datasheet/dm00990256.pdf
Programming Manuals | https://www.st.com/resource/en/programming_manual/pm0253-stm32f7-series-and-stm32h7-series-cortexm7-processor-programming-manual-stmicroelectronics.pdf
Reference Manuals | https://www.st.com/resource/en/reference_manual/rm0477-stm32h7rx7sx-armbased-32bit-mcus-stmicroelectronics.pdf
Technical Notes & Articles | https://www.st.com/resource/en/technical_note/tn1163-description-of-wlcsp-for-microcontrollers-and-recommendations-for-its-use-stmicroelectronics.pdf
Technical Notes & Articles | https://www.st.com/resource/en/technical_note/tn1204-tape-and-reel-shipping-media-for-stm32-microcontrollers-in-bga-packages-stmicroelectronics.pdf
Technical Notes & Articles | https://www.st.com/resource/en/technical_note/tn1205-tape-and-reel-shipping-media-for-stm8-and-stm32-microcontrollers-in-fpn-packages-stmicroelectronics.pdf
Technical Notes & Articles | https://www.st.com/resource/en/technical_note/tn1206-tape-and-reel-shipping-media-for-stm8-and-stm32-microcontrollers-in-qfp-packages-stmicroelectronics.pdf
Technical Notes & Articles | https://www.st.com/resource/en/technical_note/tn1207-tape-and-reel-shipping-media-for-stm8-and-stm32-microcontrollers-in-so-packages-stmicroelectronics.pdf
Technical Notes | https://www.st.com/resource/en/technical_note/tn1208-tape-and-reel-

& Articles | shipping-media-for-stm8-and-stm32-microcontrollers-in-tssop-and-ssop-packages-stmicroelectronics.pdf
Technical Notes & Articles | https://www.st.com/resource/en/technical_note/tn1433-reference-device-marking-schematics-for-stm32-microcontrollers-and-microprocessors-stmicroelectronics.pdf
User Manuals | https://www.st.com/resource/en/user_manual/um2840-stm32h7-dualcore-series-safety-manual-stmicroelectronics.pdf
User Manuals | https://www.st.com/resource/en/user_manual/um2331-stm32h7-singlecore-series-safety-manual-stmicroelectronics.pdf
User Manuals | https://www.st.com/resource/en/user_manual/um3252-stm32h7-series-ulcsaiec-607301603351-selftest-library-user-guide-stmicroelectronics.pdf
User Manuals | https://www.st.com/resource/en/user_manual/um3294-getting-started-with-stm32cubeh7rs-for-stm32h7sx7rx-mcus-stmicroelectronics.pdf
User Manuals | https://www.st.com/resource/en/user_manual/um3266-stm32h7rx7sx--lines-safety-manual-stmicroelectronics.pdf
User Manuals | https://www.st.com/resource/en/user_manual/um3478-stm32h7rx7sx-lines-ulcsaiec-607301603351-selftest-library-user-guide-stmicroelectronics.pdf

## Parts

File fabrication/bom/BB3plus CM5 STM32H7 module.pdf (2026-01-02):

EEZ BB3+ CM5 STM32H7 Module BOM

# | Reference | Value | Qty | DigiKey | Mouser | TME | LCSC

1 | C1,C2,C12,C15,C69,C70,C71 | 10u | 7 | 1276-1052-6-ND | 187-CL21A106KPFNNNE | CL21A106KPFNNNE | C17024
2 | | 100n | 40 | 490-6287-1-ND | 81-GRM155R60J104KA1D | GRM155R60J104KA01D
3 | C4,C7,C23,C29,C30,C53 | 1u | 6 | 490-GRM155C81A105MA12DCT-ND 81-GRM155C81A105MA2D | GRM155R60J105KE19D C15684
4 | C5,C6,C43,C44 | 10p | 4 | 490-7299-1-ND | 81-GRM1555C2A100JA1D | GRM1555C1H100GA01D
5 | C8,C51,C54,C55,C72 | 10n | 5 | 490-6309-1-ND | 81-GRM155R61C103KA1D | GRM155R61C103KA01D
6 | | 4u7 | 10 | 1276-1044-1-ND | 187-CL10A475KP8NNND | CL10A475KP8NNNC | C1705
7 | C16,C19,C22,C27,C45,C46,C47 | 2u2 | 7 | 490-GRM155C71A225KE11JCT-ND | 81-GRM155C71A225KE1J | - | C2211665
8 | C24 | 220p | 1 | 1276-6762-1-ND | 187-CL05C221JB51PNC | CL05C221JB51PNC | C472450
9 | C52 | 470p | 1 | 1276-1117-1-ND | 187-CL05C471JB5NNNC | CL05C471JB5NNNC | C307449
10 | FB1 | FBMJ1608HM180NTR | 1 | 587-3251-2-ND | 963-FBMJ1608HM180NTR | - | C2661511
11 | FB2 | BLM18AG102SH1D | 1 | 490-7809-1-ND | 81-BLM18AG102SH1D | BLM18AG102SH1D | C337877
12 | FB3,FB4,FB5 | 60R@100MHz | 3 | 490-7809-1-ND | 81-BLM18AG102SH1D | BLM18AG102SH1D | C337877
13 | IC1 | AZ1117CH2-3.3TRG1 | 1 | 31-AZ1117CH2-3.3TRG1CT-ND | 621-AZ1117CH2-33TRG1 | AZ1117CH2-3.3TRG1 | C108492
14 | IC2 | PI3USB102ZLEX | 1 | PI3USB102ZLEXCT-ND | 729-PI3USB102GZLEX | - | C500797
15 | IC3 | SN74LVC1G14DBVR | 1 | 296-11607-1-ND | 595-SN74LVC1G14DBVR | SN74LVC1G14DBVR | C19829661
16 | IC4 | STM32H7R7L8H6H | 1 | 497-STM32H7R7L8H6H-ND | 511-STM32H7R7L8H6H | STM32H7R7L8H6H | C26430721
17 | IC5 | TLV75718PDRVR | 1 | 296-50006-1-ND | 595-TLV75718PDRVR | TLV75718PDRVR | C2861386
18 | IC6 | IS21EF04GP-JQLI | 1 | 706-IS21EF04GP-JQLI-ND | 870-IS21EF04GP-JQLI | - | -
19 | IC7 | LAN8742A-CZ-TR | 1 | LAN8742A-CZ-CT-ND | 579-LAN8742A-CZ-TR | LAN8742A-CZ-TR
20 | IC8 | APS256XXN-OBR-BG | 1 | - | 878-APS256XXN-OB9-BG | - | C42963059
21 | IC9 | TFP410PAP | 1 | 296-12666-ND | 595-TFP410PAP | - | C1543847
22 | IC10 | TS3DV642A0RUAR | 1 | 296-39510-1-ND | 595-TS3DV642A0RUAR | - | C157482
23 | IC11 | LSF0204GU12 | 1 | 1727-LSF0204GU12-Q100XTR-ND | 771-LSF0204GU12Q100X | - | C7296193
24 | IC12 | MX25UM25645GXDI00-T | 1 | 1092-MX25UM25645GXDI00-ND | 95-25UM25645GXDI0T | X25UM25645GXDI00TR C20099946
25 | L1 | LQM2MPN2R2NG0 | 1 | 490-7786-2-ND | 81-LQM2MPN2R2NG0L | LQM2MPN2R2NG0L | C83998
26 | R1,R2,R5,R26,R27 | 1K5 | 5 | 311-1.50KLRCT-ND | 603-RC0402FR-071K5L | RC0402FR-071K5L | C114759
27 | | 10K | 12 | 311-10.0KLRCT-ND | 603-RC0402FR-0710KL | SMD0402-10K-1% | C60490
28 | R10 | 12K1 | 1 | 13-RC0402FR-1012K1LCT-ND | 603-RC0402FR-1012K1L | SMD0402-12.1K-1%
29 | R14,R19 | 220R | 2 | 311-220LRCT-ND | 603-RC0402FR-07220RL | RC0402FR-07220R | C112291
30 | R15,R16,R17,R18 | 49R9 | 4 | 13-RC0402FR-1349R9LCT-ND | 603-RC0402FR-1349R9L | RC0402FR-0749R9L | C4007649
31 | R20 | 4K7 | 1 | 13-RC0402FR-104K7LCT-ND | 603-RC0402FR-104K7L | SMD0402-4K7-1%
32 | R22 | 510R | 1 | 13-RC0402FR-13510RLCT-ND | 603-RC0402FR-13510RL | RC0402FR-07510RL
33 | R23 | 1K | 1 | 13-RC0402FR-131KLCT-ND | 603-RC0402FR-131KL | SMD0402-1K-1% | C4247997
34 | RN1,RN2 | CAY16A-330J4AS | 2 | CAY16-330J4LFCT-ND | 652-CAY16-330J4LF | CAY16-330J4LF
35 | SoM1 | | 2 | H11614CT-ND | 798-DF40C100DP0.4V51 | DF40C-100DP-04V-51 | C531031
36 | Y1,Y2 | VXM7-9032-25M0000000 | 2 | 150-VXM7-9032-25M0000000CT-ND 579-M7903225M0000000 | - | C1517995

C3,C10,C11,C13,C14,C17,C18,C20,C21 ,C25,C26,C28,C31,C32,C33,C34,C35,C 36,C37,C38,C39,C40,C48,C49,C50,C58, C59,C61,C63,C64,C65,C66,C67,C68,C7 3,C74,C75,C76,C78,C80

C9,C41,C42,C56,C57,C60,C62,C77,C79 ,C81

R3,R4,R6,R7,R8,R9,R11,R13,R21,R24, R25,R28

DF40HC(3.0)-
100DS-0.4V(51

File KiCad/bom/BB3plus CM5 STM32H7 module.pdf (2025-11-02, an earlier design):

EEZ BB3+ CM5 STM32H7 Module BOM

# | Reference | Value | Qty | DigiKey | Mouser | TME | LCSC

1 | C1,C10,C13 | 10u | 3 | 1276-1052-6-ND | 187-CL21A106KPFNNNE | CL21A106KPFNNNE | C17024
2 | C2,C5,C21,C23,C24,C50 | 1u | 6 | 81-GRM155C81A105MA2D | GRM155R60J105KE19D C15684
3 | C3,C4,C41,C42 | 10p | 4 | 1276-1069-1-ND | 187-CL10C100CB8NNNC | VJ0603A100JXACW1BC C318677
4 | C6,C51,C52,C67 | 10n | 4 | 490-6309-1-ND | 81-GRM155R61C103KA1D | GRM155R61C103KA01D
5 | | 4u7 | 11 | 1276-1044-1-ND | 187-CL10A475KP8NNNC | CL10A475KP8NNNC | C1705
6 | | 100n | 37 | 490-6287-1-ND | 81-GRM155R60J104KA1D | GRM155R60J104KA01D
7 | C14,C17,C20,C27,C43,C44,C45 | 2u2 | 7 | | 81-GRM155C71A225KE1J | - | C2211665
8 | C22 | 220p | 1 | 1276-6762-1-ND | 187-CL05C221JB51PNC | CL05C221JB51PNC | C472450
9 | C49 | 470p | 1 | 1276-1117-1-ND | 187-CL05C471JB5NNNC | CL05C471JB5NNNC | C307449
10 | FB1 | | 1 | 587-3251-2-ND | 963-FBMJ1608HM180NTR | - | C2661511
11 | FB2 | BLM18AG102SH1D | 1 | 490-7809-1-ND | 81-BLM18AG102SH1D | BLM18AG102SH1D | C337877
12 | FB3,FB4,FB5 | 60R@100MHz | 3 | 490-7809-1-ND | 81-BLM18AG102SH1D | BLM18AG102SH1D | C337877
13 | IC1 | AZ1117CH2-3.3TRG1 | 1 | 31-AZ1117CH2-3.3TRG1CT-ND | 621-AZ1117CH2-33TRG1 | AZ1117CH2-3.3TRG1 | C108492
14 | IC2 | SN74LVC1G14DBVR | 1 | 296-11607-1-ND | 595-SN74LVC1G14DBVR | SN74LVC1G14DBVR | C19829661
15 | IC3 | STM32H7R7L8H6H | 1 | 497-STM32H7R7L8H6H-ND | 511-STM32H7R7L8H6H | STM32H7R7L8H6H | C26430721
16 | IC4 | TLV75718PDRVR | 1 | 296-50006-1-ND | 595-TLV75718PDRVR | TLV75718PDRVR | C2861386
17 | IC5 | MX52LM04A11XVW | 1 | 1092-MX52LM04A11XVW-ND | 95-52LM04A11XVWT | - | -
18 | IC6 | LAN8742A-CZ-TR | 1 | LAN8742A-CZ-CT-ND | 579-LAN8742A-CZ-TR | LAN8742A-CZ-TR
19 | IC7 | APS256XXN-OBR-BG | 1 | - | 878-APS256XXN-OB9-BG | - | C42963059
20 | IC8 | TFP410PAP | 1 | 296-12666-ND | 595-TFP410PAP | - | C1543847
21 | IC9 | TS3DV642A0RUAR | 1 | 296-39510-1-ND | 595-TS3DV642A0RUAR | - | C157482
22 | IC10 | 1 | 1092-MX25UM25645GXDI00-ND | 95-25UM25645GXDI0T | X25UM25645GXDI00TR C20099946
23 | L1 | LQM2MPN2R2NG0 | 1 | 490-7786-2-ND | 81-LQM2MPN2R2NG0L | LQM2MPN2R2NG0L | C83998
24 | R1,R2,R6 | 1K5 | 3 | 311-1.50KLRCT-ND | 603-RC0402FR-071K5L | RC0402FR-071K5L | C114759
25 | | 10K | 11 | 311-10.0KLRCT-ND | 603-RC0402FR-0710KL | SMD0402-10K-1% | C60490
26 | R4,R5 | 0R | 2 | 311-0.0LRCT-ND | 603-RC0402FR-070RL | RC0402FR-070RL | C106231
27 | R11 | 12K1 | 1 | 13-RC0402FR-1012K1LCT-ND | 603-RC0402FR-1012K1L | SMD0402-12.1K-1%
28 | R15,R16,R17,R18 | 49R9 | 4 | 13-RC0402FR-1349R9LCT-ND | 603-RC0402FR-1349R9L | RC0402FR-0749R9L | C4007649
29 | R19 | 4K99 | 1 | 13-RC0402FR-1349K9LCT-ND | 603-RC0402FR-1349K9L | SMD0402-49.9K-1%
30 | R21 | 510R | 1 | 13-RC0402FR-13510RLCT-ND | 603-RC0402FR-13510RL | RC0402FR-07510RL
31 | R22 | 1K | 1 | 13-RC0402FR-131KLCT-ND | 603-RC0402FR-131KL | SMD0402-1K-1% | C4247997
32 | RN1,RN2 | CAY16A-330J4AS | 2 | CAY16-330J4LFCT-ND | 652-CAY16-330J4LF | CAY16-330J4LF
33 | SoM1 | | 1 | | 798-DF40HC30100DS451 | - | C424649
34 | Y1,Y2 | | 2 | | 579-M7903225M0000000 | - | C1517995

490-GRM155C81A105MA12DCT-ND

C7,C39,C40,C53,C54,C57,C59,C66,C70 ,C72,C74
C8,C9,C11,C12,C15,C16,C18,C19,C25, C26,C28,C29,C30,C31,C32,C33,C34,C3 5,C36,C37,C38,C46,C47,C48,C55,C56, C58,C60,C61,C62,C63,C64,C65,C68,C6 9,C71,C73
490-GRM155C71A225KE11JCT-ND

FBMJ1608HM180NT
R

MX25UM25645GXDI0
0-T

R3,R7,R8,R9,R10,R12,R13,R14,R20,R2 3,R24

2x DF40HC(3.0)-
100DS-0.4V(51

26-DF40HC(3.0)-100DS-0.4V(51)CT-ND
VXM7-9032-
25M0000000

150-VXM7-9032-25M0000000CT-ND

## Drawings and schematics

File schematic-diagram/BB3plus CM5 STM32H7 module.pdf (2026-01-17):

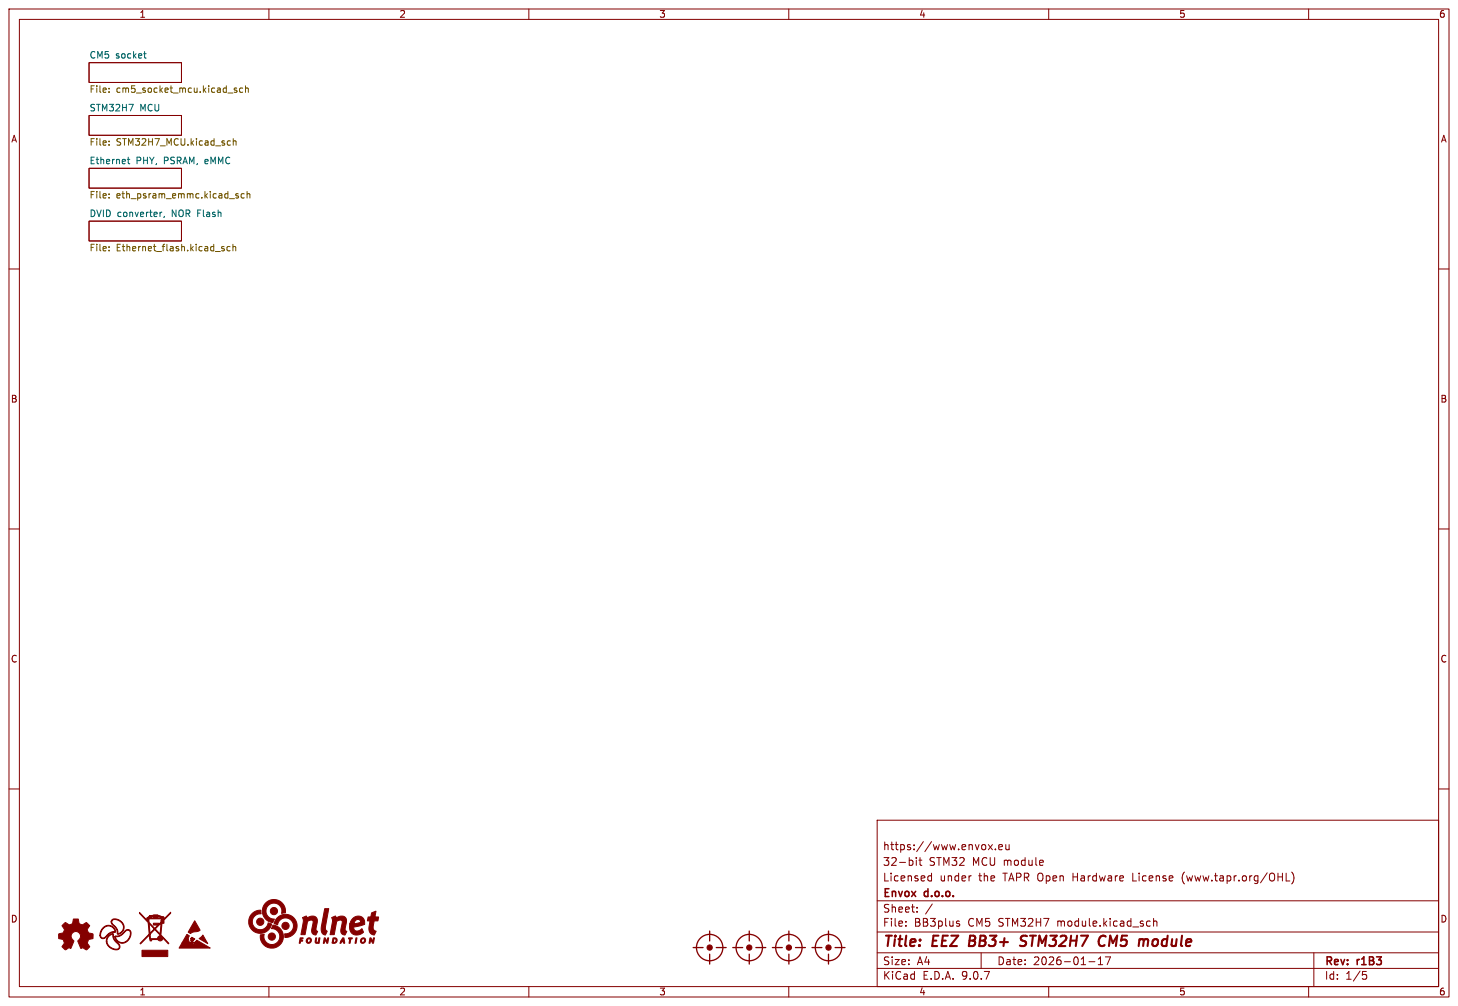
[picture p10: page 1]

File: STM32H7_MCU.kicad_sch Ethernet PHY, PSRAM, eMMC

https://www.envox.eu

Id: 1/5 Title: EEZ BB3+ STM32H7 CM5 module

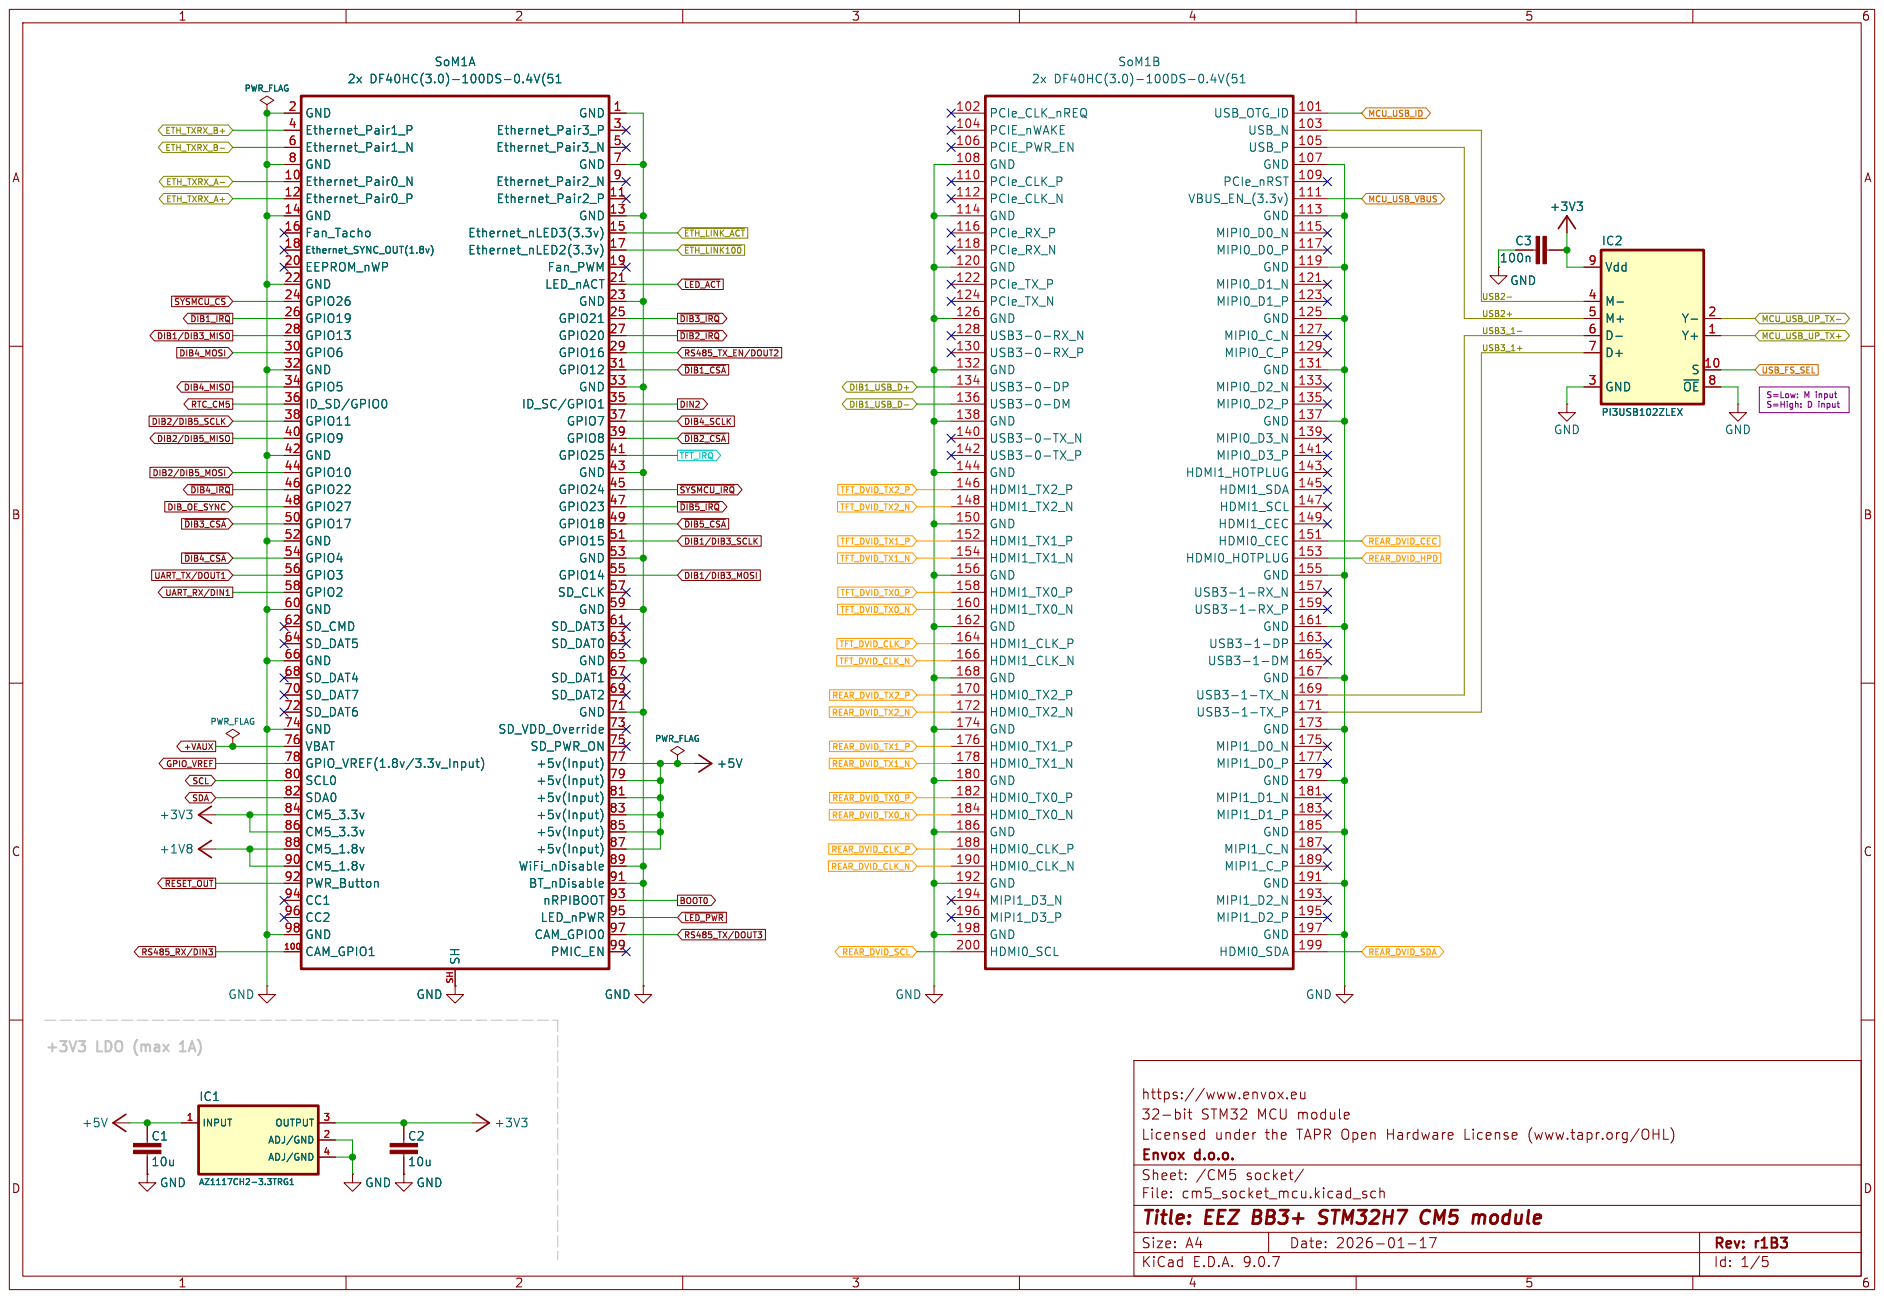
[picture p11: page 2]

https://www.envox.eu GND

Id: 1/5 Title: EEZ BB3+ STM32H7 CM5 module

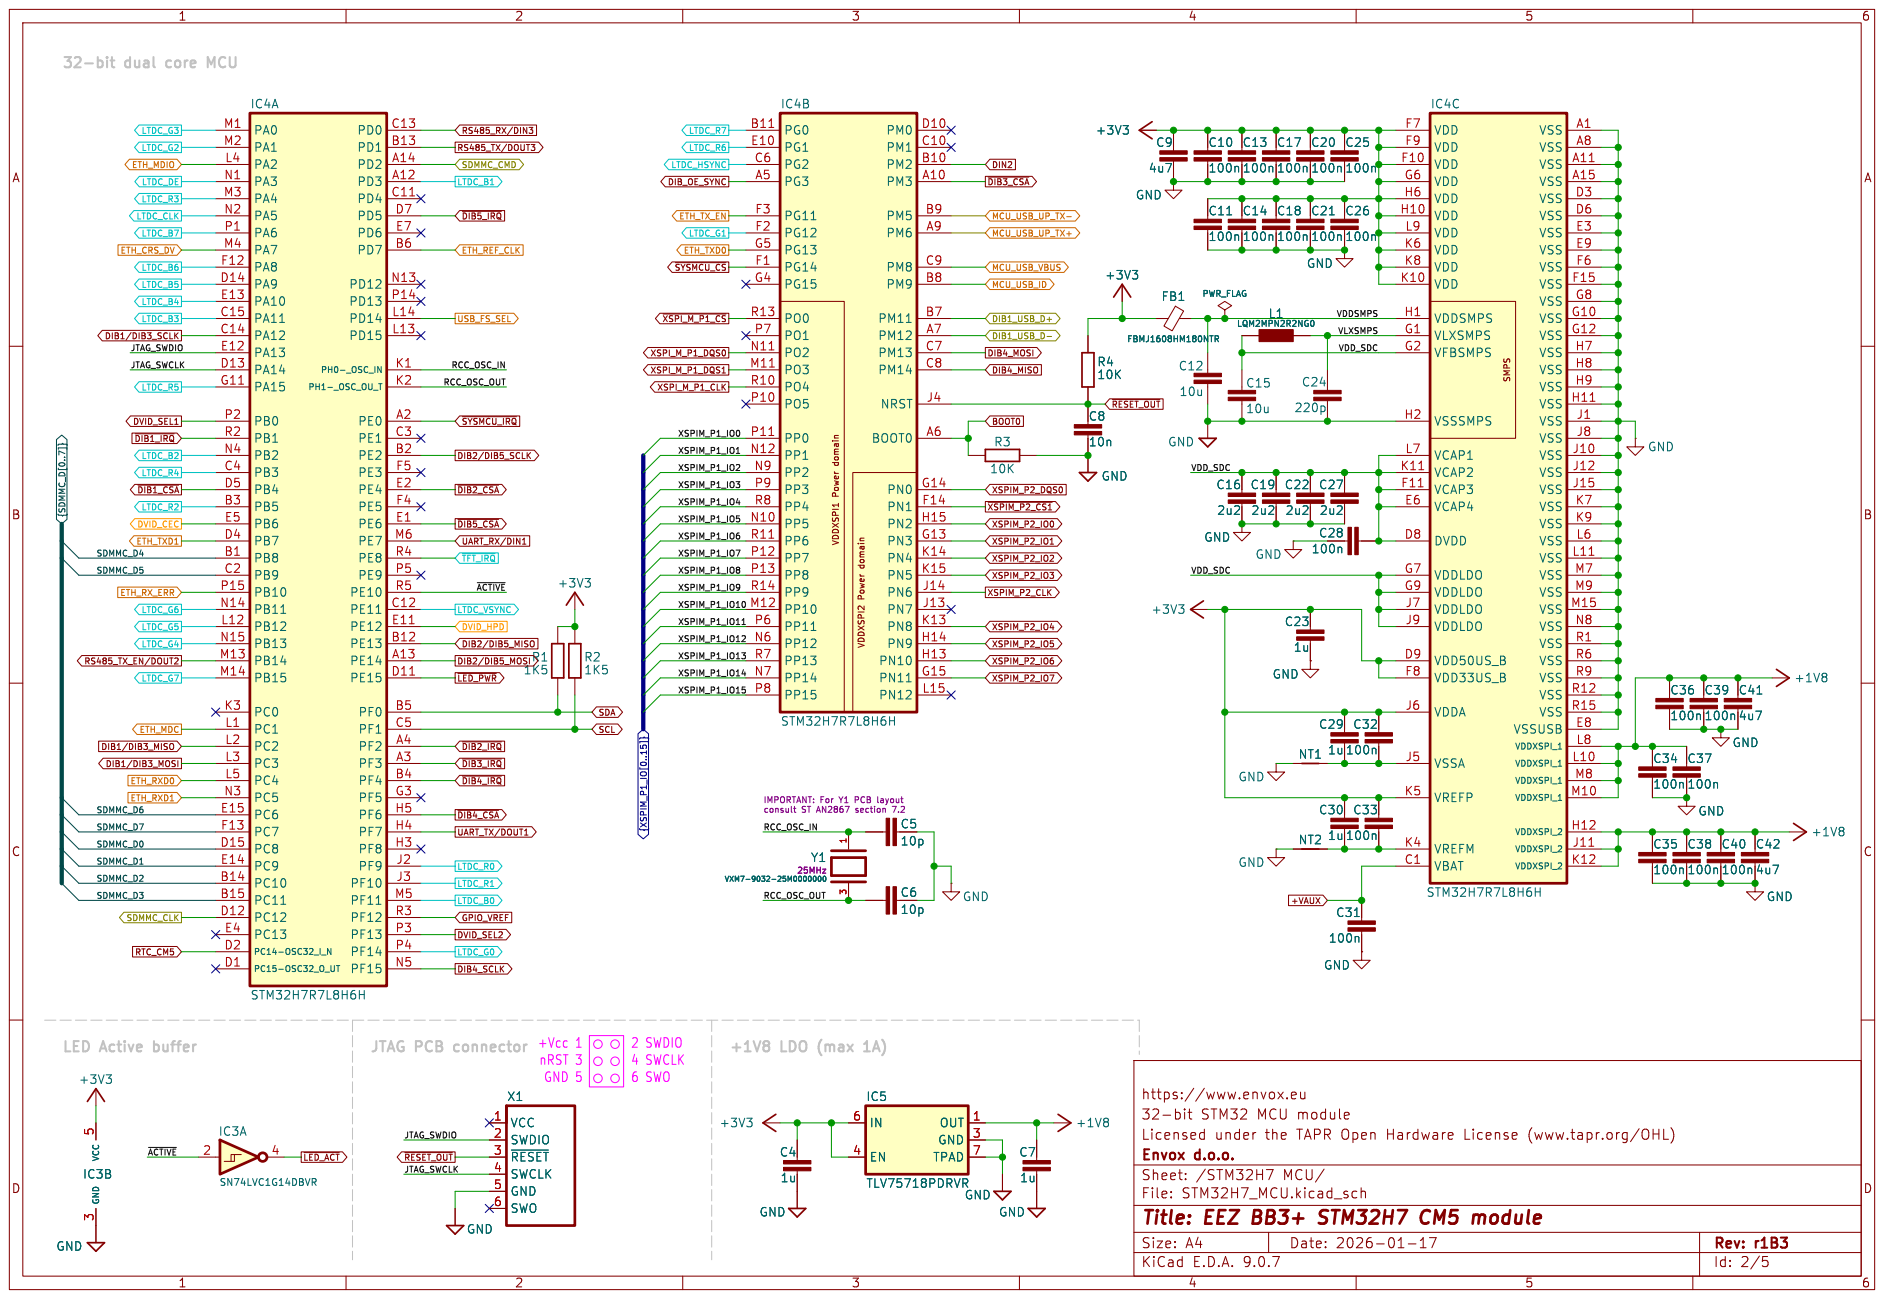
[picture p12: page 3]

VSS A1 VSS A8 VSS A11 VSS A15 VSS D3 VSS D6 VSS E3 VSS E9 VSS F6 VSS F15 VSS G8 VSS G10 VSS G12 VSS H7 VSS H8 VSS H9 VSS H11 VSS J1 VSS J8 VSS J10 VSS J12 VSS J15 VSS K7 VSS K9 VSS L6 VSS L11 VSS M7 VSS M9 VSS M15 VSS N8 VSS R1 VSS R6 VSS R9 VSS R12 VSS R15 VSSUSB E8

VCC 1 SWDIO 2 ~{RESET} 3 SWCLK 4 GND 5 SWO 6 X1

X1VCC 1 SWDIO 2 ~{RESET} 3 SWCLK 4 GND 5 SWO 6

Id: 2/5 Title: EEZ BB3+ STM32H7 CM5 module

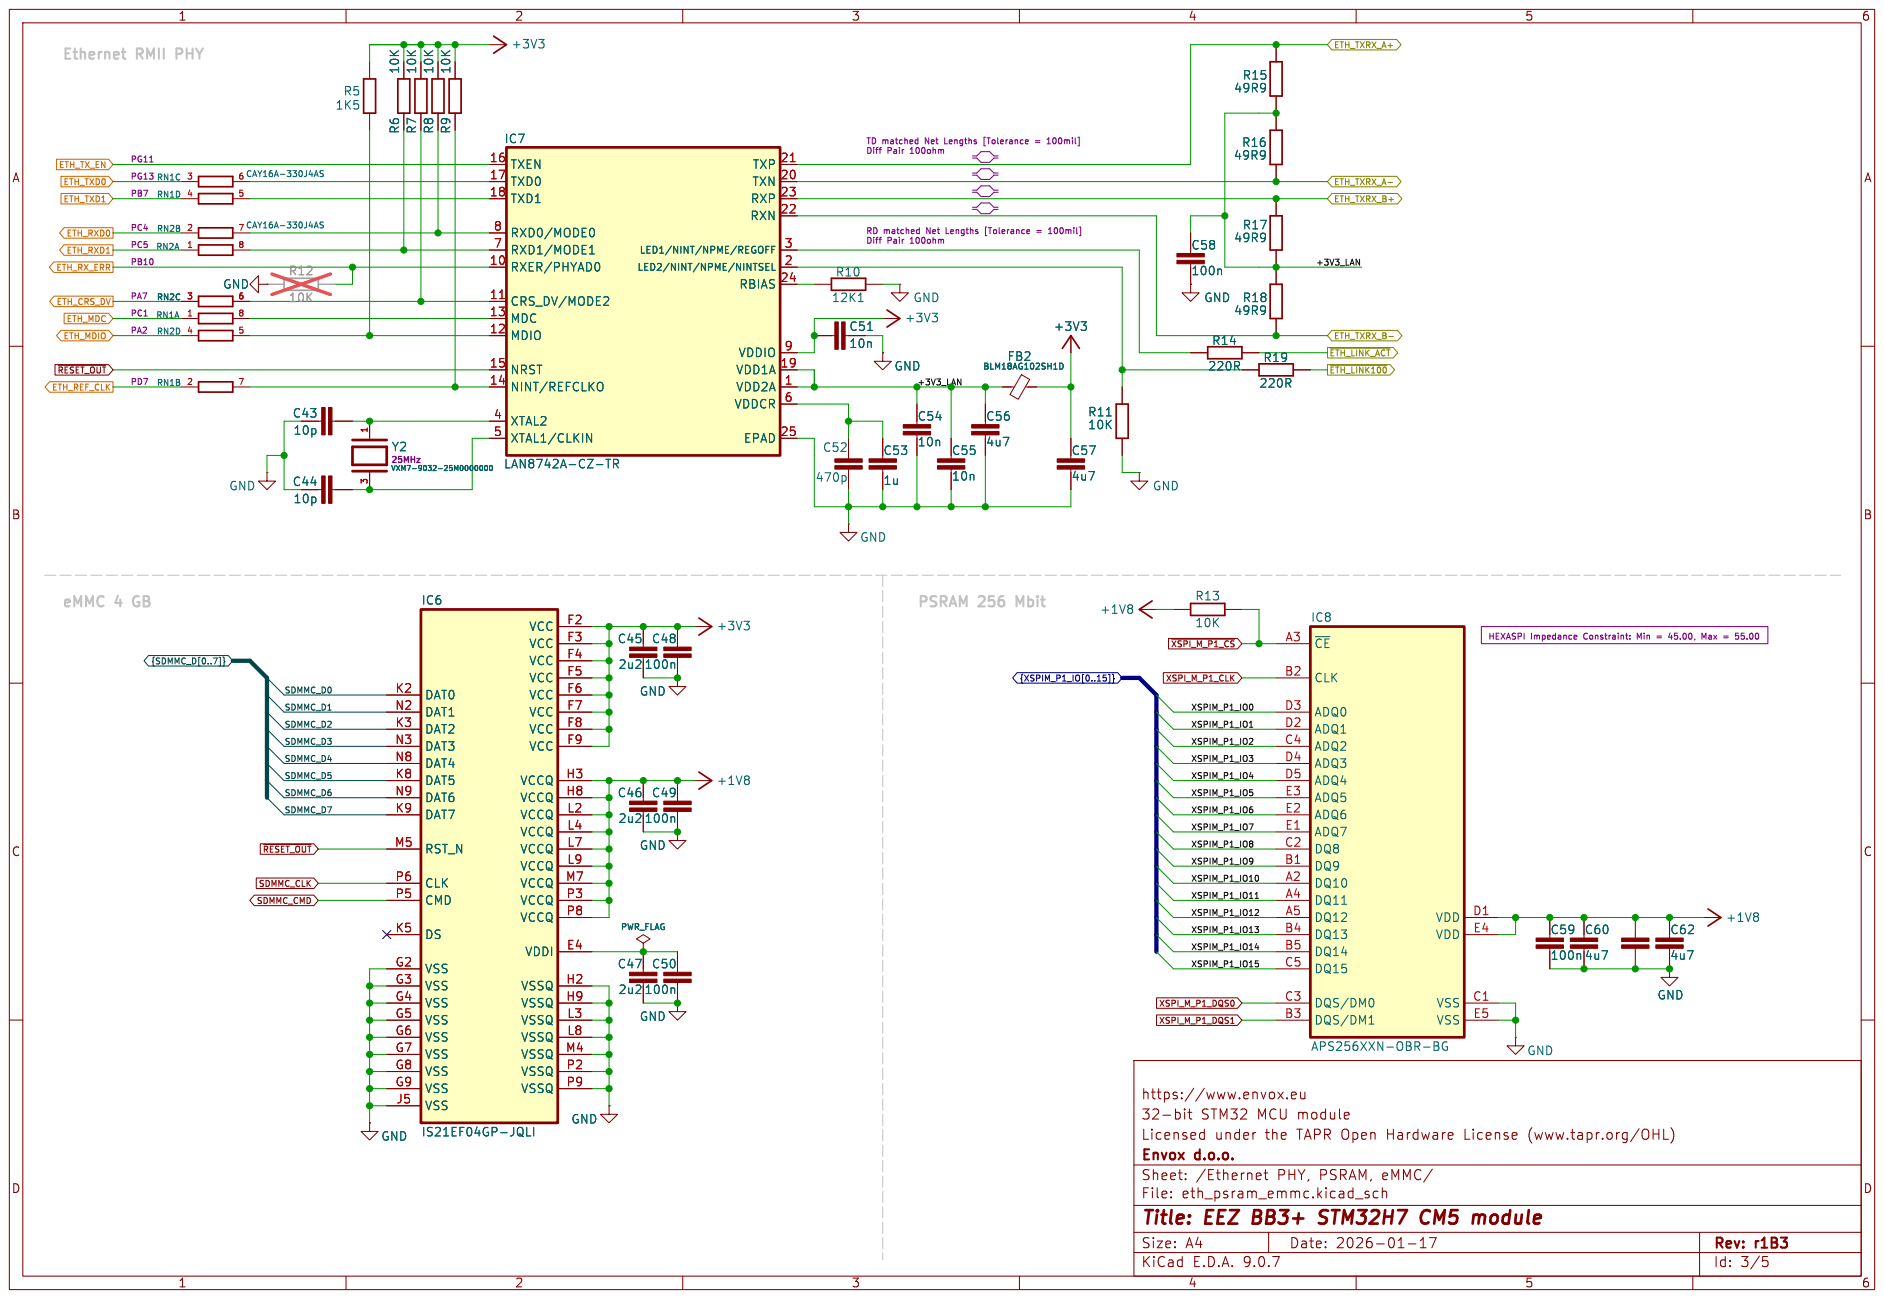
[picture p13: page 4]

https://www.envox.eu GND

Id: 3/5 Title: EEZ BB3+ STM32H7 CM5 module

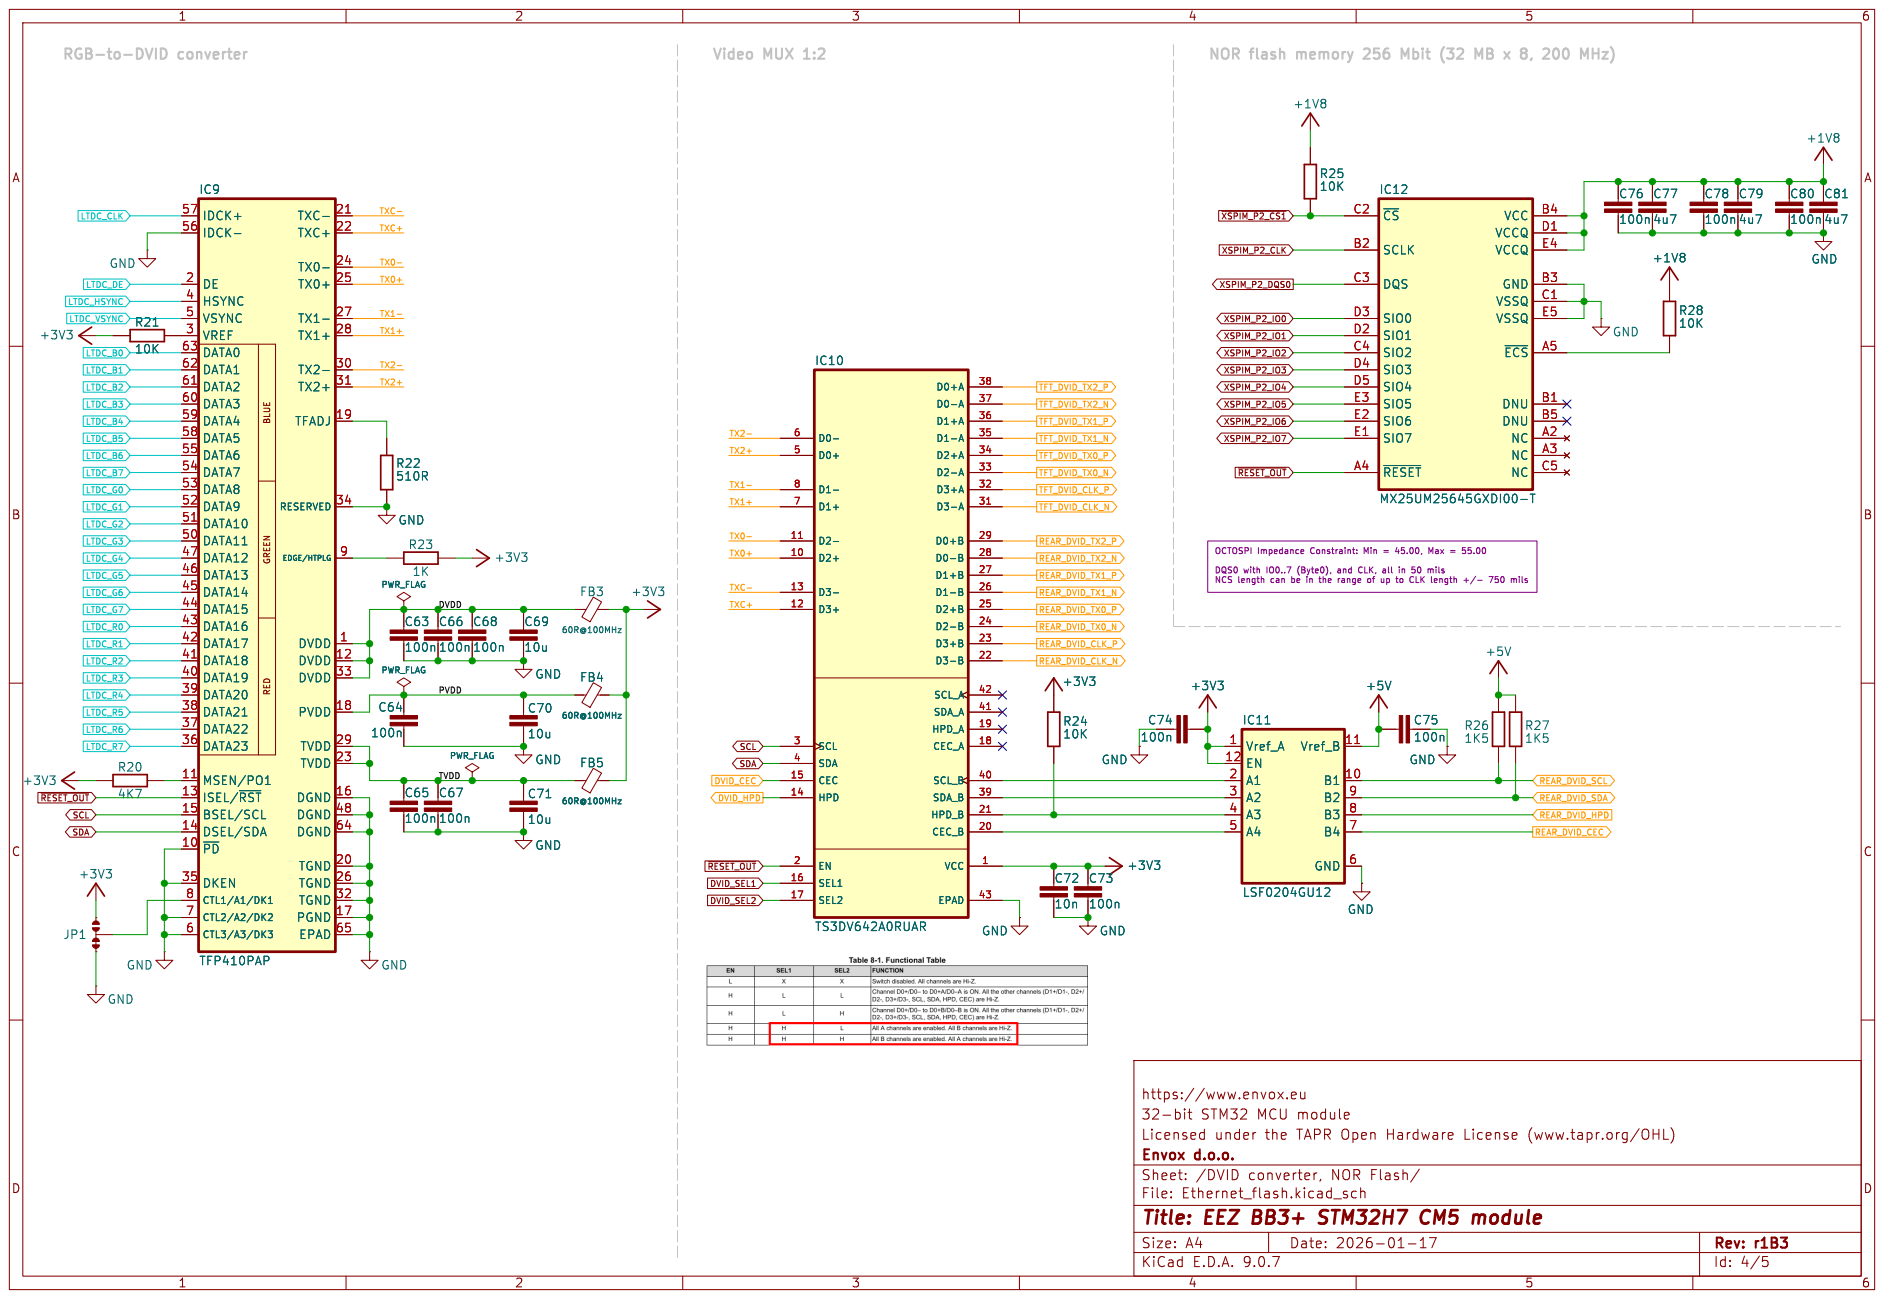
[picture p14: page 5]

IDCK- 56 DE 2 HSYNC 4 VSYNC 5 VREF 3 DATA0 63 DATA1 62 DATA2 61 DATA3 60 DATA4 59 DATA5 58 DATA6 55 DATA7 54 DATA8 53 DATA9 52 DATA10 51 DATA11 50 DATA12 47 DATA13 46 DATA14 45 DATA15 44 DATA16 43 DATA17 42 DATA18 41 DATA19 40 DATA20 39 DATA21 38 DATA22 37 DATA23 36 MSEN/PO1 11
10K GND

TXC- 21 TXC+ 22 TX0- 24 TX0+ 25 TX1- 27 TX1+ 28 TX2- 30 TX2+ 31 TFADJ 19 RESERVED 34
4u7 BLUE GREEN RED

ISEL/~{RST} 13 BSEL/SCL 15 DSEL/SDA 14 ~{PD} 10 DKEN 35 CTL1/A1/DK1 8 CTL2/A2/DK2 7 CTL3/A3/DK3 6

https://www.envox.eu

Id: 4/5 Title: EEZ BB3+ STM32H7 CM5 module

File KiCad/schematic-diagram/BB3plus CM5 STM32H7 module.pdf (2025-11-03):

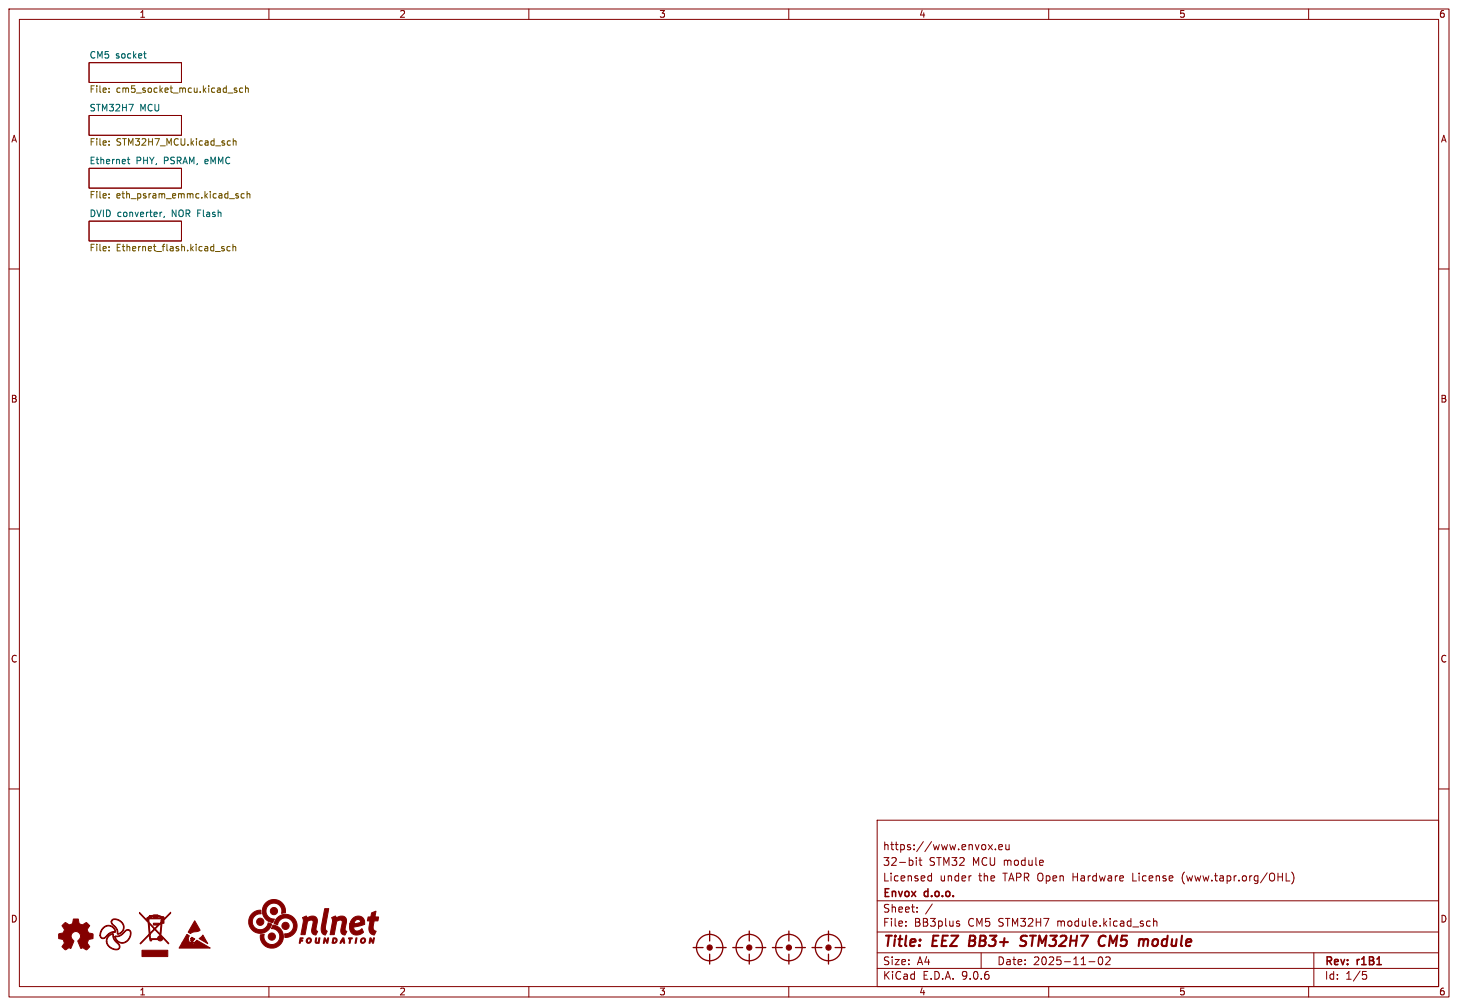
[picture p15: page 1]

File: STM32H7_MCU.kicad_sch Ethernet PHY, PSRAM, eMMC

https://www.envox.eu

Id: 1/5 Title: EEZ BB3+ STM32H7 CM5 module

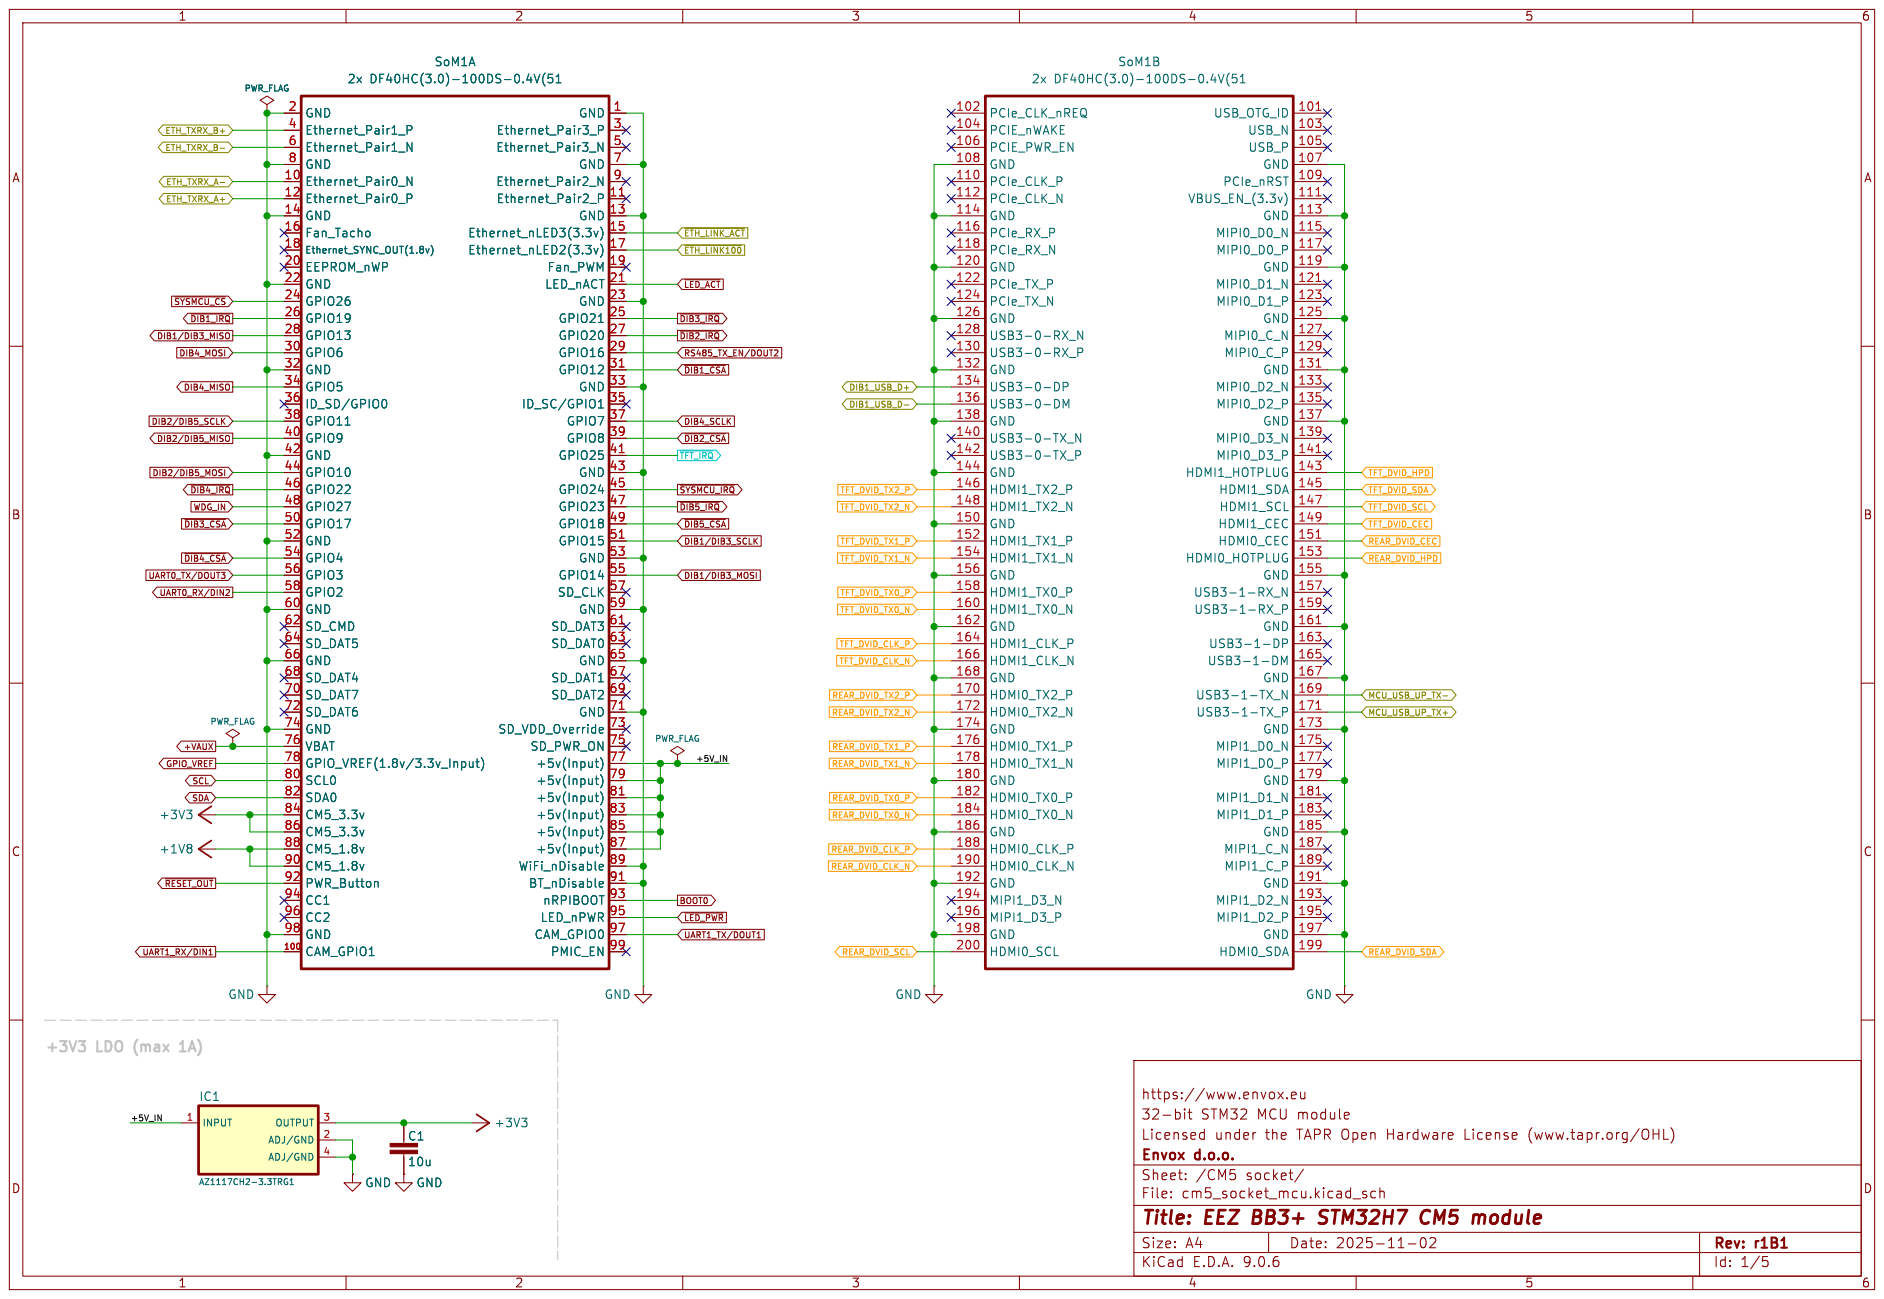
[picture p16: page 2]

SoM1A
ID_SD/GPIO0 36 GPIO11 38 GPIO9 40 GND 42 GPIO10 44 GPIO22 46 GPIO27 48 GPIO17 50 GND 52 GPIO4 54 GPIO3 56 GPIO2 58 GND 60 SD_CMD 62 SD_DAT5 64 GND 66 SD_DAT4 68 SD_DAT7 70 SD_DAT6 72 GND 74 VBAT 76 GPIO_VREF(1.8v/3.3v_Input) 78 SCL0 80 SDA0 82 CM5_3.3v 84 CM5_3.3v 86 CM5_1.8v 88 CM5_1.8v 90 PWR_Button 92 CC1 94 CC2 96 GND 98 CAM_GPIO1 100

SoM1B
2x DF40HC(3.0)-100DS-0.4V(51 GND
PWR_FLAG

https://www.envox.eu

Id: 1/5 Title: EEZ BB3+ STM32H7 CM5 module

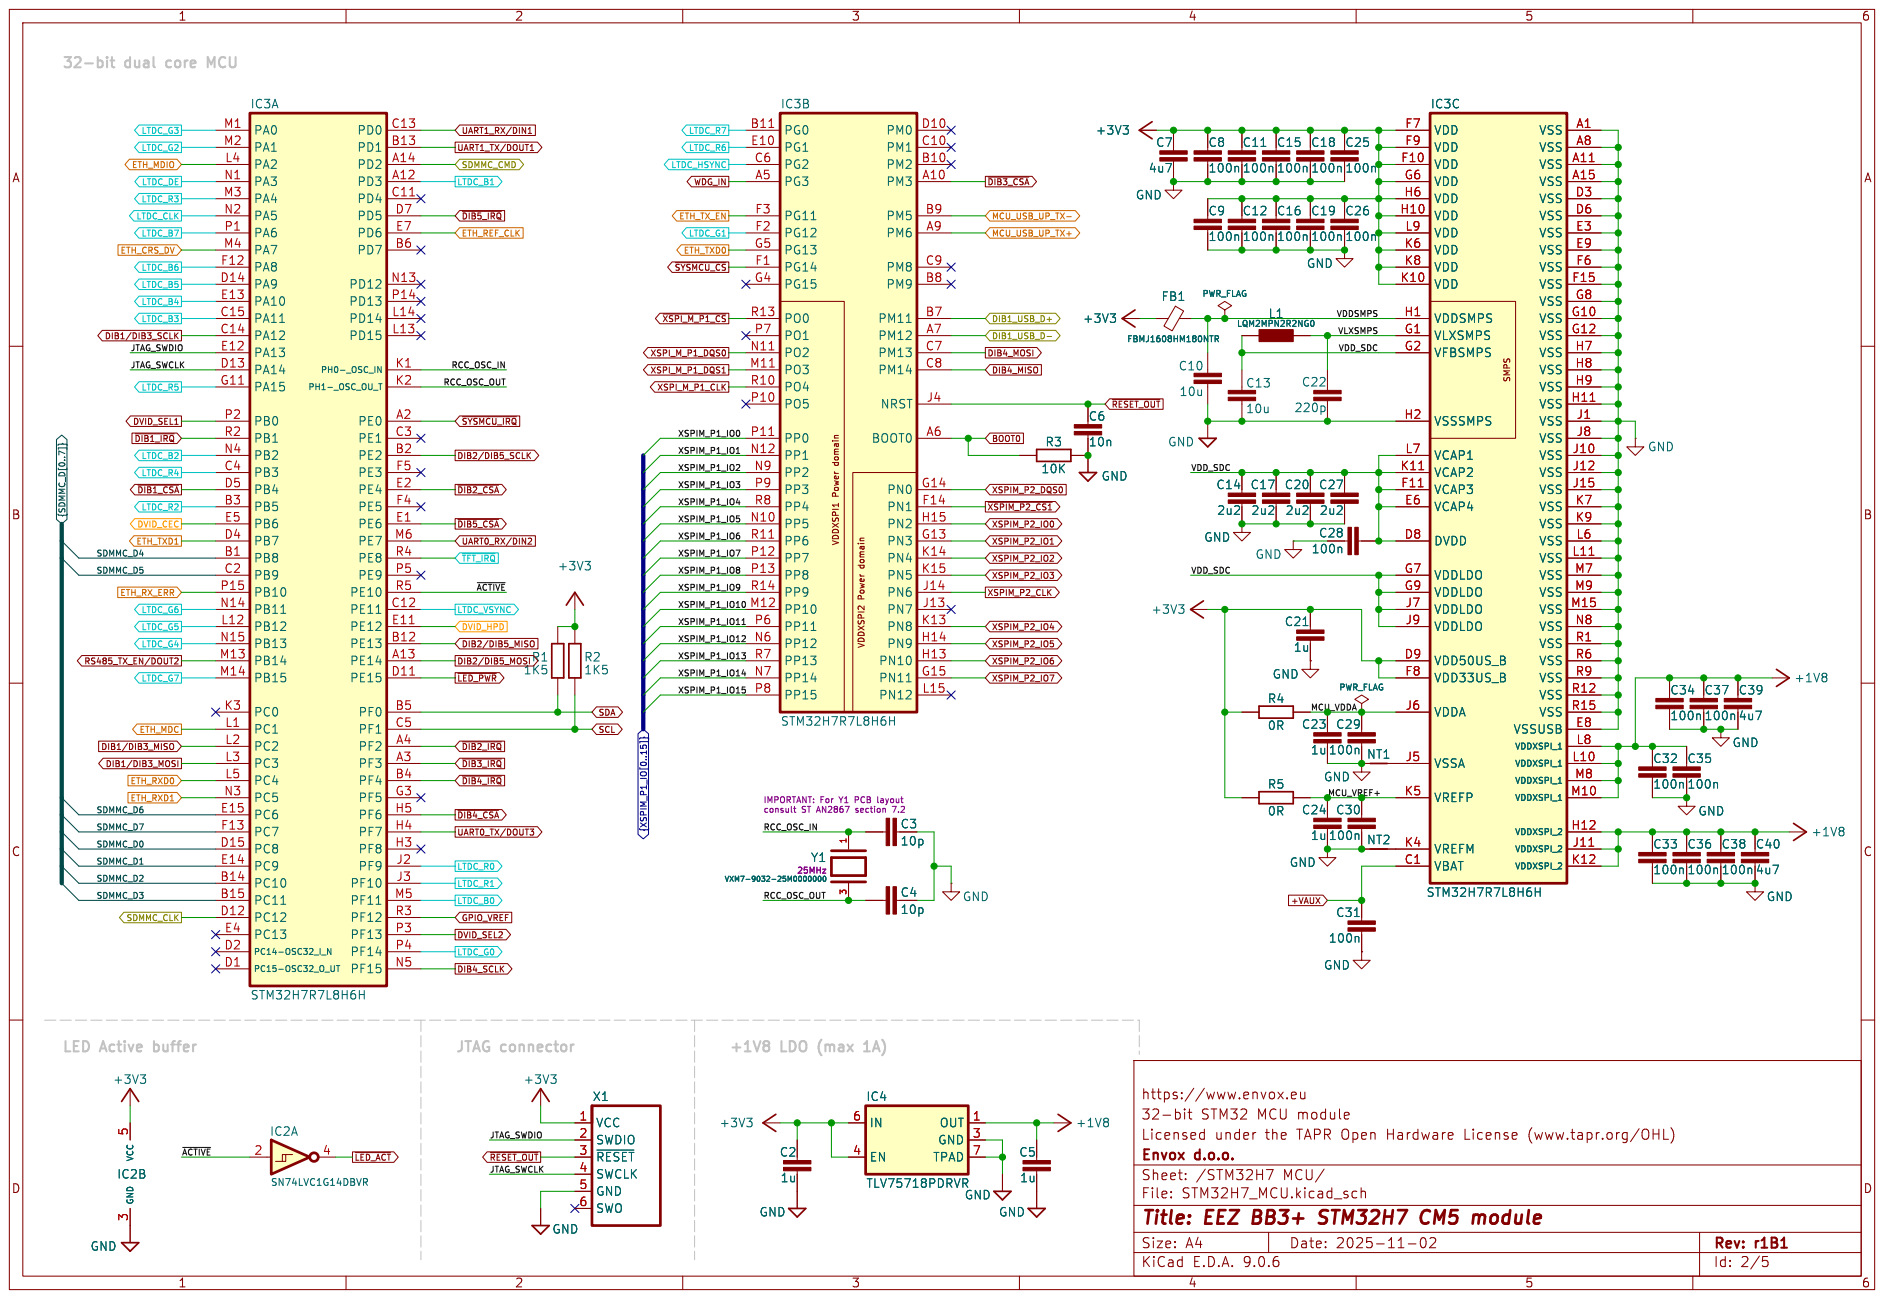
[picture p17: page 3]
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

VDD F7 VDD F9 VDD F10 VDD G6 VDD H6 VDD H10 VDD L9 VDD K6 VDD K8 VDD K10 VDDSMPS H1 VLXSMPS G1 VFBSMPS G2 VSSSMPS H2 VCAP1 L7 VCAP2 K11 VCAP3 F11 VCAP4 E6 DVDD D8 VDDLDO G7 VDDLDO G9 VDDLDO J7 VDDLDO J9 VDD50US_B D9 VDD33US_B F8 VDDA J6 VSSA J5 VREFP K5 VREFM K4 VBAT C1

10n VCC 1 SWDIO 2 ~{RESET} 3 SWCLK 4 GND 5 SWO 6 X1

1u X1VCC 1 SWDIO 2 ~{RESET} 3 SWCLK 4 GND 5 SWO 6 GND

Id: 2/5 Title: EEZ BB3+ STM32H7 CM5 module

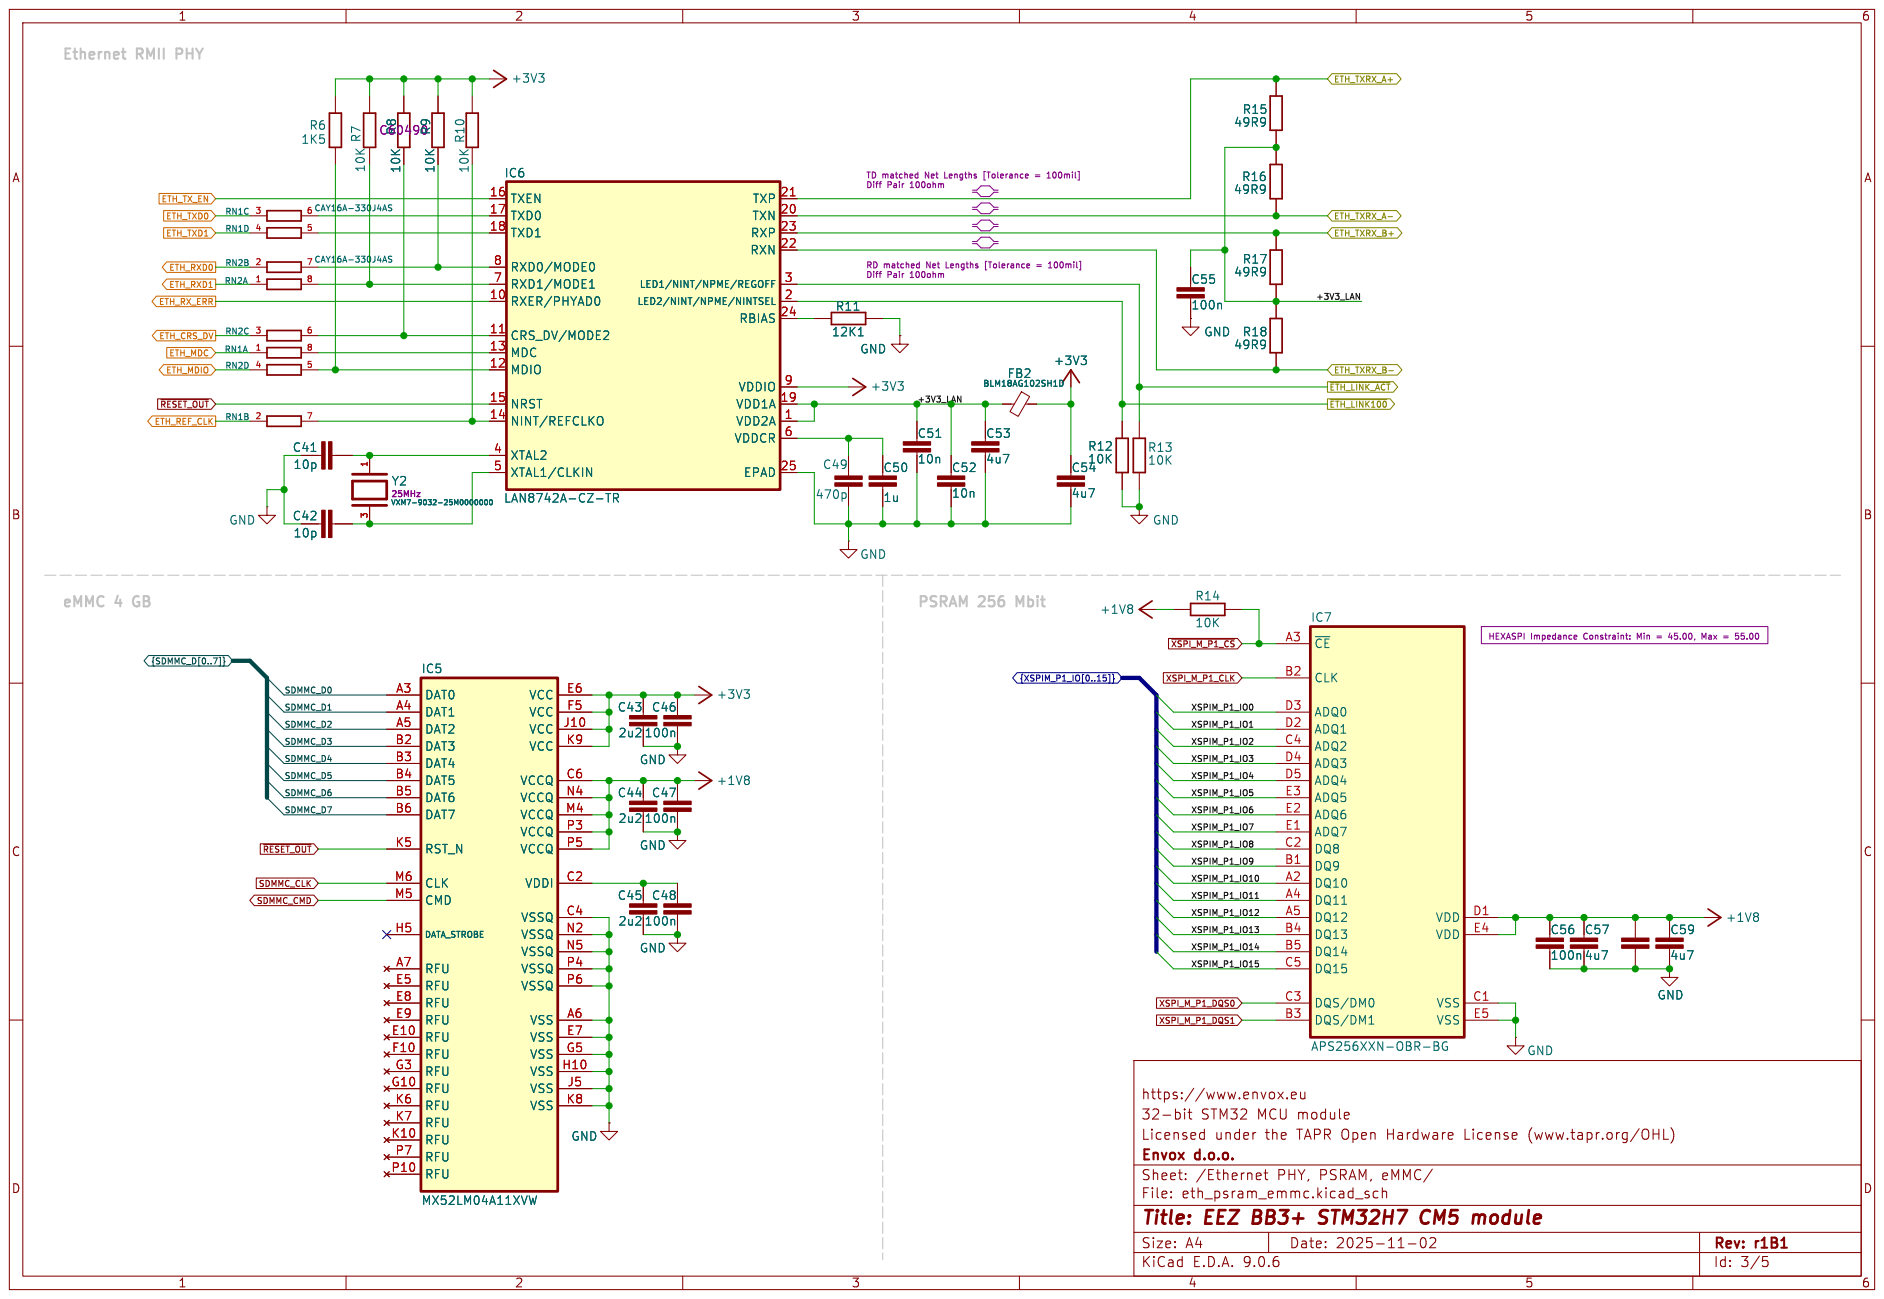
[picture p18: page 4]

https://www.envox.eu GND

Id: 3/5 Title: EEZ BB3+ STM32H7 CM5 module

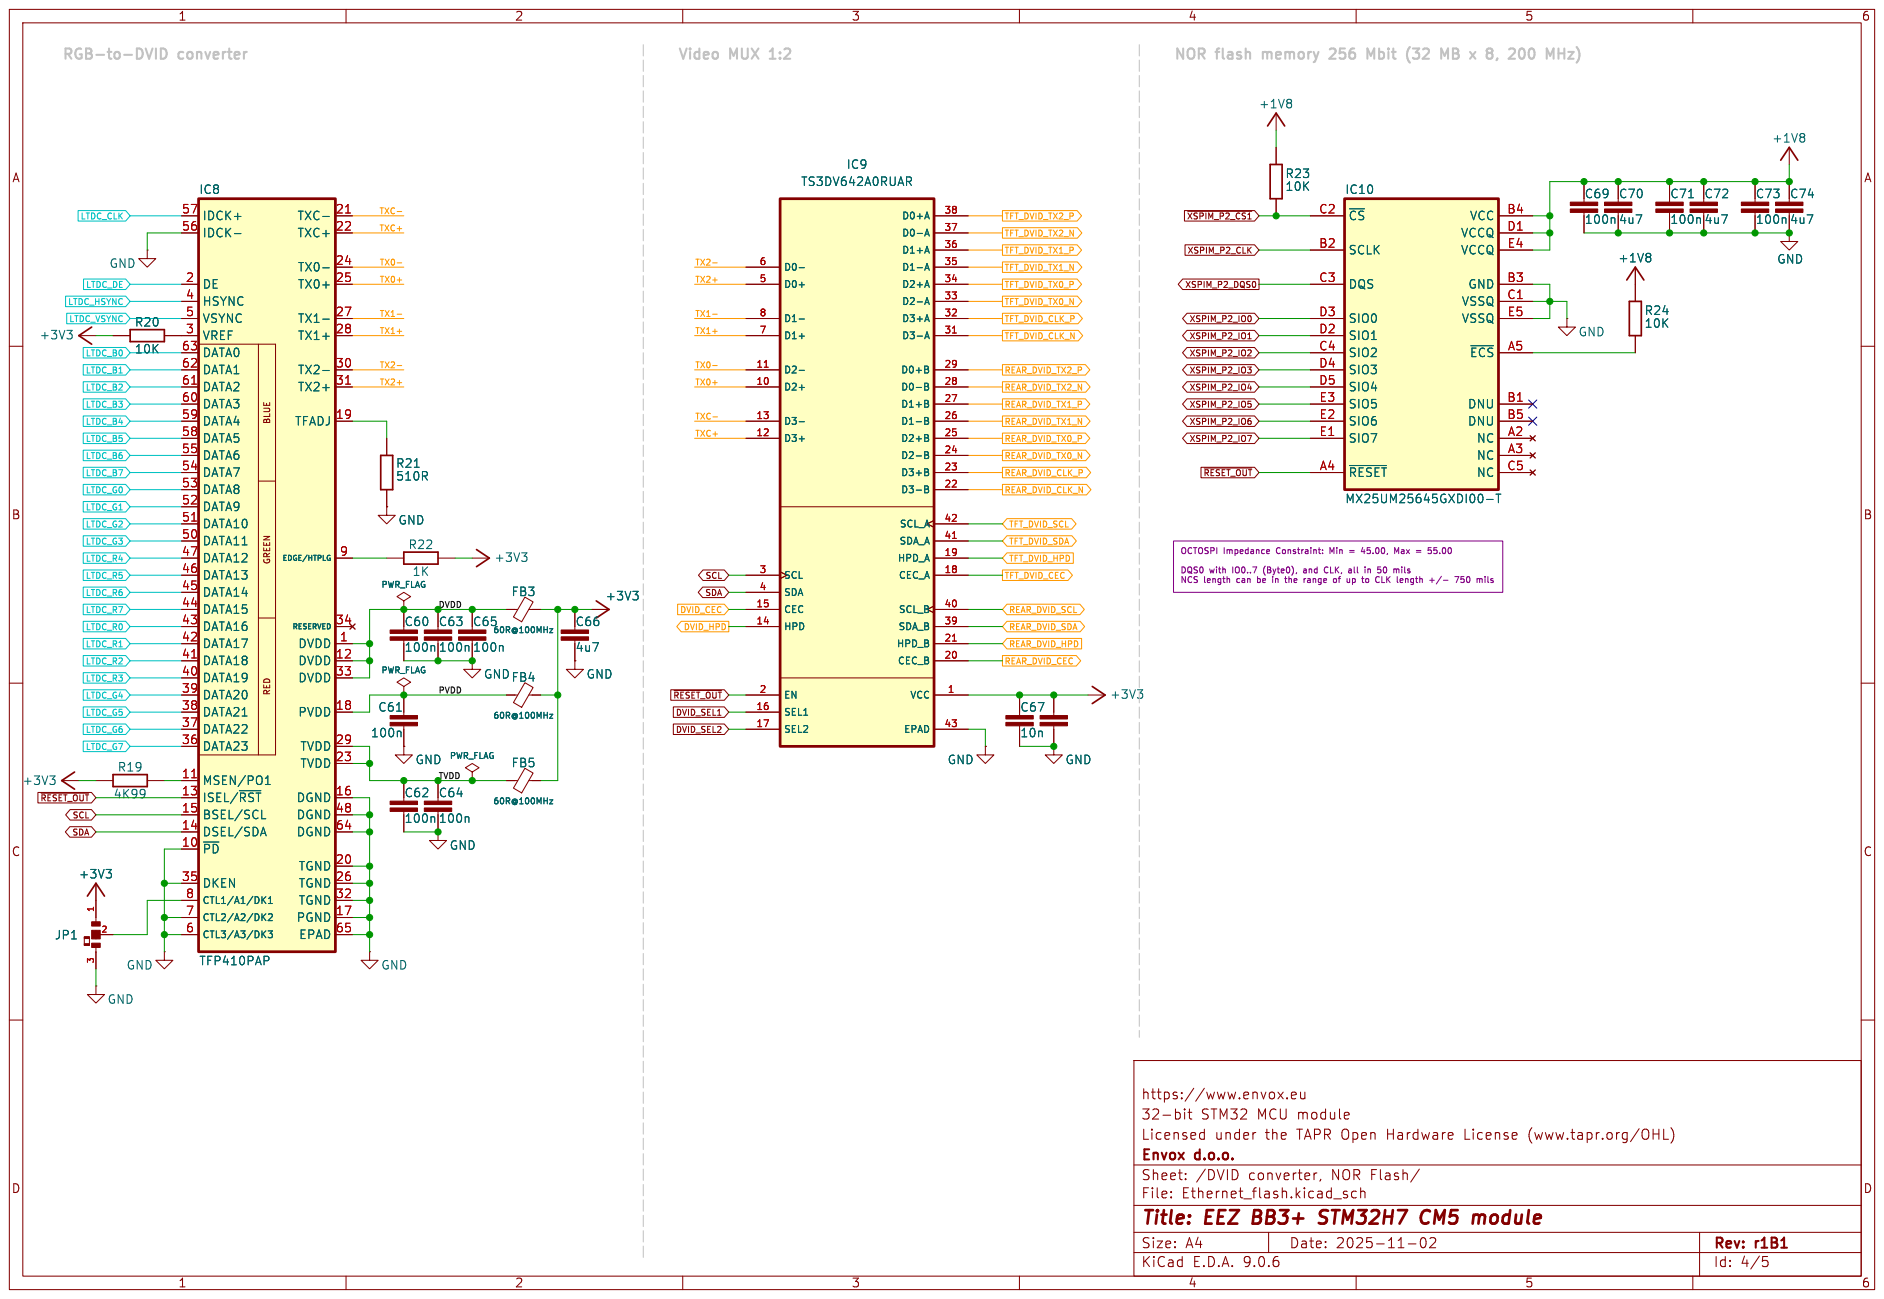
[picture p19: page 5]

TXC- 21 TXC+ 22 TX0- 24 TX0+ 25 TX1- 27 TX1+ 28 TX2- 30 TX2+ 31 TFADJ 19
IDCK- 56 DE 2 HSYNC 4 VSYNC 5 VREF 3 DATA0 63 DATA1 62 DATA2 61 DATA3 60 DATA4 59 DATA5 58 DATA6 55 DATA7 54 DATA8 53 DATA9 52 DATA10 51 DATA11 50 DATA12 47 DATA13 46 DATA14 45 DATA15 44 DATA16 43 DATA17 42 DATA18 41 DATA19 40 DATA20 39 DATA21 38 DATA22 37 DATA23 36 MSEN/PO1 11

https://www.envox.eu GND GND GND

DVDD
RESERVED 34 DVDD 1 DVDD 12 DVDD 33 PVDD 18 TVDD 29 TVDD 23 DGND 16 DGND 48 DGND 64 TGND 20 TGND 26 TGND 32 PGND 17 EPAD 65
100n GND

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

Id: 4/5 Title: EEZ BB3+ STM32H7 CM5 module

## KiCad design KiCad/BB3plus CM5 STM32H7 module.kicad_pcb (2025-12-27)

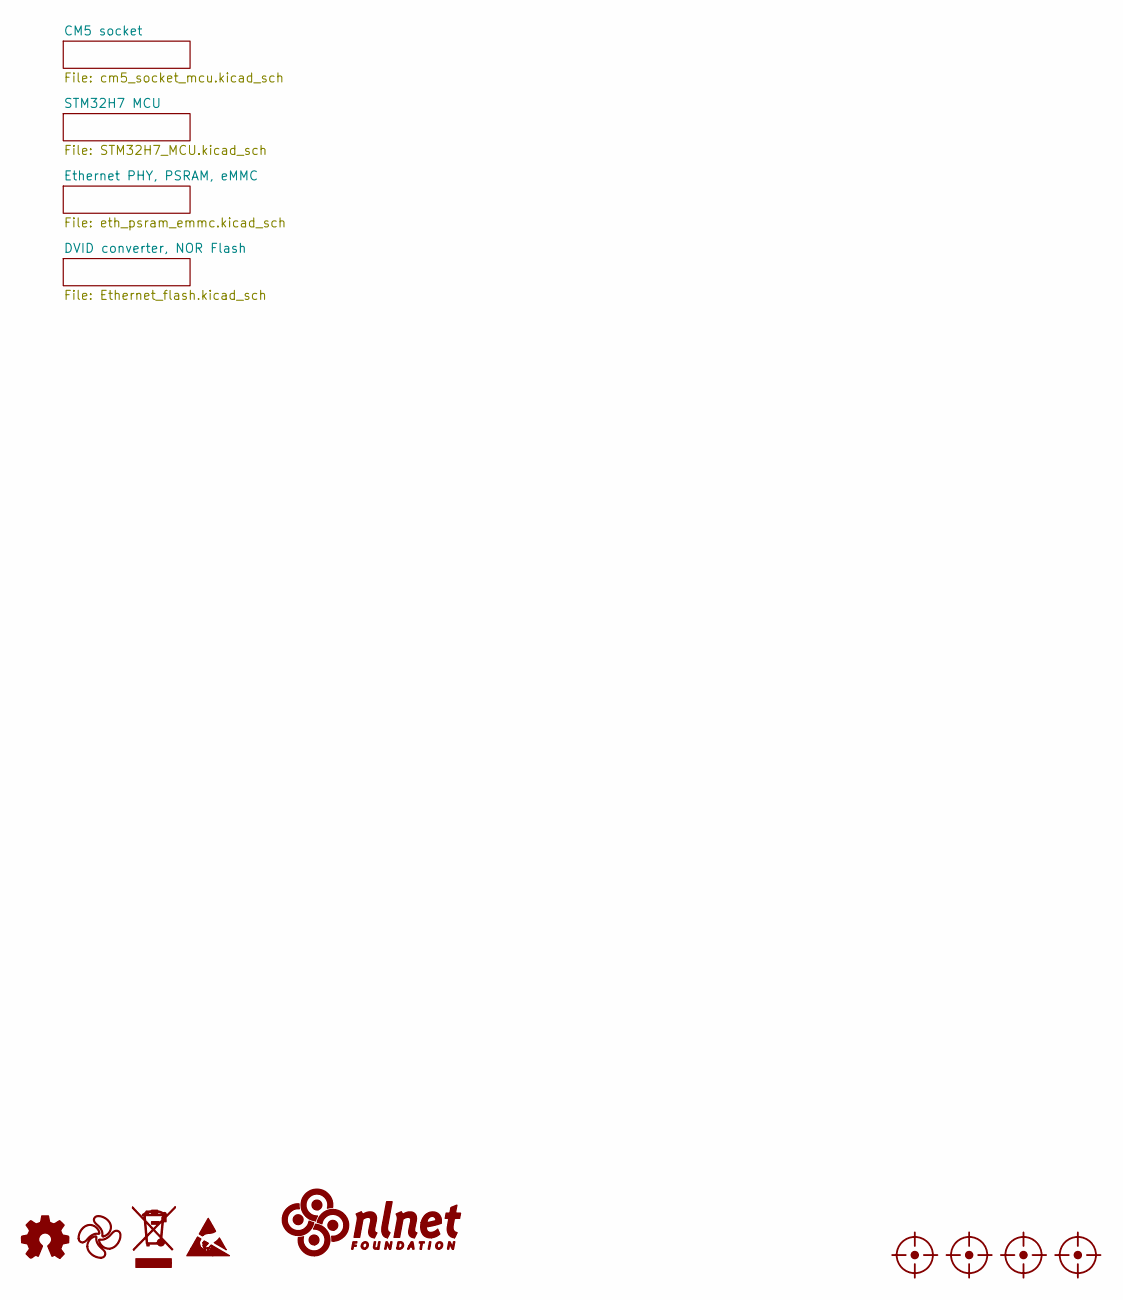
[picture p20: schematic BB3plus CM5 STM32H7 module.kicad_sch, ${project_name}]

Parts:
FM1, FM2, FM3, FM4: Fiducial_0.75mm_Mask1.5mm
LOGO1: Open HW logo
LOGO2: EEZ logo; EEZ logo (outline 6mm)
LOGO3: WEEE logo
LOGO4: ESD logo
LOGO5: NLnet logo

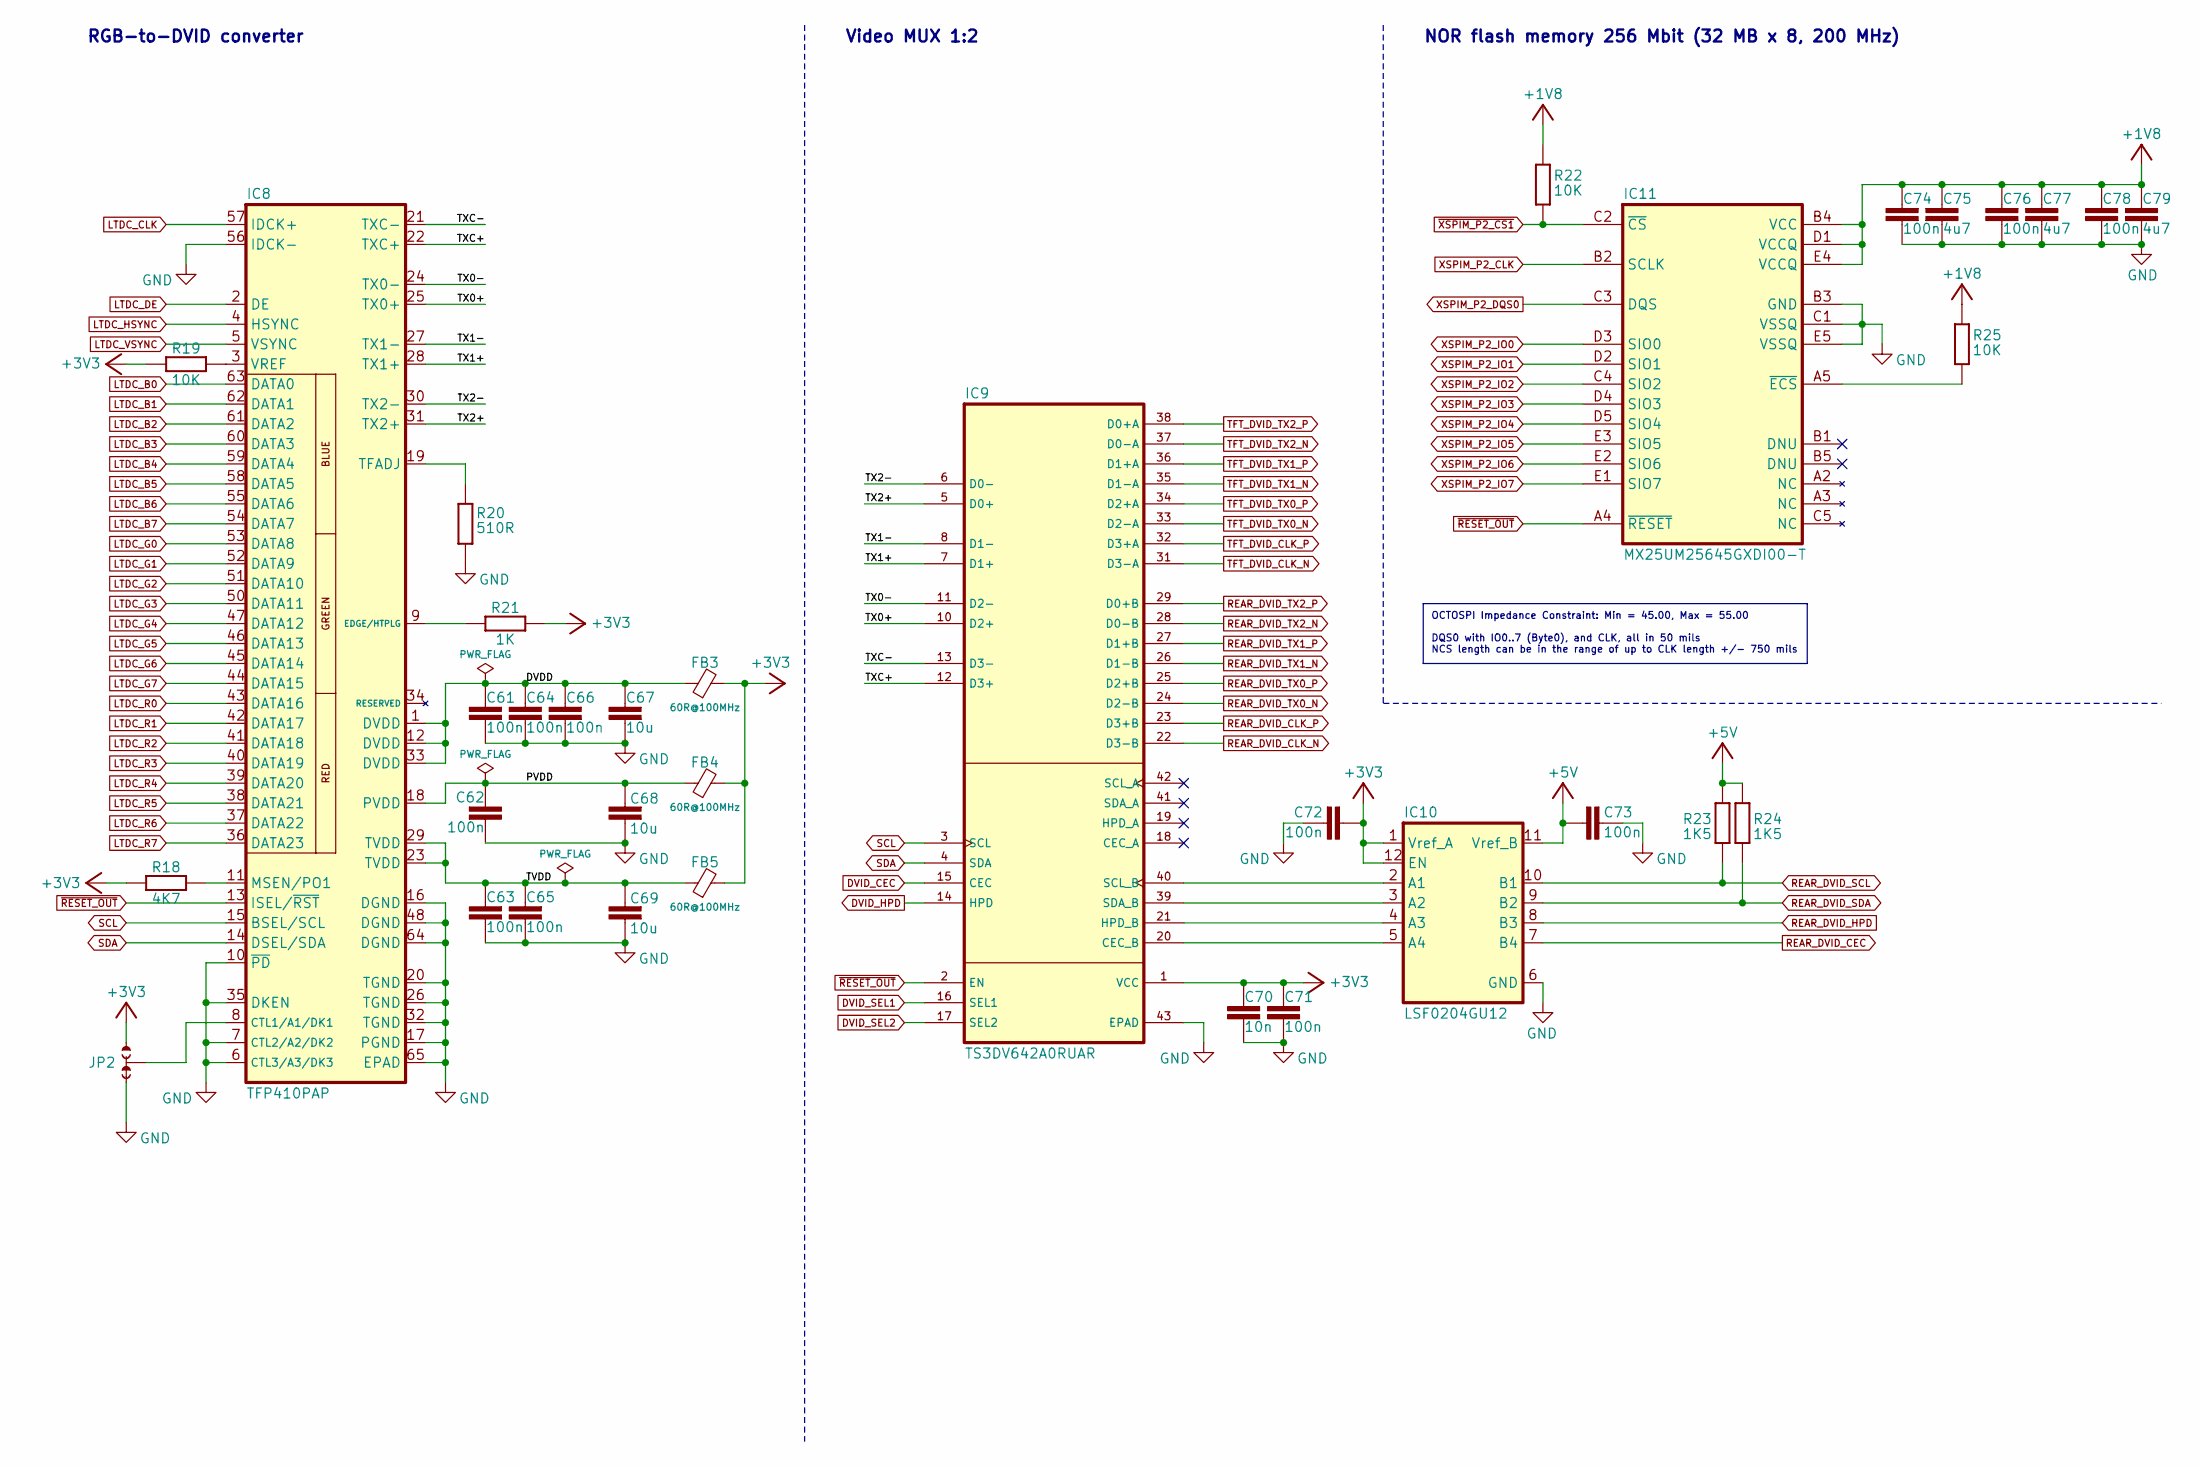
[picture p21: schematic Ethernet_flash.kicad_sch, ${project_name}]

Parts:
C61, C62, C63, C64, C65, C66, C71, C72, C73, C74, C76, C78: 100n; C_0402_1005Metric; DigiKey 490-6287-1-ND
C67, C68, C69: 10u; C_0603_1608Metric; DigiKey 1276-1052-6-ND
C70: 10n; C_0402_1005Metric; DigiKey 490-6309-1-ND
C75, C77, C79: 4u7; C_0603_1608Metric; DigiKey 1276-1044-1-ND
FB3, FB4, FB5: 60R@100MHz; BEAD0603; DigiKey 490-7809-1-ND
IC8: TFP410PAP; PAP64_5X5-L; DigiKey 296-12666-ND
IC9: TS3DV642A0RUAR; RUA42_7P55X2P05; DigiKey 296-39510-1-ND
IC10: LSF0204GU12; XQFN12_SOT1174-1_NEX-L; DigiKey 1727-LSF0102DCHCT-ND
IC11: MX25UM25645GXDI00-T; APS256XXN-OBR-BG_APY-L; DigiKey 1092-MX25UM25645GXDI00-ND
JP2: JP3 shorted (0603)
R18: 4K7; R_0402_1005Metric; DigiKey 13-RC0402FR-104K7LCT-ND
R19, R22, R25: 10K; R_0402_1005Metric; DigiKey 311-10.0KLRCT-ND
R20: 510R; R_0402_1005Metric; DigiKey 13-RC0402FR-13510RLCT-ND
R21: 1K; R_0402_1005Metric; DigiKey 13-RC0402FR-131KLCT-ND
R23, R24: 1K5; R_0402_1005Metric; DigiKey 311-1.50KLRCT-ND

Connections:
+1V8: C74.1, C75.1, C76.1, C77.1, C78.1, C79.1, IC11.B4 (VCC), IC11.D1 (VCCQ), IC11.E4 (VCCQ), R22.2, R25.2; also elsewhere on the board
+3V3: C70.1, C71.1, C72.2, FB3.2, FB4.2, FB5.2, IC9.1 (VCC), IC10.1 (Vref_A), IC10.12 (EN), JP2.NO, R18.1, R19.2, R21.2; also elsewhere on the board
+5V: C73.2, IC10.11 (Vref_B), R23.2, R24.2; also elsewhere on the board
/DVID converter, NOR Flash/DVDD: C61.1, C64.1, C66.1, C67.1, FB3.1, IC8.1 (DVDD), IC8.12 (DVDD), IC8.33 (DVDD)
/DVID converter, NOR Flash/PVDD: C62.1, C68.2, FB4.1, IC8.18 (PVDD)
/DVID converter, NOR Flash/TVDD: C63.1, C65.1, C69.2, FB5.1, IC8.23 (TVDD), IC8.29 (TVDD)
/DVID converter, NOR Flash/TX0+: IC8.25 (TX0+), IC9.10 (D2+)
/DVID converter, NOR Flash/TX0-: IC8.24 (TX0-), IC9.11 (D2-)
/DVID converter, NOR Flash/TX1+: IC8.28 (TX1+), IC9.7 (D1+)
/DVID converter, NOR Flash/TX1-: IC8.27 (TX1-), IC9.8 (D1-)
/DVID converter, NOR Flash/TX2+: IC8.31 (TX2+), IC9.5 (D0+)
/DVID converter, NOR Flash/TX2-: IC8.30 (TX2-), IC9.6 (D0-)
/DVID converter, NOR Flash/TXC+: IC8.22 (TXC+), IC9.12 (D3+)
/DVID converter, NOR Flash/TXC-: IC8.21 (TXC-), IC9.13 (D3-)
DVID_CEC: IC9.15 (CEC); also elsewhere on the board
DVID_HPD: IC9.14 (HPD); also elsewhere on the board
DVID_SEL1: IC9.16 (SEL1); also elsewhere on the board
DVID_SEL2: IC9.17 (SEL2); also elsewhere on the board
GND: C61.2, C62.2, C63.2, C64.2, C65.2, C66.2, C67.2, C68.1, C69.1, C70.2, C71.2, C72.1, C73.1, C74.2, C75.2, C76.2, C77.2, C78.2, C79.2, IC8.6 (CTL3/A3/DK3), IC8.7 (CTL2/A2/DK2), IC8.10 (~PD), IC8.16 (DGND), IC8.17 (PGND), IC8.20 (TGND), IC8.26 (TGND), IC8.32 (TGND), IC8.35 (DKEN), IC8.48 (DGND), IC8.56 (IDCK-), IC8.64 (DGND), IC8.65 (EPAD), IC9.43 (EPAD), IC10.6 (GND), IC11.B3 (GND), IC11.C1 (VSSQ), IC11.E5 (VSSQ), JP2.NC, R20.2; also elsewhere on the board
LTDC_B0: IC8.63 (DATA0); also elsewhere on the board
LTDC_B1: IC8.62 (DATA1); also elsewhere on the board
LTDC_B2: IC8.61 (DATA2); also elsewhere on the board
LTDC_B3: IC8.60 (DATA3); also elsewhere on the board
LTDC_B4: IC8.59 (DATA4); also elsewhere on the board
LTDC_B5: IC8.58 (DATA5); also elsewhere on the board
LTDC_B6: IC8.55 (DATA6); also elsewhere on the board
LTDC_B7: IC8.54 (DATA7); also elsewhere on the board
LTDC_CLK: IC8.57 (IDCK+); also elsewhere on the board
LTDC_DE: IC8.2 (DE); also elsewhere on the board
LTDC_G0: IC8.53 (DATA8); also elsewhere on the board
LTDC_G1: IC8.52 (DATA9); also elsewhere on the board
LTDC_G2: IC8.51 (DATA10); also elsewhere on the board
LTDC_G3: IC8.50 (DATA11); also elsewhere on the board
LTDC_G4: IC8.47 (DATA12); also elsewhere on the board
LTDC_G5: IC8.46 (DATA13); also elsewhere on the board
LTDC_G6: IC8.45 (DATA14); also elsewhere on the board
LTDC_G7: IC8.44 (DATA15); also elsewhere on the board
LTDC_HSYNC: IC8.4 (HSYNC); also elsewhere on the board
LTDC_R0: IC8.43 (DATA16); also elsewhere on the board
LTDC_R1: IC8.42 (DATA17); also elsewhere on the board
LTDC_R2: IC8.41 (DATA18); also elsewhere on the board
LTDC_R3: IC8.40 (DATA19); also elsewhere on the board
LTDC_R4: IC8.39 (DATA20); also elsewhere on the board
LTDC_R5: IC8.38 (DATA21); also elsewhere on the board
LTDC_R6: IC8.37 (DATA22); also elsewhere on the board
LTDC_R7: IC8.36 (DATA23); also elsewhere on the board
LTDC_VSYNC: IC8.5 (VSYNC); also elsewhere on the board
unnamed: IC8.8 (CTL1/A1/DK1), JP2.COM
unnamed: IC8.9 (EDGE/HTPLG), R21.1
unnamed: IC8.11 (MSEN/PO1), R18.2
unnamed: IC8.19 (TFADJ), R20.1
unnamed: IC8.3 (VREF), R19.1
unnamed: IC9.40 (SCL_B), IC10.2 (A1)
unnamed: IC9.39 (SDA_B), IC10.3 (A2)
unnamed: IC9.21 (HPD_B), IC10.4 (A3)
unnamed: IC9.20 (CEC_B), IC10.5 (A4)
unnamed: IC11.A5 (~ECS), R25.1
REAR_DVID_CEC: IC10.7 (B4); also elsewhere on the board
REAR_DVID_CLK_N: IC9.22 (D3-B); also elsewhere on the board
REAR_DVID_CLK_P: IC9.23 (D3+B); also elsewhere on the board
REAR_DVID_HPD: IC10.8 (B3); also elsewhere on the board
REAR_DVID_SCL: IC10.10 (B1), R23.1; also elsewhere on the board
REAR_DVID_SDA: IC10.9 (B2), R24.1; also elsewhere on the board
REAR_DVID_TX0_N: IC9.24 (D2-B); also elsewhere on the board
REAR_DVID_TX0_P: IC9.25 (D2+B); also elsewhere on the board
REAR_DVID_TX1_N: IC9.26 (D1-B); also elsewhere on the board
REAR_DVID_TX1_P: IC9.27 (D1+B); also elsewhere on the board
REAR_DVID_TX2_N: IC9.28 (D0-B); also elsewhere on the board
REAR_DVID_TX2_P: IC9.29 (D0+B); also elsewhere on the board
SCL: IC8.15 (BSEL/SCL), IC9.3 (SCL); also elsewhere on the board
SDA: IC8.14 (DSEL/SDA), IC9.4 (SDA); also elsewhere on the board
TFT_DVID_CLK_N: IC9.31 (D3-A); also elsewhere on the board
TFT_DVID_CLK_P: IC9.32 (D3+A); also elsewhere on the board
TFT_DVID_TX0_N: IC9.33 (D2-A); also elsewhere on the board
TFT_DVID_TX0_P: IC9.34 (D2+A); also elsewhere on the board
TFT_DVID_TX1_N: IC9.35 (D1-A); also elsewhere on the board
TFT_DVID_TX1_P: IC9.36 (D1+A); also elsewhere on the board
TFT_DVID_TX2_N: IC9.37 (D0-A); also elsewhere on the board
TFT_DVID_TX2_P: IC9.38 (D0+A); also elsewhere on the board
XSPIM_P2_CLK: IC11.B2 (SCLK); also elsewhere on the board
XSPIM_P2_DQS0: IC11.C3 (DQS); also elsewhere on the board
XSPIM_P2_IO0: IC11.D3 (SIO0); also elsewhere on the board
XSPIM_P2_IO1: IC11.D2 (SIO1); also elsewhere on the board
XSPIM_P2_IO2: IC11.C4 (SIO2); also elsewhere on the board
XSPIM_P2_IO3: IC11.D4 (SIO3); also elsewhere on the board
XSPIM_P2_IO4: IC11.D5 (SIO4); also elsewhere on the board
XSPIM_P2_IO5: IC11.E3 (SIO5); also elsewhere on the board
XSPIM_P2_IO6: IC11.E2 (SIO6); also elsewhere on the board
XSPIM_P2_IO7: IC11.E1 (SIO7); also elsewhere on the board
~RESET_OUT: IC8.13 (ISEL/~RST), IC9.2 (EN), IC11.A4 (~RESET); also elsewhere on the board
~XSPIM_P2_CS1: IC11.C2 (~CS), R22.1; also elsewhere on the board

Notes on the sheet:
RGB-to-DVID converter
Video MUX 1:2
NOR flash memory 256 Mbit (32 MB x 8, 200 MHz)
OCTOSPI Impedance Constraint: Min = 45.00, Max = 55.00 DQS0 with IO0..7 (Byte0), and CLK, all in 50 mils NCS length can be in the range of up to CLK length +/- 750 mils

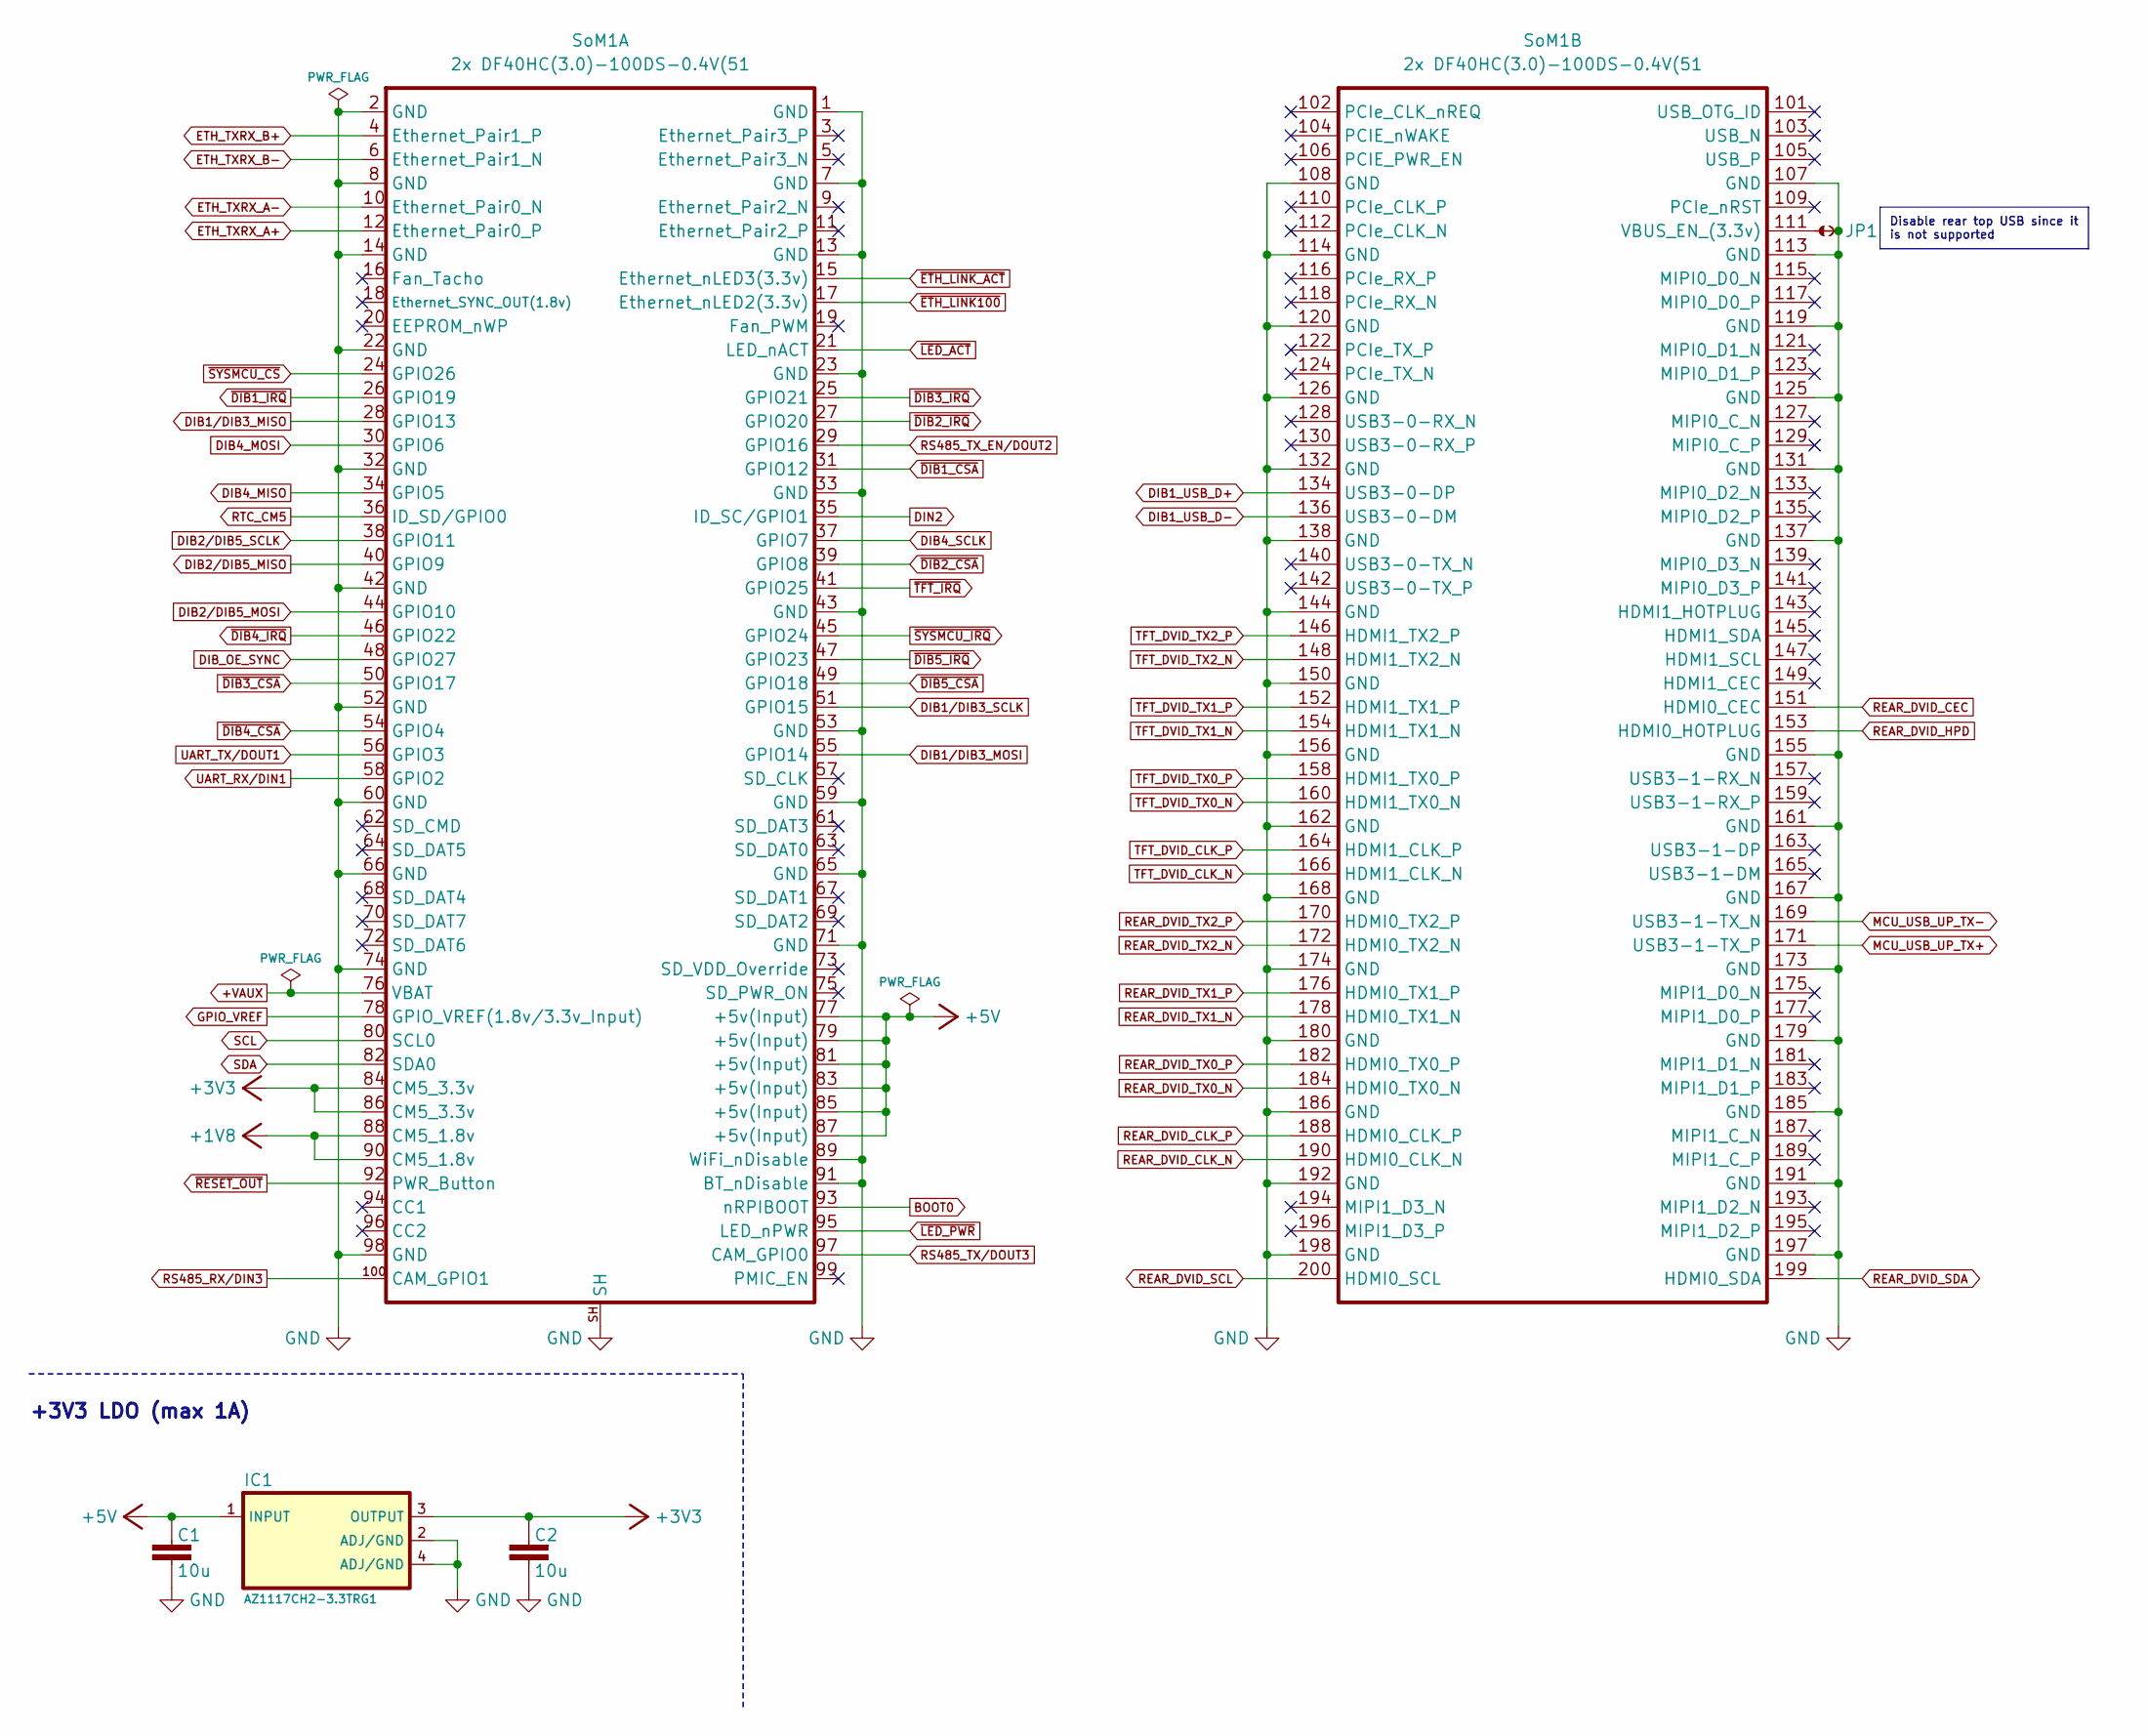
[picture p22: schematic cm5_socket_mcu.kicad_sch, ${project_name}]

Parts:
C1, C2: 10u; C_0603_1608Metric; DigiKey 1276-1052-6-ND
IC1: AZ1117CH2-3.3TRG1; SOT223; DigiKey 31-AZ1117CH2-3.3TRG1CT-ND
JP1: JP2 shorted (0603)
SoM1: 2x DF40HC(3.0)-100DS-0.4V(51; Raspberry-Pi-CM5 (SoM); DigiKey H11614CT-ND

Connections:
+1V8: SoM1.88 (CM5_1.8v), SoM1.90 (CM5_1.8v); also elsewhere on the board
+3V3: C2.2, IC1.3 (OUTPUT), SoM1.84 (CM5_3.3v), SoM1.86 (CM5_3.3v); also elsewhere on the board
+5V: C1.2, IC1.1 (INPUT), SoM1.77 (+5v(Input)), SoM1.79 (+5v(Input)), SoM1.81 (+5v(Input)), SoM1.83 (+5v(Input)), SoM1.85 (+5v(Input)), SoM1.87 (+5v(Input)); also elsewhere on the board
+VAUX: SoM1.76 (VBAT); also elsewhere on the board
BOOT0: SoM1.93 (nRPIBOOT); also elsewhere on the board
DIB1_USB_D+: SoM1.134 (USB3-0-DP); also elsewhere on the board
DIB1_USB_D-: SoM1.136 (USB3-0-DM); also elsewhere on the board
DIB1/DIB3_MISO: SoM1.28 (GPIO13); also elsewhere on the board
DIB1/DIB3_MOSI: SoM1.55 (GPIO14); also elsewhere on the board
DIB1/DIB3_SCLK: SoM1.51 (GPIO15); also elsewhere on the board
DIB2/DIB5_MISO: SoM1.40 (GPIO9); also elsewhere on the board
DIB2/DIB5_MOSI: SoM1.44 (GPIO10); also elsewhere on the board
DIB2/DIB5_SCLK: SoM1.38 (GPIO11); also elsewhere on the board
DIB4_MISO: SoM1.34 (GPIO5); also elsewhere on the board
DIB4_MOSI: SoM1.30 (GPIO6); also elsewhere on the board
DIB4_SCLK: SoM1.37 (GPIO7); also elsewhere on the board
DIB_OE_SYNC: SoM1.48 (GPIO27); also elsewhere on the board
DIN2: SoM1.35 (ID_SC/GPIO1); also elsewhere on the board
ETH_TXRX_A+: SoM1.12 (Ethernet_Pair0_P); also elsewhere on the board
ETH_TXRX_A-: SoM1.10 (Ethernet_Pair0_N); also elsewhere on the board
ETH_TXRX_B+: SoM1.4 (Ethernet_Pair1_P); also elsewhere on the board
ETH_TXRX_B-: SoM1.6 (Ethernet_Pair1_N); also elsewhere on the board
GND: C1.1, C2.1, IC1.2 (ADJ/GND), IC1.4 (ADJ/GND), JP1.2, SoM1.1 (GND), SoM1.2 (GND), SoM1.7 (GND), SoM1.8 (GND), SoM1.13 (GND), SoM1.14 (GND), SoM1.22 (GND), SoM1.23 (GND), SoM1.32 (GND), SoM1.33 (GND), SoM1.42 (GND), SoM1.43 (GND), SoM1.52 (GND), SoM1.53 (GND), SoM1.59 (GND), SoM1.60 (GND), SoM1.65 (GND), SoM1.66 (GND), SoM1.71 (GND), SoM1.74 (GND), SoM1.89 (WiFi_nDisable), SoM1.91 (BT_nDisable), SoM1.98 (GND), SoM1.107 (GND), SoM1.108 (GND), SoM1.113 (GND), SoM1.114 (GND), SoM1.119 (GND), SoM1.120 (GND), SoM1.125 (GND), SoM1.126 (GND), SoM1.131 (GND), SoM1.132 (GND), SoM1.137 (GND), SoM1.138 (GND), SoM1.144 (GND), SoM1.150 (GND), SoM1.155 (GND), SoM1.156 (GND), SoM1.161 (GND), SoM1.162 (GND), SoM1.167 (GND), SoM1.168 (GND), SoM1.173 (GND), SoM1.174 (GND), SoM1.179 (GND), SoM1.180 (GND), SoM1.185 (GND), SoM1.186 (GND), SoM1.191 (GND), SoM1.192 (GND), SoM1.197 (GND), SoM1.198 (GND), SoM1.SH; also elsewhere on the board
GPIO_VREF: SoM1.78 (GPIO_VREF(1.8v/3.3v_Input)); also elsewhere on the board
MCU_USB_UP_TX+: SoM1.171 (USB3-1-TX_P); also elsewhere on the board
MCU_USB_UP_TX-: SoM1.169 (USB3-1-TX_N); also elsewhere on the board
unnamed: JP1.1, SoM1.111 (VBUS_EN_(3.3v))
REAR_DVID_CEC: SoM1.151 (HDMI0_CEC); also elsewhere on the board
REAR_DVID_CLK_N: SoM1.190 (HDMI0_CLK_N); also elsewhere on the board
REAR_DVID_CLK_P: SoM1.188 (HDMI0_CLK_P); also elsewhere on the board
REAR_DVID_HPD: SoM1.153 (HDMI0_HOTPLUG); also elsewhere on the board
REAR_DVID_SCL: SoM1.200 (HDMI0_SCL); also elsewhere on the board
REAR_DVID_SDA: SoM1.199 (HDMI0_SDA); also elsewhere on the board
REAR_DVID_TX0_N: SoM1.184 (HDMI0_TX0_N); also elsewhere on the board
REAR_DVID_TX0_P: SoM1.182 (HDMI0_TX0_P); also elsewhere on the board
REAR_DVID_TX1_N: SoM1.178 (HDMI0_TX1_N); also elsewhere on the board
REAR_DVID_TX1_P: SoM1.176 (HDMI0_TX1_P); also elsewhere on the board
REAR_DVID_TX2_N: SoM1.172 (HDMI0_TX2_N); also elsewhere on the board
REAR_DVID_TX2_P: SoM1.170 (HDMI0_TX2_P); also elsewhere on the board
RS485_RX/DIN3: SoM1.100 (CAM_GPIO1); also elsewhere on the board
RS485_TX_EN/DOUT2: SoM1.29 (GPIO16); also elsewhere on the board
RS485_TX/DOUT3: SoM1.97 (CAM_GPIO0); also elsewhere on the board
RTC_CM5: SoM1.36 (ID_SD/GPIO0); also elsewhere on the board
SCL: SoM1.80 (SCL0); also elsewhere on the board
SDA: SoM1.82 (SDA0); also elsewhere on the board
TFT_DVID_CLK_N: SoM1.166 (HDMI1_CLK_N); also elsewhere on the board
TFT_DVID_CLK_P: SoM1.164 (HDMI1_CLK_P); also elsewhere on the board
TFT_DVID_TX0_N: SoM1.160 (HDMI1_TX0_N); also elsewhere on the board
TFT_DVID_TX0_P: SoM1.158 (HDMI1_TX0_P); also elsewhere on the board
TFT_DVID_TX1_N: SoM1.154 (HDMI1_TX1_N); also elsewhere on the board
TFT_DVID_TX1_P: SoM1.152 (HDMI1_TX1_P); also elsewhere on the board
TFT_DVID_TX2_N: SoM1.148 (HDMI1_TX2_N); also elsewhere on the board
TFT_DVID_TX2_P: SoM1.146 (HDMI1_TX2_P); also elsewhere on the board
UART_RX/DIN1: SoM1.58 (GPIO2); also elsewhere on the board
UART_TX/DOUT1: SoM1.56 (GPIO3); also elsewhere on the board
~DIB1_CSA: SoM1.31 (GPIO12); also elsewhere on the board
~DIB1_IRQ: SoM1.26 (GPIO19); also elsewhere on the board
~DIB2_CSA: SoM1.39 (GPIO8); also elsewhere on the board
~DIB2_IRQ: SoM1.27 (GPIO20); also elsewhere on the board
~DIB3_CSA: SoM1.50 (GPIO17); also elsewhere on the board
~DIB3_IRQ: SoM1.25 (GPIO21); also elsewhere on the board
~DIB4_CSA: SoM1.54 (GPIO4); also elsewhere on the board
~DIB4_IRQ: SoM1.46 (GPIO22); also elsewhere on the board
~DIB5_CSA: SoM1.49 (GPIO18); also elsewhere on the board
~DIB5_IRQ: SoM1.47 (GPIO23); also elsewhere on the board
~ETH_LINK100: SoM1.17 (Ethernet_nLED2(3.3v)); also elsewhere on the board
~ETH_LINK_ACT: SoM1.15 (Ethernet_nLED3(3.3v)); also elsewhere on the board
~LED_ACT: SoM1.21 (LED_nACT); also elsewhere on the board
~LED_PWR: SoM1.95 (LED_nPWR); also elsewhere on the board
~RESET_OUT: SoM1.92 (PWR_Button); also elsewhere on the board
~SYSMCU_CS: SoM1.24 (GPIO26); also elsewhere on the board
~SYSMCU_IRQ: SoM1.45 (GPIO24); also elsewhere on the board
~TFT_IRQ: SoM1.41 (GPIO25); also elsewhere on the board

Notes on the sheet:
+3V3 LDO (max 1A)
Disable rear top USB since it is not supported

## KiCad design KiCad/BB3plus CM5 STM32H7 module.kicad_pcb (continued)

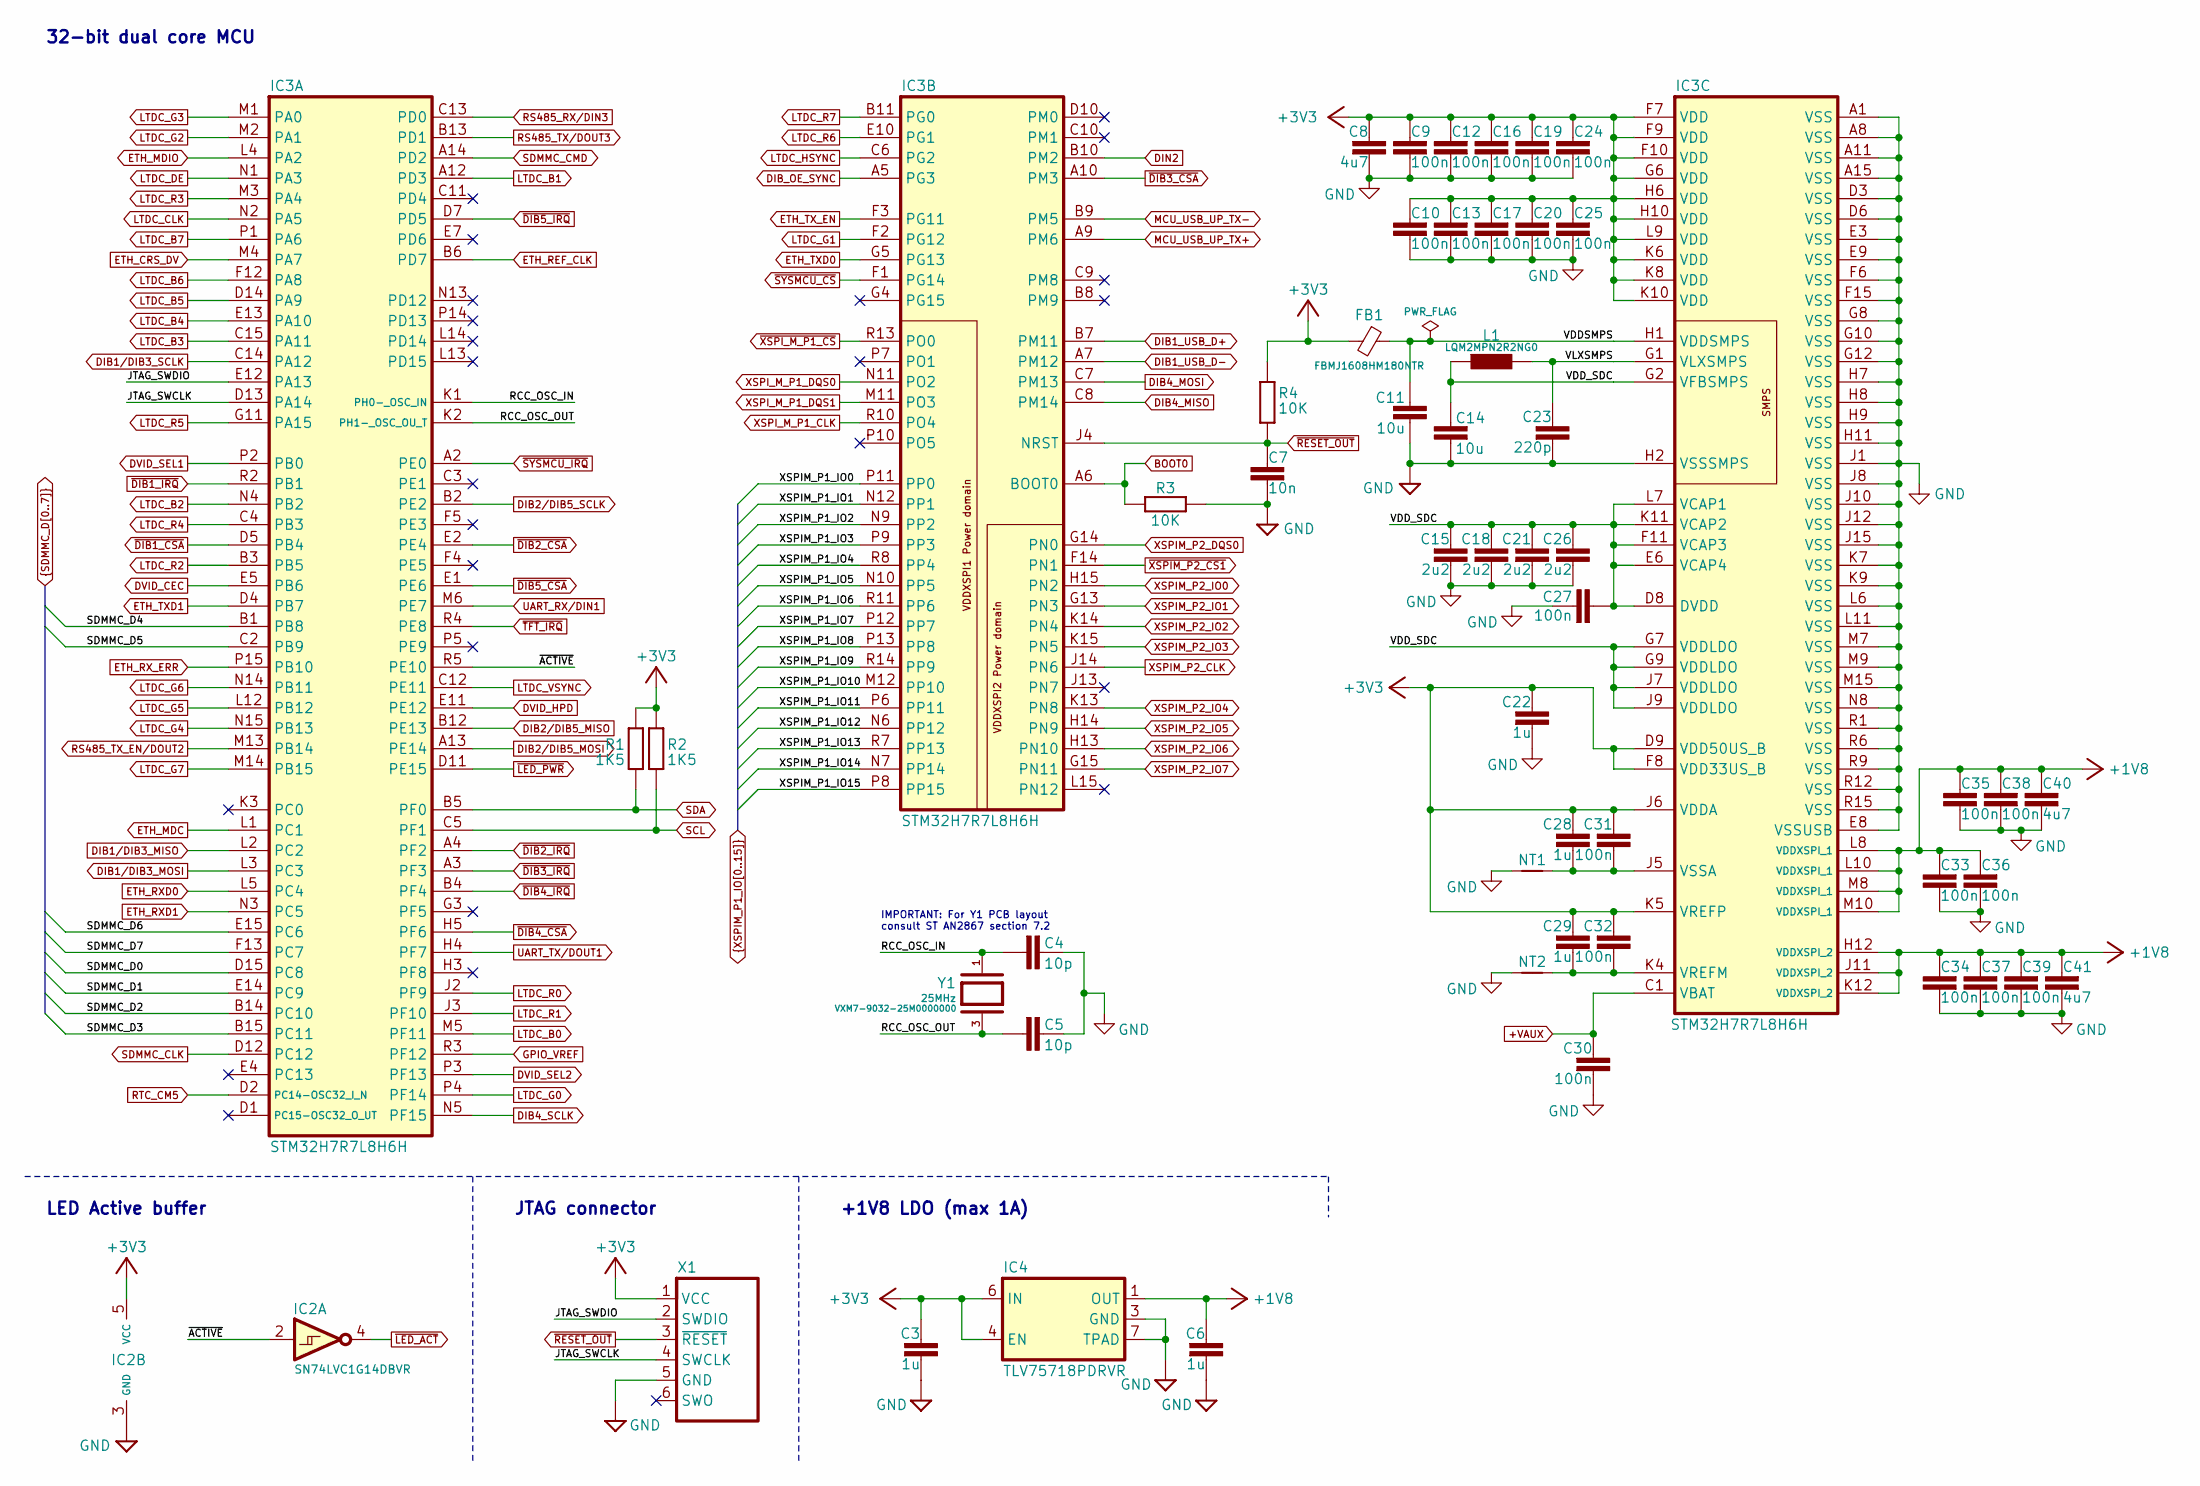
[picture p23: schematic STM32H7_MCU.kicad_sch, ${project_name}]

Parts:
C3, C6, C22, C28, C29: 1u; C_0402_1005Metric; DigiKey 490-GRM155C81A105MA12DCT-ND
C4, C5: 10p; C_0402_1005Metric; DigiKey 490-7299-1-ND
C7: 10n; C_0402_1005Metric; DigiKey 490-6309-1-ND
C8, C40, C41: 4u7; C_0603_1608Metric; DigiKey 1276-1044-1-ND
C9, C10, C12, C13, C16, C17, C19, C20, C24, C25, C27, C30, C31, C32, C33, C34, C35, C36, C37, C38, C39: 100n; C_0402_1005Metric; DigiKey 490-6287-1-ND
C11, C14: 10u; C_0603_1608Metric; DigiKey 1276-1052-6-ND
C15, C18, C21, C26: 2u2; C_0402_1005Metric; DigiKey 490-GRM155C71A225KE11JCT-ND
C23: 220p; C_0402_1005Metric; DigiKey 1276-6762-1-ND
FB1: FBMJ1608HM180NTR; BEAD0603; DigiKey 587-3251-2-ND
IC2: SN74LVC1G14DBVR; DBV5; DigiKey 296-11607-1-ND
IC3: STM32H7R7L8H6H; TFBGA225_13X13_STM; DigiKey 497-STM32H7R7L8H6H-ND
IC4: TLV75718PDRVR; DRV0006A; DigiKey 296-50006-1-ND
L1: LQM2MPN2R2NG0; 0806; DigiKey 490-7786-2-ND
NT1, NT2: NetTie_2; NetTie-2_SMD_Pad0.2mm
R1, R2: 1K5; R_0402_1005Metric; DigiKey 311-1.50KLRCT-ND
R3, R4: 10K; R_0402_1005Metric; DigiKey 311-10.0KLRCT-ND
X1: TC2030
Y1: VXM7-9032-25M0000000; XTAL_403C11A24M00000; DigiKey 150-VXM7-9032-25M0000000CT-ND

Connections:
+1V8: C6.1, C33.1, C34.1, C35.1, C36.1, C37.1, C38.1, C39.1, C40.1, C41.1, IC3.H12 (VDDXSPI_2), IC3.J11 (VDDXSPI_2), IC3.K12 (VDDXSPI_2), IC3.L8 (VDDXSPI_1), IC3.L10 (VDDXSPI_1), IC3.M8 (VDDXSPI_1), IC3.M10 (VDDXSPI_1), IC4.1 (OUT); also elsewhere on the board
+3V3: C3.1, C8.1, C9.1, C10.1, C12.1, C13.1, C16.1, C17.1, C19.1, C20.1, C22.1, C24.1, C25.1, C28.1, C29.1, C31.1, C32.1, FB1.2, IC2.5 (VCC), IC3.D9 (VDD50US_B), IC3.F7 (VDD), IC3.F8 (VDD33US_B), IC3.F9 (VDD), IC3.F10 (VDD), IC3.G6 (VDD), IC3.H6 (VDD), IC3.H10 (VDD), IC3.J6 (VDDA), IC3.K5 (VREFP), IC3.K6 (VDD), IC3.K8 (VDD), IC3.K10 (VDD), IC3.L9 (VDD), IC4.4 (EN), IC4.6 (IN), R1.2, R2.2, R4.2, X1.1 (VCC); also elsewhere on the board
+VAUX: C30.1, IC3.C1 (VBAT); also elsewhere on the board
/STM32H7 MCU/JTAG_SWCLK: IC3.D13 (PA14), X1.4 (SWCLK)
/STM32H7 MCU/JTAG_SWDIO: IC3.E12 (PA13), X1.2 (SWDIO)
/STM32H7 MCU/RCC_OSC_IN: C4.2, IC3.K1 (PH0-_OSC_IN), Y1.1
/STM32H7 MCU/RCC_OSC_OUT: C5.2, IC3.K2 (PH1-_OSC_OU_T), Y1.3
/STM32H7 MCU/VDDSMPS: C11.2, FB1.1, IC3.H1 (VDDSMPS)
/STM32H7 MCU/VDD_SDC: C14.2, C15.1, C18.1, C21.1, C26.1, C27.2, IC3.D8 (DVDD), IC3.E6 (VCAP4), IC3.F11 (VCAP3), IC3.G2 (VFBSMPS), IC3.G7 (VDDLDO), IC3.G9 (VDDLDO), IC3.J7 (VDDLDO), IC3.J9 (VDDLDO), IC3.K11 (VCAP2), IC3.L7 (VCAP1), L1.1
/STM32H7 MCU/VLXSMPS: C23.1, IC3.G1 (VLXSMPS), L1.2
/STM32H7 MCU/~ACTIVE: IC2.2 (A), IC3.R5 (PE10)
BOOT0: IC3.A6 (BOOT0), R3.1; also elsewhere on the board
DIB1_USB_D+: IC3.B7 (PM11); also elsewhere on the board
DIB1_USB_D-: IC3.A7 (PM12); also elsewhere on the board
DIB1/DIB3_MISO: IC3.L2 (PC2); also elsewhere on the board
DIB1/DIB3_MOSI: IC3.L3 (PC3); also elsewhere on the board
DIB1/DIB3_SCLK: IC3.C14 (PA12); also elsewhere on the board
DIB2/DIB5_MISO: IC3.B12 (PE13); also elsewhere on the board
DIB2/DIB5_MOSI: IC3.A13 (PE14); also elsewhere on the board
DIB2/DIB5_SCLK: IC3.B2 (PE2); also elsewhere on the board
DIB4_MISO: IC3.C8 (PM14); also elsewhere on the board
DIB4_MOSI: IC3.C7 (PM13); also elsewhere on the board
DIB4_SCLK: IC3.N5 (PF15); also elsewhere on the board
DIB_OE_SYNC: IC3.A5 (PG3); also elsewhere on the board
DIN2: IC3.B10 (PM2); also elsewhere on the board
DVID_CEC: IC3.E5 (PB6); also elsewhere on the board
DVID_HPD: IC3.E11 (PE12); also elsewhere on the board
DVID_SEL1: IC3.P2 (PB0); also elsewhere on the board
DVID_SEL2: IC3.P3 (PF13); also elsewhere on the board
ETH_CRS_DV: IC3.M4 (PA7); also elsewhere on the board
ETH_MDC: IC3.L1 (PC1); also elsewhere on the board
ETH_MDIO: IC3.L4 (PA2); also elsewhere on the board
ETH_REF_CLK: IC3.B6 (PD7); also elsewhere on the board
ETH_RXD0: IC3.L5 (PC4); also elsewhere on the board
ETH_RXD1: IC3.N3 (PC5); also elsewhere on the board
ETH_RX_ERR: IC3.P15 (PB10); also elsewhere on the board
ETH_TXD0: IC3.G5 (PG13); also elsewhere on the board
ETH_TXD1: IC3.D4 (PB7); also elsewhere on the board
ETH_TX_EN: IC3.F3 (PG11); also elsewhere on the board
GND: C3.2, C4.1, C5.1, C6.2, C7.2, C8.2, C9.2, C10.2, C11.1, C12.2, C13.2, C14.1, C15.2, C16.2, C17.2, C18.2, C19.2, C20.2, C21.2, C22.2, C23.2, C24.2, C25.2, C26.2, C27.1, C30.2, C33.2, C34.2, C35.2, C36.2, C37.2, C38.2, C39.2, C40.2, C41.2, IC2.3 (GND), IC3.A1 (VSS), IC3.A8 (VSS), IC3.A11 (VSS), IC3.A15 (VSS), IC3.D3 (VSS), IC3.D6 (VSS), IC3.E3 (VSS), IC3.E8 (VSSUSB), IC3.E9 (VSS), IC3.F6 (VSS), IC3.F15 (VSS), IC3.G8 (VSS), IC3.G10 (VSS), IC3.G12 (VSS), IC3.H2 (VSSSMPS), IC3.H7 (VSS), IC3.H8 (VSS), IC3.H9 (VSS), IC3.H11 (VSS), IC3.J1 (VSS), IC3.J8 (VSS), IC3.J10 (VSS), IC3.J12 (VSS), IC3.J15 (VSS), IC3.K7 (VSS), IC3.K9 (VSS), IC3.L6 (VSS), IC3.L11 (VSS), IC3.M7 (VSS), IC3.M9 (VSS), IC3.M15 (VSS), IC3.N8 (VSS), IC3.R1 (VSS), IC3.R6 (VSS), IC3.R9 (VSS), IC3.R12 (VSS), IC3.R15 (VSS), IC4.3 (GND), IC4.7 (TPAD), NT1.1, NT2.1, R3.2, X1.5 (GND); also elsewhere on the board
GPIO_VREF: IC3.R3 (PF12); also elsewhere on the board
LTDC_B0: IC3.M5 (PF11); also elsewhere on the board
LTDC_B1: IC3.A12 (PD3); also elsewhere on the board
LTDC_B2: IC3.N4 (PB2); also elsewhere on the board
LTDC_B3: IC3.C15 (PA11); also elsewhere on the board
LTDC_B4: IC3.E13 (PA10); also elsewhere on the board
LTDC_B5: IC3.D14 (PA9); also elsewhere on the board
LTDC_B6: IC3.F12 (PA8); also elsewhere on the board
LTDC_B7: IC3.P1 (PA6); also elsewhere on the board
LTDC_CLK: IC3.N2 (PA5); also elsewhere on the board
LTDC_DE: IC3.N1 (PA3); also elsewhere on the board
LTDC_G0: IC3.P4 (PF14); also elsewhere on the board
LTDC_G1: IC3.F2 (PG12); also elsewhere on the board
LTDC_G2: IC3.M2 (PA1); also elsewhere on the board
LTDC_G3: IC3.M1 (PA0); also elsewhere on the board
LTDC_G4: IC3.N15 (PB13); also elsewhere on the board
LTDC_G5: IC3.L12 (PB12); also elsewhere on the board
LTDC_G6: IC3.N14 (PB11); also elsewhere on the board
LTDC_G7: IC3.M14 (PB15); also elsewhere on the board
LTDC_HSYNC: IC3.C6 (PG2); also elsewhere on the board
LTDC_R0: IC3.J2 (PF9); also elsewhere on the board
LTDC_R1: IC3.J3 (PF10); also elsewhere on the board
LTDC_R2: IC3.B3 (PB5); also elsewhere on the board
LTDC_R3: IC3.M3 (PA4); also elsewhere on the board
LTDC_R4: IC3.C4 (PB3); also elsewhere on the board
LTDC_R5: IC3.G11 (PA15); also elsewhere on the board
LTDC_R6: IC3.E10 (PG1); also elsewhere on the board
LTDC_R7: IC3.B11 (PG0); also elsewhere on the board
LTDC_VSYNC: IC3.C12 (PE11); also elsewhere on the board
MCU_USB_UP_TX+: IC3.A9 (PM6); also elsewhere on the board
MCU_USB_UP_TX-: IC3.B9 (PM5); also elsewhere on the board
unnamed: C29.2, C32.2, IC3.K4 (VREFM), NT2.2
unnamed: C28.2, C31.2, IC3.J5 (VSSA), NT1.2
RS485_RX/DIN3: IC3.C13 (PD0); also elsewhere on the board
RS485_TX_EN/DOUT2: IC3.M13 (PB14); also elsewhere on the board
RS485_TX/DOUT3: IC3.B13 (PD1); also elsewhere on the board
RTC_CM5: IC3.D2 (PC14-OSC32_I_N); also elsewhere on the board
SCL: IC3.C5 (PF1), R2.1; also elsewhere on the board
SDA: IC3.B5 (PF0), R1.1; also elsewhere on the board
SDMMC_CLK: IC3.D12 (PC12); also elsewhere on the board
SDMMC_CMD: IC3.A14 (PD2); also elsewhere on the board
SDMMC_D0: IC3.D15 (PC8); also elsewhere on the board
SDMMC_D1: IC3.E14 (PC9); also elsewhere on the board
SDMMC_D2: IC3.B14 (PC10); also elsewhere on the board
SDMMC_D3: IC3.B15 (PC11); also elsewhere on the board
SDMMC_D4: IC3.B1 (PB8); also elsewhere on the board
SDMMC_D5: IC3.C2 (PB9); also elsewhere on the board
SDMMC_D6: IC3.E15 (PC6); also elsewhere on the board
SDMMC_D7: IC3.F13 (PC7); also elsewhere on the board
UART_RX/DIN1: IC3.M6 (PE7); also elsewhere on the board
UART_TX/DOUT1: IC3.H4 (PF7); also elsewhere on the board
XSPIM_P1_IO0: IC3.P11 (PP0); also elsewhere on the board
XSPIM_P1_IO1: IC3.N12 (PP1); also elsewhere on the board
XSPIM_P1_IO2: IC3.N9 (PP2); also elsewhere on the board
XSPIM_P1_IO3: IC3.P9 (PP3); also elsewhere on the board
XSPIM_P1_IO4: IC3.R8 (PP4); also elsewhere on the board
XSPIM_P1_IO5: IC3.N10 (PP5); also elsewhere on the board
XSPIM_P1_IO6: IC3.R11 (PP6); also elsewhere on the board
XSPIM_P1_IO7: IC3.P12 (PP7); also elsewhere on the board
XSPIM_P1_IO8: IC3.P13 (PP8); also elsewhere on the board
XSPIM_P1_IO9: IC3.R14 (PP9); also elsewhere on the board
XSPIM_P1_IO10: IC3.M12 (PP10); also elsewhere on the board
XSPIM_P1_IO11: IC3.P6 (PP11); also elsewhere on the board
XSPIM_P1_IO12: IC3.N6 (PP12); also elsewhere on the board
XSPIM_P1_IO13: IC3.R7 (PP13); also elsewhere on the board
XSPIM_P1_IO14: IC3.N7 (PP14); also elsewhere on the board
XSPIM_P1_IO15: IC3.P8 (PP15); also elsewhere on the board
XSPIM_P2_CLK: IC3.J14 (PN6); also elsewhere on the board
XSPIM_P2_DQS0: IC3.G14 (PN0); also elsewhere on the board
XSPIM_P2_IO0: IC3.H15 (PN2); also elsewhere on the board
XSPIM_P2_IO1: IC3.G13 (PN3); also elsewhere on the board
XSPIM_P2_IO2: IC3.K14 (PN4); also elsewhere on the board
XSPIM_P2_IO3: IC3.K15 (PN5); also elsewhere on the board
XSPIM_P2_IO4: IC3.K13 (PN8); also elsewhere on the board
XSPIM_P2_IO5: IC3.H14 (PN9); also elsewhere on the board
XSPIM_P2_IO6: IC3.H13 (PN10); also elsewhere on the board
XSPIM_P2_IO7: IC3.G15 (PN11); also elsewhere on the board
XSPI_M_P1_CLK: IC3.R10 (PO4); also elsewhere on the board
XSPI_M_P1_DQS0: IC3.N11 (PO2); also elsewhere on the board
XSPI_M_P1_DQS1: IC3.M11 (PO3); also elsewhere on the board
~DIB1_CSA: IC3.D5 (PB4); also elsewhere on the board
~DIB1_IRQ: IC3.R2 (PB1); also elsewhere on the board
~DIB2_CSA: IC3.E2 (PE4); also elsewhere on the board
~DIB2_IRQ: IC3.A4 (PF2); also elsewhere on the board
~DIB3_CSA: IC3.A10 (PM3); also elsewhere on the board
~DIB3_IRQ: IC3.A3 (PF3); also elsewhere on the board
~DIB4_CSA: IC3.H5 (PF6); also elsewhere on the board
~DIB4_IRQ: IC3.B4 (PF4); also elsewhere on the board
~DIB5_CSA: IC3.E1 (PE6); also elsewhere on the board
~DIB5_IRQ: IC3.D7 (PD5); also elsewhere on the board
~LED_ACT: IC2.4 (Y); also elsewhere on the board
~LED_PWR: IC3.D11 (PE15); also elsewhere on the board
~RESET_OUT: C7.1, IC3.J4 (NRST), R4.1, X1.3 (~RESET); also elsewhere on the board
~SYSMCU_CS: IC3.F1 (PG14); also elsewhere on the board
~SYSMCU_IRQ: IC3.A2 (PE0); also elsewhere on the board
~TFT_IRQ: IC3.R4 (PE8); also elsewhere on the board
~XSPIM_P2_CS1: IC3.F14 (PN1); also elsewhere on the board
~XSPI_M_P1_CS: IC3.R13 (PO0); also elsewhere on the board

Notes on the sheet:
32-bit dual core MCU
LED Active buffer
JTAG connector
IMPORTANT: For Y1 PCB layout consult ST AN2867 section 7.2
+1V8 LDO (max 1A)

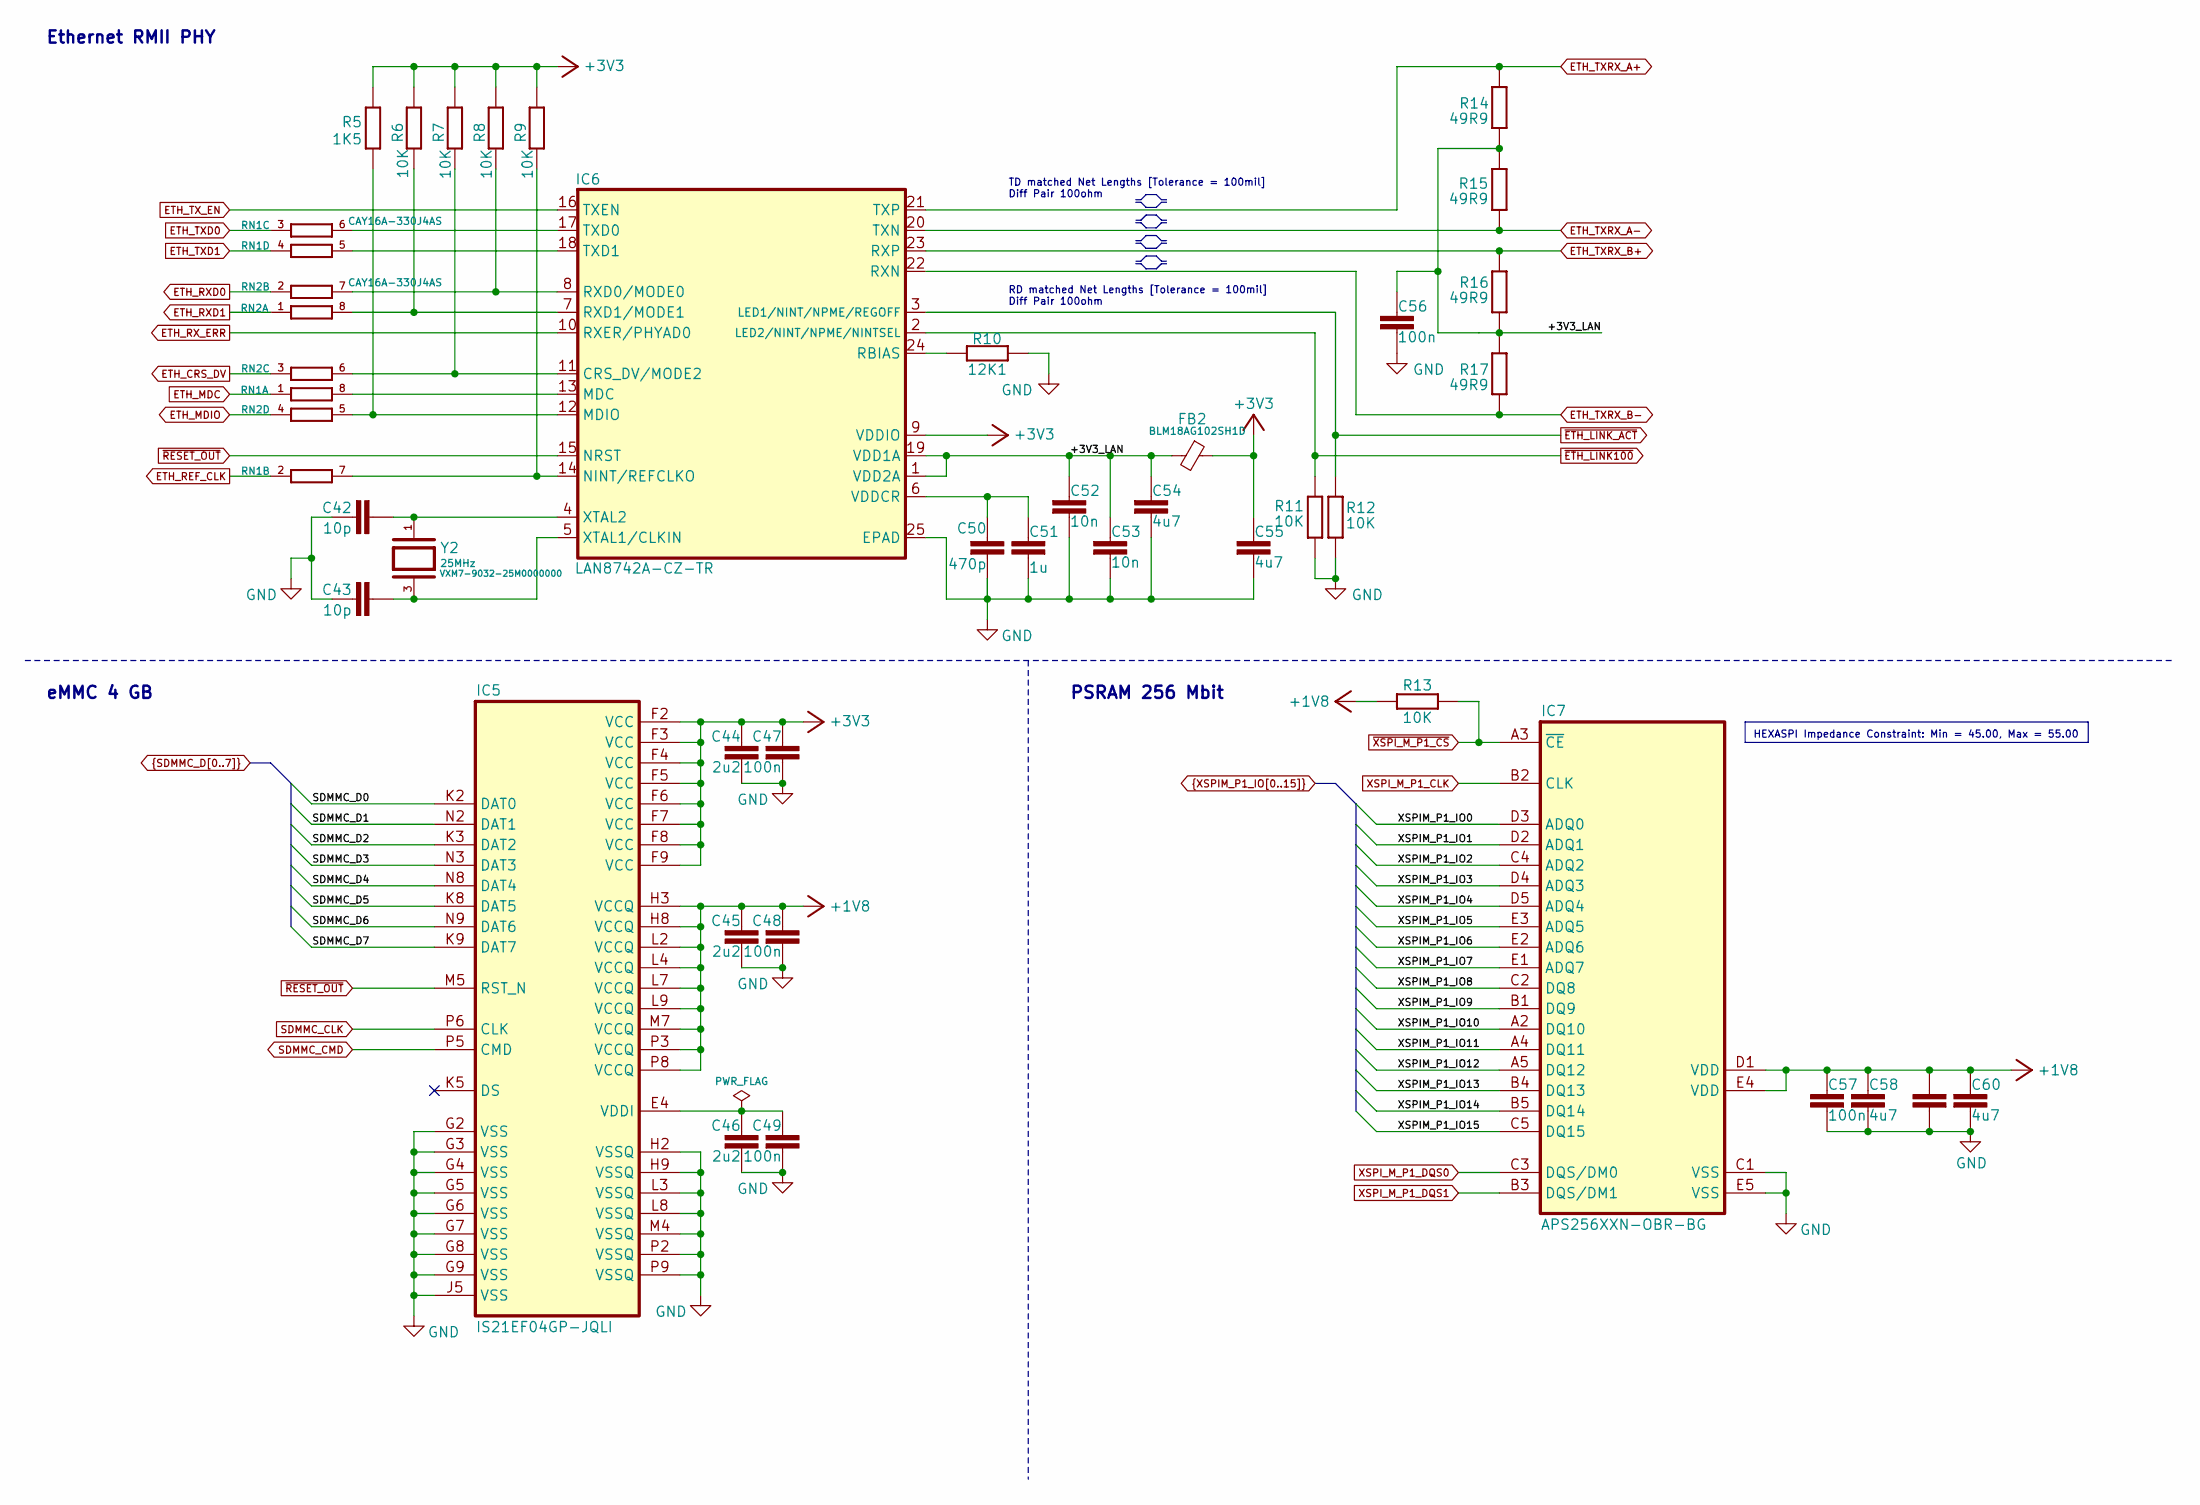
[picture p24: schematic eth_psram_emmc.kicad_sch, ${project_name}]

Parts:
C42, C43: 10p; C_0402_1005Metric; DigiKey 490-7299-1-ND
C44, C45, C46: 2u2; C_0402_1005Metric; DigiKey 490-GRM155C71A225KE11JCT-ND
C47, C48, C49, C56, C57, C59: 100n; C_0402_1005Metric; DigiKey 490-6287-1-ND
C50: 470p; C_0402_1005Metric; DigiKey 1276-1117-1-ND
C51: 1u; C_0402_1005Metric; DigiKey 490-GRM155C81A105MA12DCT-ND
C52, C53: 10n; C_0402_1005Metric; DigiKey 490-6309-1-ND
C54, C55, C58, C60: 4u7; C_0603_1608Metric; DigiKey 1276-1044-1-ND
FB2: BLM18AG102SH1D; BEAD0603; DigiKey 490-7809-1-ND
IC5: IS21EF04GP-JQLI; DigiKey 706-IS21EF04GP-JQLI-ND
IC6: LAN8742A-CZ-TR; SQFN24_4X4MC_MCH-M; DigiKey LAN8742A-CZ-CT-ND
IC7: APS256XXN-OBR-BG; APS256XXN-OBR-BG_APY-L; Mouser 878-APS256XXN-OB9-BG
R5: 1K5; R_0402_1005Metric; DigiKey 311-1.50KLRCT-ND
R6, R7, R8, R9, R11, R12, R13: 10K; R_0402_1005Metric; DigiKey 311-10.0KLRCT-ND
R10: 12K1; R_0402_1005Metric; DigiKey 13-RC0402FR-1012K1LCT-ND
R14, R15, R16, R17: 49R9; R_0402_1005Metric; DigiKey 13-RC0402FR-1349R9LCT-ND
RN1, RN2: CAY16A-330J4AS; CAY16; DigiKey CAY16-330J4LFCT-ND
Y2: VXM7-9032-25M0000000; XTAL_403C11A24M00000; DigiKey 150-VXM7-9032-25M0000000CT-ND

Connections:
+1V8: C45.1, C48.1, C57.1, C58.1, C59.1, C60.1, IC5.H3 (VCCQ), IC5.H8 (VCCQ), IC5.L2 (VCCQ), IC5.L4 (VCCQ), IC5.L7 (VCCQ), IC5.L9 (VCCQ), IC5.M7 (VCCQ), IC5.P3 (VCCQ), IC5.P8 (VCCQ), IC7.D1 (VDD), IC7.E4 (VDD), R13.2; also elsewhere on the board
+3V3: C44.1, C47.1, C55.1, FB2.1, IC5.F2 (VCC), IC5.F3 (VCC), IC5.F4 (VCC), IC5.F5 (VCC), IC5.F6 (VCC), IC5.F7 (VCC), IC5.F8 (VCC), IC5.F9 (VCC), IC6.9 (VDDIO), R5.2, R6.1, R7.2, R8.2, R9.2; also elsewhere on the board
/Ethernet PHY, PSRAM, eMMC/+3V3_LAN: C52.1, C53.1, C54.1, C56.2, FB2.2, IC6.1 (VDD2A), IC6.19 (VDD1A), R14.1, R15.1, R16.1, R17.2
ETH_CRS_DV: RN2.3 (1); also elsewhere on the board
ETH_MDC: RN1.1; also elsewhere on the board
ETH_MDIO: RN2.4 (1); also elsewhere on the board
ETH_REF_CLK: RN1.2 (1); also elsewhere on the board
ETH_RXD0: RN2.2 (1); also elsewhere on the board
ETH_RXD1: RN2.1; also elsewhere on the board
ETH_RX_ERR: IC6.10 (RXER/PHYAD0); also elsewhere on the board
ETH_TXD0: RN1.3 (1); also elsewhere on the board
ETH_TXD1: RN1.4 (1); also elsewhere on the board
ETH_TXRX_A+: IC6.21 (TXP), R14.2; also elsewhere on the board
ETH_TXRX_A-: IC6.20 (TXN), R15.2; also elsewhere on the board
ETH_TXRX_B+: IC6.23 (RXP), R16.2; also elsewhere on the board
ETH_TXRX_B-: IC6.22 (RXN), R17.1; also elsewhere on the board
ETH_TX_EN: IC6.16 (TXEN); also elsewhere on the board
GND: C42.1, C43.1, C44.2, C45.2, C46.2, C47.2, C48.2, C49.2, C50.2, C51.1, C52.2, C53.2, C54.2, C55.2, C56.1, C57.2, C58.2, C59.2, C60.2, IC5.G2 (VSS), IC5.G3 (VSS), IC5.G4 (VSS), IC5.G5 (VSS), IC5.G6 (VSS), IC5.G7 (VSS), IC5.G8 (VSS), IC5.G9 (VSS), IC5.H2 (VSSQ), IC5.H9 (VSSQ), IC5.J5 (VSS), IC5.L3 (VSSQ), IC5.L8 (VSSQ), IC5.M4 (VSSQ), IC5.P2 (VSSQ), IC5.P9 (VSSQ), IC6.25 (EPAD), IC7.C1 (VSS), IC7.E5 (VSS), R10.2, R11.2, R12.1; also elsewhere on the board
unnamed: C46.1, C49.1, IC5.E4 (VDDI)
unnamed: IC6.11 (CRS_DV/MODE2), R7.1, RN2.6 (2)
unnamed: IC6.13 (MDC), RN1.8 (2)
unnamed: IC6.12 (MDIO), R5.1, RN2.5 (2)
unnamed: IC6.14 (NINT/REFCLKO), R9.1, RN1.7 (2)
unnamed: IC6.24 (RBIAS), R10.1
unnamed: IC6.8 (RXD0/MODE0), R8.1, RN2.7 (2)
unnamed: IC6.7 (RXD1/MODE1), R6.2, RN2.8 (2)
unnamed: IC6.17 (TXD0), RN1.6 (2)
unnamed: IC6.18 (TXD1), RN1.5 (2)
unnamed: C50.1, C51.2, IC6.6 (VDDCR)
unnamed: C43.2, IC6.5 (XTAL1/CLKIN), Y2.3
unnamed: C42.2, IC6.4 (XTAL2), Y2.1
SDMMC_CLK: IC5.P6 (CLK); also elsewhere on the board
SDMMC_CMD: IC5.P5 (CMD); also elsewhere on the board
SDMMC_D0: IC5.K2 (DAT0); also elsewhere on the board
SDMMC_D1: IC5.N2 (DAT1); also elsewhere on the board
SDMMC_D2: IC5.K3 (DAT2); also elsewhere on the board
SDMMC_D3: IC5.N3 (DAT3); also elsewhere on the board
SDMMC_D4: IC5.N8 (DAT4); also elsewhere on the board
SDMMC_D5: IC5.K8 (DAT5); also elsewhere on the board
SDMMC_D6: IC5.N9 (DAT6); also elsewhere on the board
SDMMC_D7: IC5.K9 (DAT7); also elsewhere on the board
XSPIM_P1_IO0: IC7.D3 (ADQ0); also elsewhere on the board
XSPIM_P1_IO1: IC7.D2 (ADQ1); also elsewhere on the board
XSPIM_P1_IO2: IC7.C4 (ADQ2); also elsewhere on the board
XSPIM_P1_IO3: IC7.D4 (ADQ3); also elsewhere on the board
XSPIM_P1_IO4: IC7.D5 (ADQ4); also elsewhere on the board
XSPIM_P1_IO5: IC7.E3 (ADQ5); also elsewhere on the board
XSPIM_P1_IO6: IC7.E2 (ADQ6); also elsewhere on the board
XSPIM_P1_IO7: IC7.E1 (ADQ7); also elsewhere on the board
XSPIM_P1_IO8: IC7.C2 (DQ8); also elsewhere on the board
XSPIM_P1_IO9: IC7.B1 (DQ9); also elsewhere on the board
XSPIM_P1_IO10: IC7.A2 (DQ10); also elsewhere on the board
XSPIM_P1_IO11: IC7.A4 (DQ11); also elsewhere on the board
XSPIM_P1_IO12: IC7.A5 (DQ12); also elsewhere on the board
XSPIM_P1_IO13: IC7.B4 (DQ13); also elsewhere on the board
XSPIM_P1_IO14: IC7.B5 (DQ14); also elsewhere on the board
XSPIM_P1_IO15: IC7.C5 (DQ15); also elsewhere on the board
XSPI_M_P1_CLK: IC7.B2 (CLK); also elsewhere on the board
XSPI_M_P1_DQS0: IC7.C3 (DQS/DM0); also elsewhere on the board
XSPI_M_P1_DQS1: IC7.B3 (DQS/DM1); also elsewhere on the board
~ETH_LINK100: IC6.2 (LED2/NINT/NPME/NINTSEL), R11.1; also elsewhere on the board
~ETH_LINK_ACT: IC6.3 (LED1/NINT/NPME/REGOFF), R12.2; also elsewhere on the board
~RESET_OUT: IC5.M5 (RST_N), IC6.15 (NRST); also elsewhere on the board
~XSPI_M_P1_CS: IC7.A3 (~CE), R13.1; also elsewhere on the board

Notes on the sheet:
TD matched Net Lengths [Tolerance = 100mil] Diff Pair 100ohm
eMMC 4 GB
PSRAM 256 Mbit
Ethernet RMII PHY
RD matched Net Lengths [Tolerance = 100mil] Diff Pair 100ohm
HEXASPI Impedance Constraint: Min = 45.00, Max = 55.00

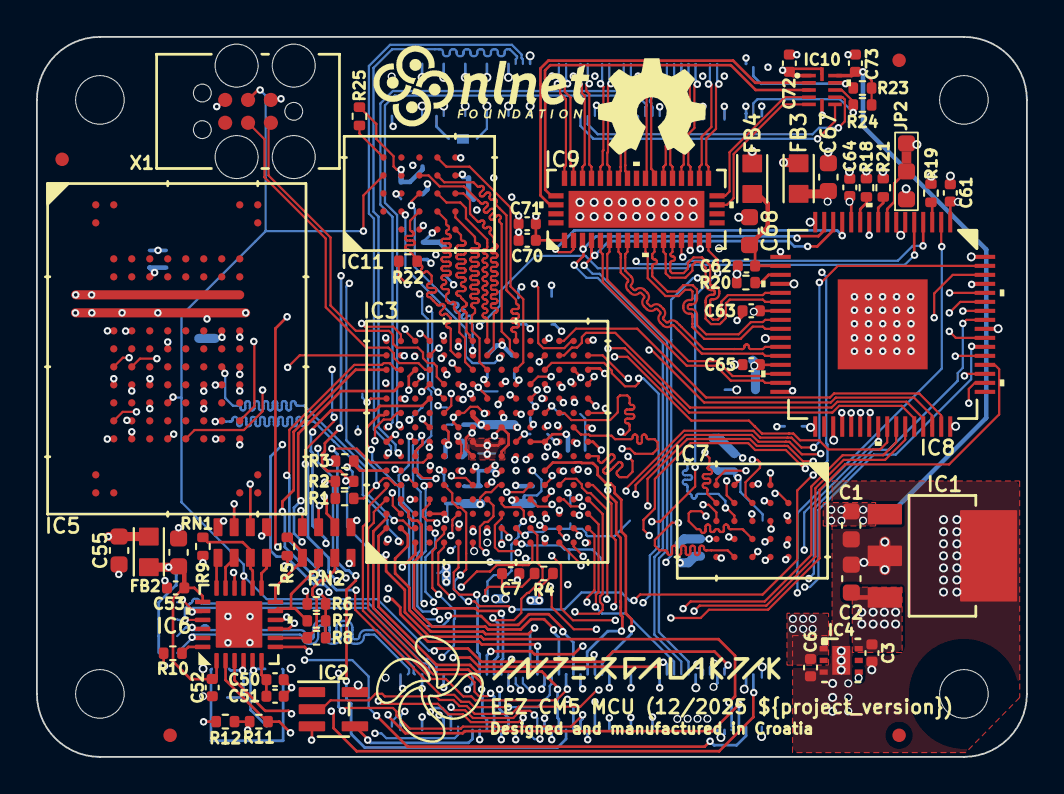
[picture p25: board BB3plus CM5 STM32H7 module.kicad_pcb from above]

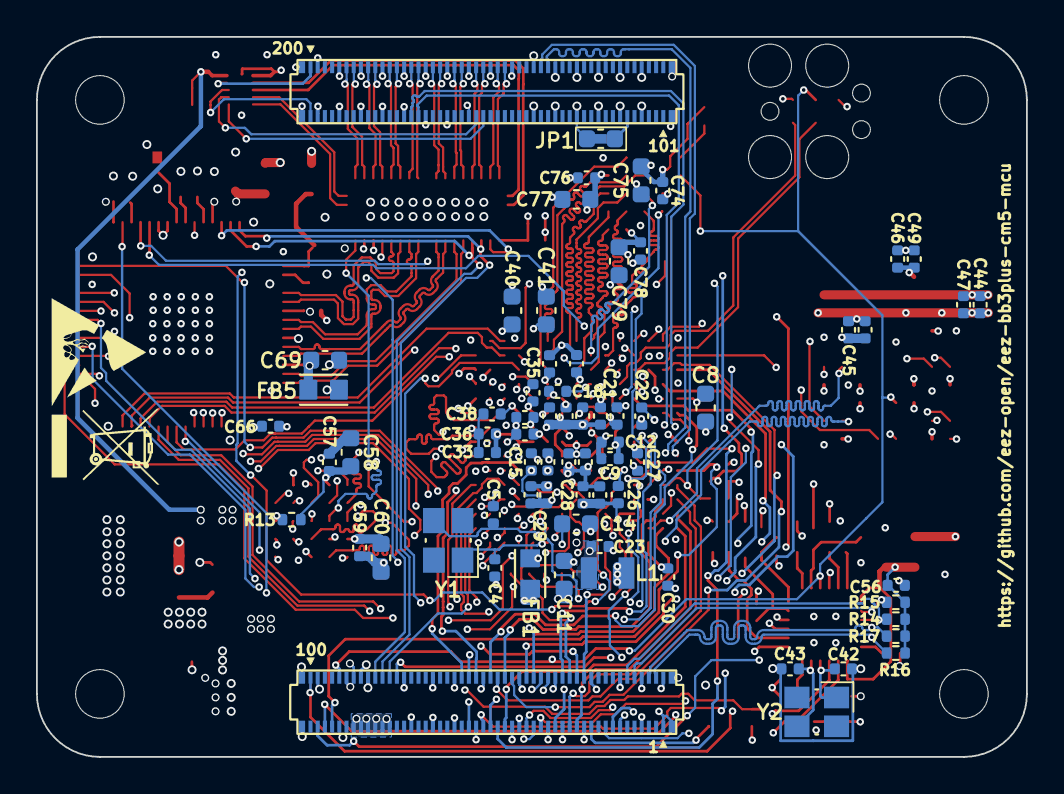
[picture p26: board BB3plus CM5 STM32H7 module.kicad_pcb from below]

Board: 6 copper layers, 55.0 x 40.0 mm, 140 parts (72 on the bottom side), 201 nets.

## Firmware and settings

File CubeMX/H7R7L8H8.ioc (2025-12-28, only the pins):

Mcu.UserName=STM32H7R7L8HxH
PA0.Signal=LTDC_G3
PA1.Signal=LTDC_G2
PA10.Signal=LTDC_B4
PA11.Signal=LTDC_B3
PA12.GPIO_Label=DIB1/DIB3_SCK
PA12.Signal=SPI2_SCK
PA13(JTMS/SWDIO).GPIO_Label=SWDIO
PA13(JTMS/SWDIO).Signal=DEBUG_JTMS-SWDIO
PA14(JTCK/SWCLK).GPIO_Label=SWCLK
PA14(JTCK/SWCLK).Signal=DEBUG_JTCK-SWCLK
PA15(JTDI).Signal=LTDC_R5
PA2.Signal=ETH_MDIO
PA3.Signal=LTDC_DE
PA4.Signal=LTDC_R3
PA5.Signal=LTDC_CLK
PA6.Signal=LTDC_B7
PA7.Signal=ETH_RMII_CRS_DV
PA8.Signal=LTDC_B6
PA9.Signal=LTDC_B5
PB0.GPIO_Label=DVID_SEL1
PB0.Signal=GPIO_Output
PB1.GPIO_Label=DIB1_IRQ
PB1.Signal=GPXTI1
PB10.Signal=ETH_MII_RX_ER
PB11.Signal=LTDC_G6
PB12.Signal=LTDC_G5
PB13.Signal=LTDC_G4
PB14.GPIO_Label=RS485_TX_EN/DOUT2
PB14.Signal=UART4_DE
PB15.Signal=LTDC_G7
PB2.Signal=LTDC_B2
PB3(JTDO/TRACESWO).Signal=LTDC_R4
PB4(NJTRST).GPIO_Label=DIB1_CSA
PB4(NJTRST).Signal=SPI2_NSS
PB5.Signal=LTDC_R2
PB6.GPIO_Label=DVID_CEC
PB6.Signal=CEC
PB7.Signal=ETH_RMII_TXD1
PB8.Signal=SDMMC1_D4
PB9.Signal=SDMMC1_D5
PC1.Signal=ETH_MDC
PC10.Signal=SDMMC1_D2
PC11.Signal=SDMMC1_D3
PC12.Signal=SDMMC1_CK
PC14-OSC32_IN(OSC32_IN).Signal=RCC_OSC32_IN
PC2.GPIO_Label=DIB1/DIB3_MISO
PC2.Signal=SPI2_MISO
PC3.GPIO_Label=DIB1/DIB3_MOSI
PC3.Signal=SPI2_MOSI
PC4.Signal=ETH_RMII_RXD0
PC5.Signal=ETH_RMII_RXD1
PC6.Signal=SDMMC1_D6
PC7.Signal=SDMMC1_D7
PC8.Signal=SDMMC1_D0
PC9.Signal=SDMMC1_D1
PD0.GPIO_Label=RS485_RX/DIN3
PD0.Signal=UART4_RX
PD1.GPIO_Label=RS485_TX/DOUT3
PD1.Signal=UART4_TX
PD14.GPIO_Label=USB_FS_SEL
PD14.Signal=GPIO_Output
PD2.Signal=SDMMC1_CMD
PD3.Signal=LTDC_B1
PD5.GPIO_Label=DIB5_IRQ
PD5.Signal=GPXTI5
PD6.Signal=ETH_CLK
PD7.Signal=ETH_RMII_REF_CLK
PE0.GPIO_Label=SYSMCU_IRQ
PE0.Signal=GPXTI0
PE10.GPIO_Label=LED_nACT
PE10.Signal=GPIO_Output
PE11.Signal=LTDC_VSYNC
PE12.GPIO_Label=DVID_HPA
PE12.Signal=GPXTI12
PE13.GPIO_Label=DIB2/DIB5_MISO
PE13.Signal=SPI4_MISO
PE14.GPIO_Label=DIB2/DIB5_MOSI
PE14.Signal=SPI4_MOSI
PE15.GPIO_Label=LCD_ON
PE15.Signal=GPIO_Output
PE2.GPIO_Label=DIB2/DIB5_SCK
PE2.Signal=SPI4_SCK
PE4.GPIO_Label=DIB2_CSA
PE4.Signal=SPI4_NSS
PE6.GPIO_Label=DIB5_CSA
PE6.Signal=GPIO_Output
PE7.GPIO_Label=UART_RX/DIN1
PE7.Signal=UART7_RX
PE8.GPIO_Label=TFT_IRQ
PE8.Signal=GPXTI8
PF0.GPIO_Label=SDA
PF0.Signal=I2C2_SDA
PF1.GPIO_Label=SCL
PF1.Signal=I2C2_SCL
PF10.Signal=LTDC_R1
PF11.Signal=LTDC_B0
PF13.GPIO_Label=DVID_SEL2
PF13.Signal=GPIO_Output
PF14.Signal=LTDC_G0
PF15.GPIO_Label=DIB4_SCK
PF15.Signal=SPI5_SCK
PF2.GPIO_Label=DIB2_IRQ
PF2.Signal=GPXTI2
PF3.GPIO_Label=DIB3_IRQ
PF3.Signal=GPXTI3
PF4.GPIO_Label=DIB4_IRQ
PF4.Signal=GPXTI4
PF6.GPIO_Label=DIB4_CSA
PF6.Signal=SPI5_NSS
PF7.GPIO_Label=UART_TX/DOUT1
PF7.Signal=UART7_TX
PF9.Signal=LTDC_R0
PG0.Signal=LTDC_R7
PG1.Signal=LTDC_R6
PG11.Signal=ETH_RMII_TX_EN
PG12.Signal=LTDC_G1
PG13.Signal=ETH_RMII_TXD0
PG14.GPIO_Label=SYSMCU_CS
PG14.Signal=GPIO_Output
PG2.Signal=LTDC_HSYNC
PG3.GPIO_Label=DIB_OE_SYNC
PG3.Signal=GPIO_Output
PH0-OSC_IN(PH0).Signal=RCC_OSC_IN
PH1-OSC_OUT(PH1).Signal=RCC_OSC_OUT

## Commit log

2025-11-02 BOM update
    [BB3plus CM5 STM32H7 module.kicad_pcb, BB3plus CM5 STM32H7 module.ods, Ethernet_flash.kicad_sch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]
2025-11-03 CEC and HPD signals fixed
    [BB3-CM5 pinout (H7R7).ods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]
2025-11-03 PCB layout improvement
    [BB3plus CM5 STM32H7 module-B_Cu.gbl, BB3plus CM5 STM32H7 module-B_Mask.gbs, BB3plus CM5 STM32H7 module-B_Paste.gbp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]
2025-11-03 BOM update, PCB layout improvements, NetTie positions fixed
    [BB3plus CM5 STM32H7 module-B_Cu.gbl, BB3plus CM5 STM32H7 module-B_Mask.gbs, BB3plus CM5 STM32H7 module-B_Paste.gbp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]
2025-11-11 Removed all blind/burned vias
    [BB3plus CM5 STM32H7 module-B_Cu.gbl, BB3plus CM5 STM32H7 module-B_Mask.gbs, BB3plus CM5 STM32H7 module-B_Paste.gbp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]
2025-11-23 DIN3 pin assigned
    [BB3-CM5 pinout (H7R7).ods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]
2025-11-24 ETH clk fixed, digital I/O naming updated
    [BB3-CM5 pinout (H7R7).ods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]
2025-11-28 RTC input added
    [BB3-CM5 pinout (H7R7).ods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]
2025-12-22 #1, #2, #3
    [BB3-CM5 pinout (H7R7).ods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]
2026-01-17 Eth PHY straps updated
    [BB3plus CM5 STM32H7 module-B_Cu.gbl, BB3plus CM5 STM32H7 module-B_Mask.gbs, BB3plus CM5 STM32H7 module-B_Paste.gbp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]
2026-01-17 Schematics update
    [Ethernet_flash.kicad_sch, eth_psram_emmc.kicad_sch]

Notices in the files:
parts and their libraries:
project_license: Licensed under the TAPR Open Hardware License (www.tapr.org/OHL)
